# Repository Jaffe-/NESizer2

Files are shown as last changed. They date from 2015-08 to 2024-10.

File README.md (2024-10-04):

NESIZER

## NESizer2: 2A03 Synthesizer Project



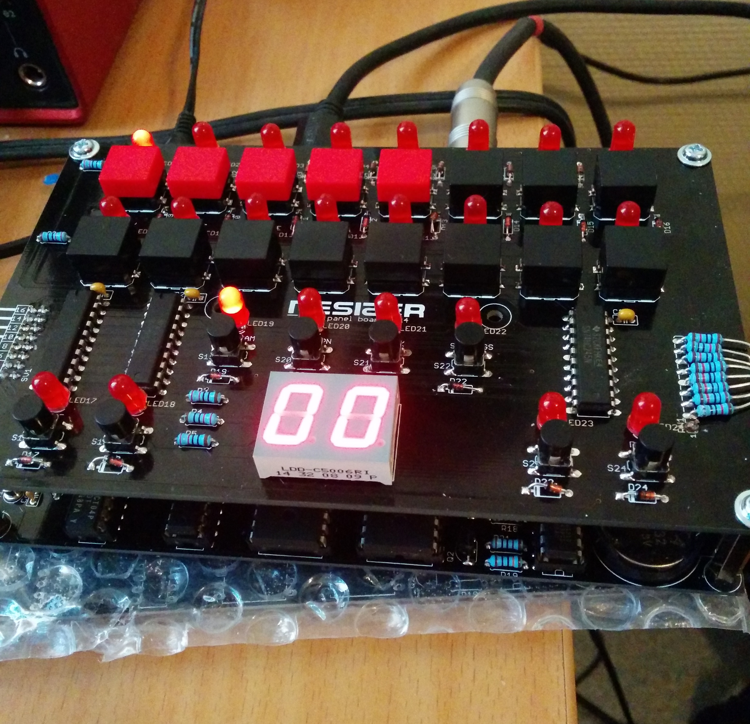
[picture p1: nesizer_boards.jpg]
NESIZER


The main idea of this project is to use an isolated NES 2A03 CPU/APU IC as a stand-alone synthesizer, controlled by an Atmel Atmega microcontroller. (The project is named NESizer2 after a failed attempt to create a NES synthesizer using only the 2A03 alone, with its own ROM, RAM and I/O logic.)

The 2A03 IC consists of a 6502 CPU core (with some minor changes), a DMA controller and the Audio Processing Unit. The APU is controlled via 22 registers, which are connected internally to the 6502 only; there are no external input pins facilitating communication with the APU directly. This means that in order to control the APU, the 6502 must act as a proxy: The microcontroller must send the 6502 instructions to take a value and put it in a desired APU register.

This project is inspired by a similar approach taken here: http://www.soniktech.com/tsundere/, but the idea here is to have the microcontroller communicate more directly with the 2A03, with a minimum of circuitry to do so.

Check out the most recent demo [here](https://www.youtube.com/watch?v=pXKrs0bFvvk)!

See the documentation for a description of how the NESizer works:

- [Hardware documentation](docs/hardware.md)
- [Software documentation](docs/software.md)

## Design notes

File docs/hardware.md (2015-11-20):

## Hardware

The following images shows the most current schematics.

Main board:
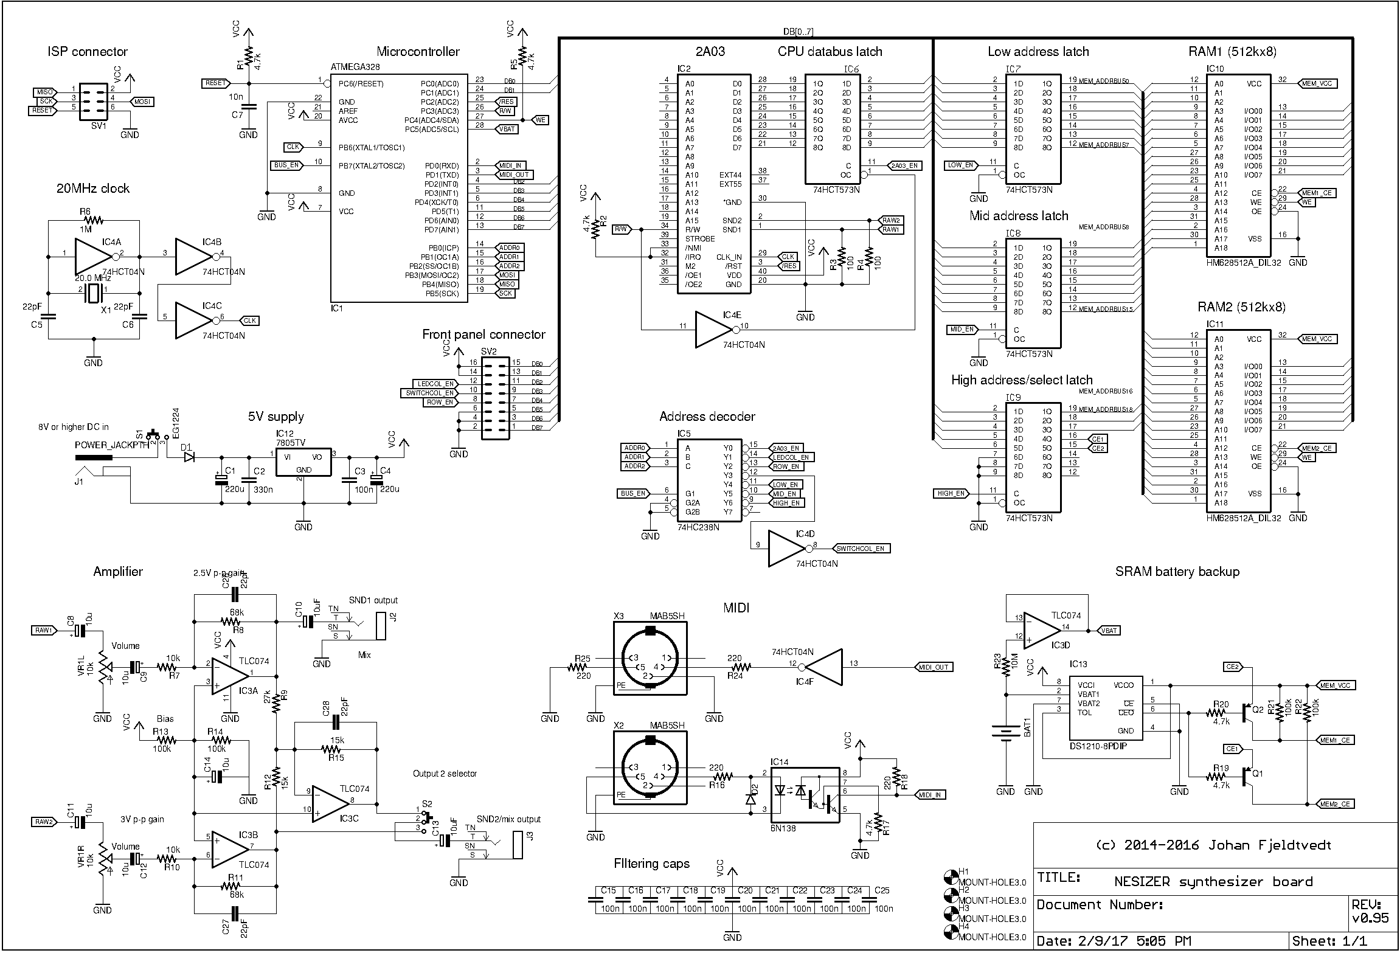
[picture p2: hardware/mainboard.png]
Main board


Front panel board:
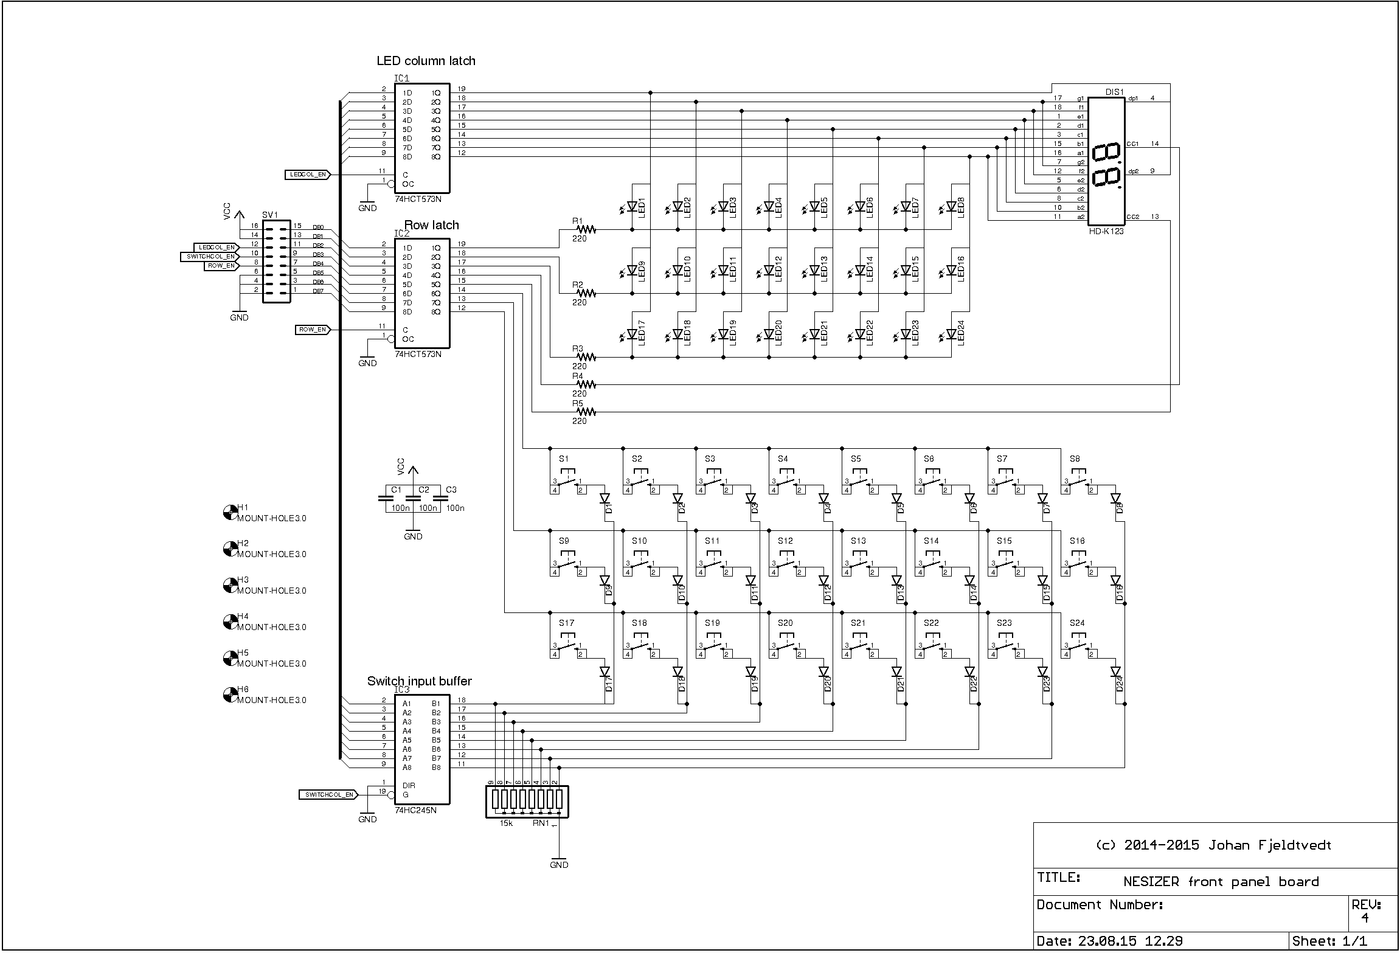
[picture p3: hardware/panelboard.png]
Panel board


The circuit essentially consists of the following parts:

- Atmega328 microcontroller
- 2A03
- LED matrix
- Switch matrix
- Battery backed SRAM
- Analog signal amplifier

#### Communication

The Atmega accesses the 2A03, LED matrix, switch matrix and SRAM through a simple bus system consisting of a 3-bit address bus and an 8-bit data bus. Bits 0, 1 and 2 of **PORTB** are used as the address, while bits 0 and 1 of **PORTC** and bits 2 to 7 of **PORTD** are connected to the data bus. The odd choice of combining some bits from **PORTC** with some bits of **PORTD** is because bits 0 and 1 of **PORTD** are used by the USART which takes care of MIDI communication. A 74HC238 decoder is used to decode the 3-bit address into one of eight activation signals for each component. The addresses are decoded as follows (R and W indicate read or write direction, respectively):

- 0: 2A03 data bus (W) 
- 1: LED matrix column (W)
- 2: matrix row for both LED and switch matrices (W)
- 3: switch matrix column (R)
- 4: memory, low 8 bits of address (W)
- 5: memory, middle 8 bits of address (W)
- 6: memory, high 3 bits of address and chip select bits (W)

Each writable component is connected to the databus via a latch in order to store the value when the bus is being used for something else.

#### 2A03 setup

Both the Atmega and the 2A03 are clocked by a 20 MHz crystal oscillator circuit based on 74HC04 inverters. The 2A03 divides this clock by 12 internally to provide a 1.66 MHz clock for the 6502 and APU. This is a bit lower than the usual frequency for the 2A03 (1.79 MHz), but it has no serious impact on APU operation (the APU timer values needed to produce a given note become a bit different).

The Atmega is hooked up to the 2A03 using the following connections:

- **PD2** .. **PD7**  --->  74HC573 latch ---> **D2** .. **D7** on 2A03 
- **PC0** .. **PC1**  --->  74HC573 latch ---> **D0** .. **D1** on 2A03
- **PC2**  --->  **RESET** pin on 2A03
- **PC3**  <---  **R/W** pin on 2A03

The reset connection could possibly be omitted (and the 2A03 reset pin just connected to a standard reset circuit), but connecting it to the Atmega allows for the 2A03 to be reset at any time, which might be handy in case the 6502 should halt.

The **R/W** output from the 2A03 is necessary to synchronize with the CPU.

In addition to the connections to the Atmega, some other connections are necessary for the 2A03 to function properly:

- **/NMI** and **/IRQ** are pulled high to avoid interrupts disturbing the 6502
- Pin 30 (diagonistics pin) is pulled low
- **SND1** and **SND2** (APU outputs) are pulled low via 100 ohm resistors

The 100 ohm pull-down resistors on **SND1** and **SND2** are required for the DACs in the APU to function properly. (This also has the effect that the output signals are very weak.)

Apart from this and the usual power supply connections, there are no further connections made. The address bus and the gamepad inputs/outputs are simply left unconnected. 

#### LED and switch matrices

These are both pretty standard. The LED matrix is a column scan matrix with 8 columns and 5 rows. 

The switch matrix is a row scan matrix with 8 columns and 3 rows. The lower five bits of a 74HC573 latch are used to hold the selected LED row, and the upper three bits are used to hold the selected switch row. This latch is accessed through the data bus by selecting address 2. 

The LED column is specified by writing to a 74HC573 latch connected to the data bus and selected with address 1. (Note that in order to light an LED at row *x* and column *y*, a 1 must be written at bit position *y* in the column latch, while a 0 must be written to bit position *x* of the row latch. This is because the column latch is sourcing the current while the row latch is sinking it.) 

Reading a switch state is done by activating the correct row in the row latch, and then selecting address 3 and reading from the bus. 

#### Battery backed SRAM memory

There are two SRAM ICs of 512KByte each, thus a 20 bit address is needed to address each individual byte (1MB in total). Since the databus is only 8 bit wide, three latches are used to specify an address before reading or writing to memory. The lowest 8 bits are written to the latch at databus address 4, the next 8 bits to the latch at address 5, and the next three bits to the latch at address 6. This totals to 19 bits, enough to address any byte in one of the ICs. The desired chip is selected by the upper two bits of the high address latch, where a value of 0b10 selects the first, 0b01 the other, and 0b11 neither. 

The write enable (/WE) line of the SRAM ICs is connected to pin 4 of **PORTC**. This pin must be kept high at all times except when a write is to performed. When an address is set up and a desired value is put on the databus, this pin is pulled low and thereafter pulled high to write the value to the address in memory. 

The SRAM ICs will retain their data as long as their supply voltage is larger than 1.5 V and the chip select lines are held high. The battery backup circuit takes care of this. A constant supply voltage is supplied by either a 3 V coin cell battery, or the regulated 5 V supply when the NESizer is powered on. The supplies are connected through diodes to prevent the 5 V supply from being applied to the battery, and to minimize the current flowing out of the battery when the 5 V supply is off.

A simple transistor switch circuit is used to force the chip select lines high when the 5 V supply is turned off. R19 and R20 set up a resistive divider giving a base voltage of the transistors that is about 0.15 * VCC. Assuming a typical VBE drop of 0.6 V, this gives a threshold of about 4 V for the transistor to start turning on. The pullups R21 and R22 ensure that the chip enable outputs are tied to MEM_VCC when the transistors are off. As the transistors are turned on, the outputs will follow the inputs closely, with a small drop between the emitter and collector.

#### MIDI

The MIDI input circuit is the standard circuit suggested in the MIDI standard, using an optocoupler (6N138) to isolate the MIDI current loop from the circuit. The incoming signal goes to the RX input of the Atmega's USART.

#### Output audio path

There are two identical output paths for the two 2A03 sound outputs, and a mixer that mixes the two audio signals with approximately the same ratio as in the NES.

The signal is AC-coupled by C8, C11 to the volume potentiometers set up as voltage dividers (VR1L, VR1R). The AC coupling is necessary to avoid noises when turning the volume potentiometers. It is then AC coupled by C9, C12 in to the virtual ground of an inverting amplifier with a gain of -6.8 set up by R8/R7 and R11/R10.  The non-inverting input of the op-amps IC3A, IC3B is set by a voltage divider to 2.5 V, so the output voltage is 2.5 V - 6.8 * v_in. In the feedback loop capacitors C26, C27 stabilize and also set the upper corner frequency of the bandwidth. The mix is done by passively summing the two resulting signals at the virtual ground of a third inverting amplifier. This ensure minimal crossbleed between the two output paths.

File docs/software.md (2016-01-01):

## Software

#### Databus communication

`bus.h` contains utility macros for using the bus system. The target component is adressed using `bus_select(<address>)`. A value is put on the bus using `bus_write(<value>)`. Changing bus direction to input or output is done by `bus_dir_input()` and `bus_dir_output()`, respectively. Values are read from the bus using `bus_read()`. `bus_deselect()` will disable the currently selected component.

`bus.h` also defines names for the adresses:

* 2A03: `CPU_ADDRESS`
* LED column: `LEDCOL_ADDRESS`
* Row (for both LEDs and switches): `ROW_ADDRESS`
* Switch column: `SWITCHCOL_ADDRESS`
* SRAM low address: `MEMORY_LOW_ADDRESS`
* SRAM mid address: `MEMORY_MID_ADDRESS`
* SRAM high address: `MEMORY_HIGH_ADDRESS`

The bus system must be initialized with `bus_setup()` before first time use.

#### Communication with the 2A03

The 2A03 is kept idle by continuously holding 0x85, the opcode for `STA` (with zero page addressing), on the databus. The CPU thus continuously executes an `STA $85` instruction. 

The reason for using this opcode instead of the more obvious `NOP` is to be able to synchronize with the CPU when a new instruction is to be sent. This synchronization is done by monitoring the **R/W** line of the 2A03. When it goes low, the 6502 is writing to memory. This *only* happens when the `STA $85` instruction is in its third cycle, which means that the next cycle will be the fetch of the next opcode. The Atmega then has a very narrow window to prepare and write the values to the 6502. Because of the precision needed, this is done by cycle exact assembly code in `2a03_io.s`.

Writing to APU registers is done by calling the function `io_register_write`. It selects the 2A03 address, blocks any interrupts and calls the assembly function `register_setN`, where N is one of three possible 2A03 clock divisors (12, 15 or 16, more about this below). This function makes the 6502 perform the following series of instructions:

    LDA #VALUE		0xA9 VALUE
    STA $40RR		0x8D 0xRR 0x40

where 0xRR is the low byte of the register address to be written to. At the end, `register_setN` puts the `STA` zero page opcode (0x85) back on the bus to keep the CPU busy until the next time something needs to be written.

There are also functions `reset_pcN` and `disable_interruptsN` in `2a03_io.s` for resetting the `PC` register and disabling interrupts on the 6502, respectively. `disable_interruptsN` executes an `SEI` instruction on the 6502 and is done once on boot. `reset_pcN` executes a `JMP $8585` instruction. It is called periodically to make sure that the 6502's program counter (`PC` register) doesn't overflow and run into the addresses where the APU registers are mapped (in which case APU register contents will be interpreted as instructions).

##### Different 2A03 varieties

The NESIZER supports three different kinds of chips: 2A03, 2A07 (PAL version) and Dendy clones. The most critical difference is the internal clock divider used: The 2A03 divides its clock input by 12, while the 2A07 divides by 16 and the Dendy clones by 15. An assembly function `detect` is used to determine which type of chip is being used. It puts an `STA` instruction with absolute addressing on the bus and uses one of the Atmega's timers to count how long two such instructions take to execute. The timer is being clocked by the Atmega's main clock, so its value will be proportional to how many Atmega cycles each 6502 cycle takes. Since two `STA` instructions with absolute addressing take 8 6502 cycles to complete, dividing the timer's value by 8 yields how many Atmega cycles there are in one 6502 cycle.

When the NESIZER boots, `detect` is run, and the result is used to make the function pointers `register_set`, `reset_pc` and `disable_interrupts` point to the correct functions in `2a03_io.s`. It is also used to select which table of timer values to use in `periods.c`.

#### Calculating period values for APU channels

This is detailed in [periods.pdf](periods.pdf).

#### APU abstaction layer

The APU abstraction layer (`apu`) contains structs and functions for manipulating the 2A03 channels in a high level manner without having to deal with register writes manually. The channels are represented by structs having fields corresponding to each (used/interesting) parameter of the channel. 

Each channel type is represented by a struct, `square`, `triangle`, `noise` and `dmc`, respectively. Global objects `sq1`, `sq2`, `tri`, `noise` and `dmc` of corresponding types are defined. Each channel has a setup function named `<channel>_setup`, intended for initializing the struct, and an update function `<channel>_update` which takes the data in a struct and fills the appropriate registers in a register buffer. The function `apu_refresh_channel` takes the data for a given channel in the register buffer and writes them to the 2A03. This function updates one channel's registers at a time, so it needs to be called 5 times to update all registers. This is necessary to reduce time spent on register updates.

The abstraction makes producing sound easy: 

	int main() 
	{
		// Initialize 2A03:
		io_setup();
		
		// Initialize Square 1 channel:
		sq1_setup();
		
		// Set the values for period, duty cycle and volume:
		sq1.enabled = 1;
		sq1.period = 400;
		sq1.duty = 2;
		sq1.volume = 15;
		
		// Update APU register buffer with new square 1 values:
		sq1_update();
		
		// Transfer changes to the APU:
		apu_refresh_channel(CHN_SQ1);
		
		// Wait indefinitely
		while(1);
	}

#### Interrupt timing and task handler

One of the Atmega's timers is used to generate an interrupt at approximately 16 kHz. This interrupt provides the basic timing used by various subsystems (LFOs, envelopes, APU updates, etc.).

A simple task handler (`task.h`, `task.c`) is used to sequence tasks to be performed. Tasks are registered with a desired frequency and a time delay to spread tasks out in time. 

#### LEDs and switches

These are handled in `leds.c`, `leds.h` and `input.c`, `input.h`. 

LED states are held in a 5 byte array `leds`. The function `leds_refresh` is intended to be registered as a task, and will update one column of the LED array each time it is called. It is intended to be run often enough for the sequential updating to happen unnoticed. 

Switch states are held in a 3 byte array `input`. The function `input_refresh` reads one row of switch data at a time and updates `input` accordingly. It is intended to be registered as a task and executed often enough for input to be seamless. 

#### SRAM

Functions for using the SRAM are available in `memory.c`, `memory.h`. Even though addresses are represented by 19 bits and two bits for chip selection at the hardware level, these details are glossed over by the software memory interface; an address is 20 bits, giving a total address space of 0 - 0xFFFFF. The internal function `set_address` translates a 20-bit address to the corresponding 19 bits and chip select bits.

The functions `memory_write()` and `memory_read()` are used to read and write bytes, while corresponding functions `read_word`, `read_dword`, `write_word` and `write_dword` are used to read or write 16- and 32-bit values. 

##### Sequential access

In order to reduce the time spent on memory operations, especially when playing back samples, a memory address can be set once using `memory_set_address()` and then values can be read or written sequentially using `memory_read_sequential()` and `memory_write_sequential()`, with as few address updates as possible (most often only the 8 lowest bits need to be changed). To make this work with several tasks using the memory, each task doing sequential memory access has to keep their own *memory context*, an object of type `struct memory_context`, whici holds the three (low, middle, high) memory latch bytes. `memory.c` keeps track of the last used memory context, so that when `memory_read_sequential` or `memory_write_sequential` is called, it makes sure that the task continues its memory access where it left off even if some other task changed the address in between. 

#### MIDI

Low level MIDI communication is implemented in `midi_io.c`, `midi_.h`. The Atmega's USART takes care of receiving MIDI data. In the function `midi_io_setup`, the USART is configured to use 1 start bit, 8 data bits and 1 stop bit, and to use a baud rate of 31250, which is the MIDI standard baud rate. 

The function `midi_io_handler` is intended to be registered as a task handler. It checks the state of the Atmega's USART receive buffer and reads new data into a ring buffer. 

Reading and interpreting the data is done by the functions in `midi.c`, `midi.h`.

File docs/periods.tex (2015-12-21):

\documentclass{article}
\usepackage[utf8]{inputenc}
\usepackage{listings}
%\usepackage[T1]{fontenc, url}
\usepackage[parfill]{parskip}

\setlength{\parindent}{0pt}

\title{NESIZER: Period calculations}
\date{}

\begin{document}

\maketitle

This document describes how period calculations are done effectively in the NESIZER code.

\section*{Note representation}

A \emph{note} is represented by a 16-bit value of the following struct (it is wrapped in a union to allow writing a raw value directly):

\begin{lstlisting}[language=C]
union tone {
  uint16_t raw_value;
  struct { 
    uint8_t offset : 6;
    uint16_t semitone : 10;
  } __attribute__((packed));
};
\end{lstlisting}

The upper 10 bits are used to represent the semitone, while the lower 6 bits represent the \emph{offset} from this semitone towards the next. The resulting frequency is given by

\begin{equation}
  f = f_{s} \cdot 2^{\frac{1}{12} \cdot \frac{o}{64}},
\label{eq_repr}
\end{equation}
where $f_s$ is the semitone's frequency and $o$ is the offset. 

\section*{Calculating timer values}

The formula used for calculating timer values from this note representation is based on the following relationship between timer values and resulting frequencies in the pitched APU channels:

$$f = \frac{f_{cpu}}{16 \alpha (T + 1)},$$

where $\alpha = 1$ for square channels and $\alpha = 2$ for the triangle channel. This relationship comes directly from the fact that each timer countdown advances one step of the generated waveform, and square waves take 16 steps while triangle waves take 32 steps.  

Solving this for $T$, we get
$$T = \frac{f_{cpu}}{16 \alpha f} - 1.$$

Inserting the relationship in (\ref{eq_repr}), we get

\begin{eqnarray*}
  T &=& \frac{f_{cpu}}{16 \alpha f_{s} \cdot 2^{\frac{1}{12} \cdot \frac{o}{64}}} - 1\\
  &=& \frac{f_{cpu}}{16 \alpha f_s} \cdot 2^{-\frac{1}{12} \cdot \frac{o}{64}} - 1\\
  &=& (T_s + 1) \cdot 2^{-\frac{1}{12} \cdot \frac{o}{64}} - 1.
\end{eqnarray*}

From here we see that $T_s$ -- the timer value required to give the semitone with frequency $f_s$ -- can easily be looked up in a table. To calculate the power of 2, a simple linear approximation has been found to be good enough:

$$2^{-\frac{1}{12} \cdot \frac{o}{64}} = [2^{-\frac{1}{12}}]^{\frac{o}{64}} \approx 1 - (1 - 2^{-\frac{1}{12}}) \cdot \frac{o}{64} \approx 1 - 0.00087696 \cdot o.$$

Using this approximation in the above expression for $T$, we get

$$T = (T_s + 1) (1 - 0.00087696 \cdot o) - 1.$$

This only involves one floating point multiplication and performes very well. 

\end{document}

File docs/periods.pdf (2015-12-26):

# NESIZER: Period calculations

This document describes how period calculations are done effectively in the NESIZER code.

## Note representation

A note is represented by a 16-bit value of the following struct (it is wrapped in a union to allow writing a raw value directly):

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

The upper 10 bits are used to represent the semitone, while the lower 6 bits represent the offset from this semitone towards the next. The resulting frequency is given by

| | f = fs · 2

1
12 ·

o
64 , | (1)

where fs is the semitone’s frequency and o is the offset.

## Calculating timer values

The formula used for calculating timer values from this note representation is based on the following relationship between timer values and resulting frequencies in the pitched APU channels:

f =

fcpu
16α(T + 1),

1

where α = 1 for square channels and α = 2 for the triangle channel. This relationship comes directly from the fact that each timer countdown advances one step of the generated waveform, and square waves take 16 steps while triangle waves take 32 steps.

Solving this for T, we get

T =

fcpu
16αf − 1.

Inserting the relationship in (1), we get

T =

fcpu
16αfs · 2

1
12 ·

o
64

− 1

=

fcpu
16αfs
- 2

− 1
12 ·

o
64 − 1

= (Ts + 1) · 2

− 1
12 ·

o
64 − 1.

From here we see that Ts – the timer value required to give the semitone with frequency fs – can easily be looked up in a table. To calculate the power of 2, a simple linear approximation has been found to be good enough:

2

− 1
12 ·

o

64 = [2⁻ 1
12 ]

o
64 ≈ 1 − (1 − 2

− 1
12 ) ·

o
64

≈ 1 − 0.00087696 · o.

Using this approximation in the above expression for T, we get

T = (Ts + 1)(1 − 0.00087696 · o) − 1.

This only involves one floating point multiplication and performes very well.

2

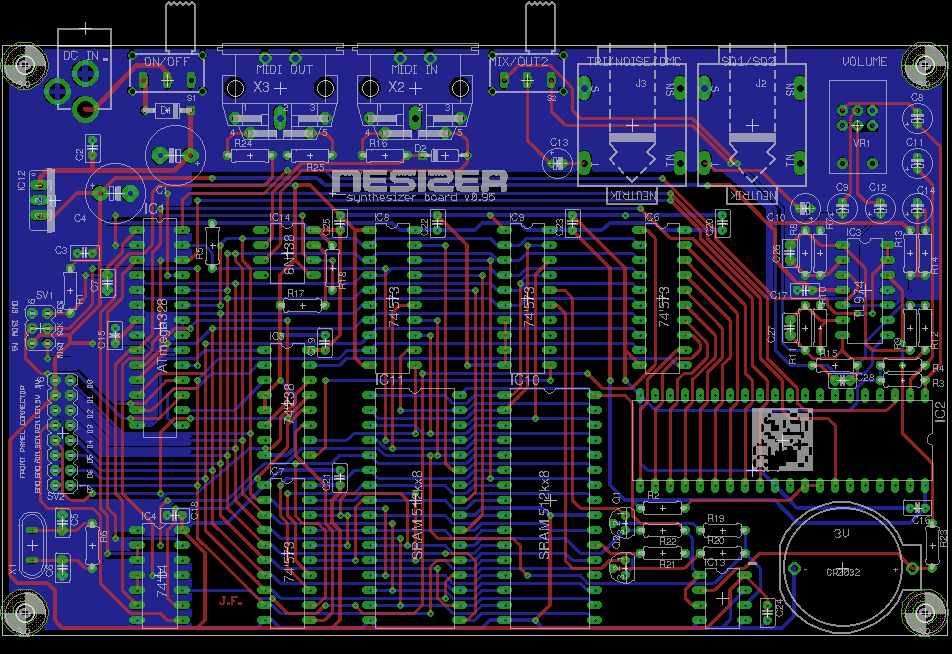
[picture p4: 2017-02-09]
hardware/mainboard_pcb.png

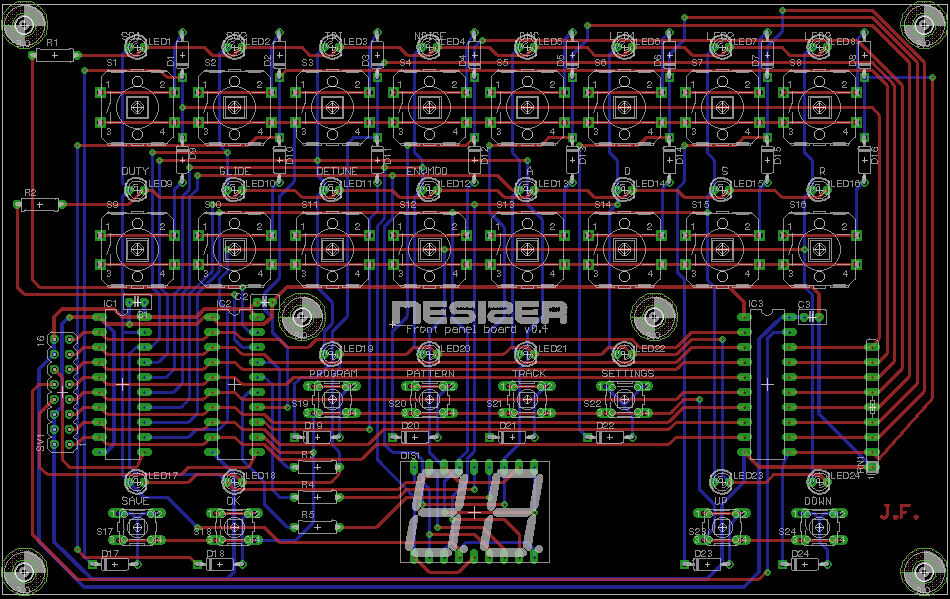
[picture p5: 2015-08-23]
hardware/panelboard_pcb.png

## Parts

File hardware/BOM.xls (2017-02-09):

Main board
Identifier | Component | Value | Qty | Comments | Mouser part
BAT1 | Battery holder |  | 1 | CR2032 | 122-2420-GR
C1, C4 | Electrolytic capacitor | 220u | 2 |  | 647-UPW1H221MPD
C2 | Capacitor | 330n | 1 |  | 75-1C20Z5U334M050B
C3, C15 – C25 | Capacitor | 100n | 12 |  | 75-1C10Z5U104M050B
C5, C6, C26 – C28 | Ceramic capacitor | 22p | 5 |  | 594-CN15A220J
C7 | Capacitor | 10n | 1 |  | 75-1C10Z5U103M050B
C8 – C14 | Electrolytic capacitor | 10u | 7 |  | 647-UKW1H100MDD
D1 | 1N4001 |  | 1 | Power diode | 625-1N4001E-E3/54
D2 | 1N4148 |  | 1 | Switching diode | 78-1N4148
IC1 | Atmega328 |  | 1 | Microcontroller | 556-ATMEGA328P-PU
IC2 | 2A03/2A07/6527P |  | 1 | 2A03/2A07 or clone
IC3 | TLC074 |  | 1 | Should have high Zin | 595-TL974IN
IC4 | 74HC04N |  | 1 | Hex inverter | 595-SN74HC04N
IC5 | 74HC238N |  | 1 | Address decoder | 595-CD74HC238EE4
IC6 – IC9 | 74HC573N |  | 4 | Latch | 595-SN74HC573AN
IC10, IC11 | AS6C4008 |  | 2 | 512k x 8 SRAM | 913-AS6C4008-55PCN
IC12 | LM7805 |  | 1 | Voltage regulator | 511-L7805CV
IC12 | Heatsink for LM7805 |  | 1 |  | 532-574102B00
IC13 | DS1210 |  |  | NV memory controller | 700-DS1210
IC14 | 6N138 |  | 1 | Optocoupler | 859-6N138M
J1 | DC jack 2.5mm |  | 1 |  | 163-7620E-E
J2, J3 | Mono jack 6.3mm |  | 2 |  | 550-10201
R1, R2, R5, R17, R19, R20 | Resistor | 4.7k | 6 |  | 594-MBB02070C4701FCT
R3, R4 | Resistor | 100 | 2 |  | 594-MBB02070C1000FCT
R6 | Resistor | 1M | 1 |  | 594-MBB02070C1004FCT
R7, R10 | Resistor | 10k | 2 |  | 594-MBB02070C1002FCT
R8, R11 | Resistor | 68k | 2 |  | 594-MBB02070C6802FCT
R9 | Resistor | 27k | 1 |  | 594-MBB02070C2702FC1
R12, R15 | Resistor | 15k | 2 |  | 594-MBB02070C1502FCT
R13, R14, R21, R22 | Resistor | 100k | 4 |  | 594-MBB02070C1003FCT
R16, R18, R24, R25 | Resistor | 220 | 4 |  | 594-MBB02070C2200FCT
R23 | Resistor | 10M | 1 |  | 594-MBB02070C1005FCT
S1, S2 | EG1224 |  | 2 | Slide switch | 612-EG1224
SV1 | 2x3 header |  | 1 | 2.54mm spacing | 517-9612065604AR
SV2 | 2x8 header |  | 1 | 2.54mm spacing | 649-68602-116HLF
SV2 | 8x1 header pins |  | 2 | Extensions to reach top board | 992-8FX1L-254MM
Q1, Q2 | BC557 or equivalent |  | 2 | PNP transistor | 512-BC557BTA
VR1 | Potentiometer | 10k | 1 | Audio taper | 688-RK09712200MC
X1 | Crystal | 20MHz | 1 |  | 815-ABL-20-B2
X2, X3 | MIDI socket |  | 2 |  | 502-57PC5F
 | 25mm spacers |  | 4 | Supports for top board | 855-R30-9402500
 | M3 screws |  | 8 | Screws for top board | 608-RM3X8MM
Extras
IC1 | 28 pin IC socket |  | 1 |  | 575-199328
IC2 | 40 pin IC socket |  | 1 |  | 517-4840-6000-CP
IC3, IC4 | 14 pin IC socket |  | 2 |  | 517-4814-3000-CP
IC5 | 16 pin IC socket |  | 1 |  | 517-4816-3000-CP
IC6 – IC9 | 20 pin IC socket |  | 4 |  | 517-4820-3000-CP
IC10, IC11 | 32 pin IC socket |  | 2 |  | 517-4832-6000-CP
IC14 | 8 pin IC socket |  | 2 |  | 517-4808-3000-CP
Top / front panel board
Identifier | Component | Value | Qty | Comments | Mouser part
C1 – C3 | Capacitor | 100n | 3 |  | 75-1C10Z5U104M050B
D1 – D24 | 1N4148 |  | 24 | Switching diode | 78-1N4148
DIS1 | 7-segment display |  | 1 | Two digits, common cathode | 696-LDD-C5006RI
IC1, IC2 | 74HC573N |  | 2 | Latch | 595-SN74HC573AN
IC3 | 74HC245N |  | 1 | Buffer / bus driver | 595-SN74HCT245N
LED1 – LED24 | 3mm LED |  | 24 |  | 696-LX3044ID-24117
R1 – R5 | Resistor | 220 | 5 | Adjust for LED current | 594-MBB02070C2200FCT
RN1 | 8x resistor array, bussed | 15k | 1 |  | 858-L091S472LF
S1, S16 | Omron B3F 12mm switch |  | 16 | With plunger top | 653-B3F-4050
S17 – S24 | Omron B3f 6mm switch |  | 8 | With plunger top | 653-B3F-1050
SV1 | 8x2 female header |  | 1 | Mount on underside of PCB! | 517-929975-01-08-RK
Extras
IC1 – IC3 | 20 pin IC socket |  | 3 |  | 517-4820-3000-CP
S1 – S5 | 12mm square cap, red |  | 5 | For channel buttons | 653-B32-1380
S6 – S16 | 12mm square cap, black |  | 11 | For parameter buttons | 653-B32-1310
S17 – S24 | 6mm round cap, black |  | 8 | For up/down, mode, etc. | 653-B32-2010

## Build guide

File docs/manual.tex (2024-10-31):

\documentclass[a4paper, 12p]{extarticle}
\usepackage[centering, margin=3.0cm]{geometry}
\usepackage{cmbright}
\usepackage{graphicx}
\usepackage[intlimits]{amsmath}
\usepackage{amssymb}
\usepackage{amsthm}
\usepackage{parskip}
\usepackage{pgf}
\usepackage{tikz}
\usetikzlibrary{shapes}
\usetikzlibrary{positioning}
\usetikzlibrary{calc}
\usepackage{enumerate}
\usepackage{framed}
\usepackage{tikz}

\setcounter{secnumdepth}{0}

\newcommand \name {NESIZER }
\newcommand {\btn}[1] {\framebox{\textbf{\footnotesize #1}}}
\newcommand {\cbtn}[1] {\tikz \node[draw,circle]{\textbf{\footnotesize #1}};}
\newcommand {\lbl}[1] {\emph{\footnotesize #1}}
\newcommand \dsp \texttt

\AddToHook{cmd/section/before}{\clearpage}

\title{NESIZER}
\author{}
\date{}

\begin{document}

\definecolor{buttonredh}{RGB}{255,0,0}
\definecolor{buttonred}{RGB}{240, 161, 161}
\definecolor{buttongray}{RGB}{71,71,71}

\tikzstyle{mbutton}=[font=\tiny,rectangle, draw, fill=buttonred, text=gray, minimum height=1.2cm, minimum width=1.2cm]
\tikzstyle{mhbutton}=[font=\tiny,rectangle, draw, fill=buttonredh, minimum height=1.2cm,minimum width=1.2cm]

\tikzstyle{hbutton}=[font=\tiny,rectangle, draw, fill=black, text=white, minimum height=1.2cm, minimum width=1.2cm]
\tikzstyle{button}=[font=\tiny,rectangle, draw, fill=buttongray, text=gray, minimum height=1.2cm,minimum width=1.2cm]

\tikzstyle{dummybutton}=[font=\tiny,rectangle, fill=white, text=white, minimum height=1cm,minimum width=1cm]
\tikzstyle{hcircbutton}=[font=\tiny,circle, fill=black, text=white, minimum height=1.2cm,minimum width=1.2cm]
\tikzstyle{circbutton}=[font=\tiny,circle, fill=buttongray, text=gray, minimum height=1.2cm,minimum width=1.2cm]
\tikzstyle{selcircbutton}=[font=\tiny,circle,line width=0.7mm,draw=green!80, fill=black, text=white, minimum height=1.2cm,minimum width=1.2cm]

\begin{titlepage}
  \begin{center}
    \vfil
    \\[3cm]

    \textsc{\LARGE{8-bit synthesizer}}\\[8cm]

    \textsc{\Large{Operating manual}}
  \end{center}
\end{titlepage}

\tableofcontents

%\maketitle

\section{The NESIZER}

\subsection{Sound channels}

At the heart of the \name is the NES APU chip, usually called 2A03 (or 2A07 if you use a chip from the PAL NES). The APU has five separate sound channels:

\begin{itemize}
\item \textbf{SQ1} and \textbf{SQ2}: These produce square waves with three selectable \emph{duty cycles} (pulse widths).
\item \textbf{TRI}: This channel produces triangular waves, but with a low 4 bit amplitude resolution. This results in the characteristic aliased NES bass and flute tones.
\item \textbf{NOISE}: This channel produces various forms of noise. The noise can be white noise, or pitched noise if the \lbl{LOOP} mode is engaged.
\item \textbf{DMC}: This channel can output 7-bit samples at a quick rate. The sampling rate is 16 kHz in the \name.
\end{itemize}

\subsection{Modulation}

Because the 2A03 is put under much tighter control in the \name than in a NES or Famicom console, the \name features extensive modulation capabilities.

\begin{itemize}
\item Three separate low frequency oscillators \textbf{LFO1}, \textbf{LFO2}, \textbf{LFO3} with selectable waveforms (ramp up, ramp down, sine wave, triangle wave or square wave)
\item Dedicated ADSR envelope generators for the square and noise channels
\item Portamento / glide for the square and triangle channels
\end{itemize}

\section{PROGRAM and PAGE 2 modes}

This is the active mode when the \name starts up. When in other modes, press the \btn{PROGRAM} button to switch to this mode.

In the programming mode, the various parameters of the sound channels and LFOs can be changed. A set of channel and LFO settings are collectively known as a \emph{patch}. The \name can save patches to memory, and has room for 100 patches.

\begin{tikzpicture}[align=center, node distance=1.5cm, auto]
  \node(scope1) {
    \begin{tikzpicture}
      \node [mhbutton] (1) {SQ1};
      \node [mhbutton, right of=1] (2) {SQ2};
      \node [mhbutton, right of=2] (3) {TRI};
      \node [mhbutton, right of=3] (4) {NOISE};
      \node [mhbutton, right of=4] (5) {DMC};
      \node [hbutton, right of=5] (6) {LFO1};
      \node [hbutton, right of=6] (7) {LFO2};
      \node [hbutton, right of=7] (8) {LFO3};

      \node [hbutton, below=1] (9) {};
      \node [hbutton, right of=9] (10) {};
      \node [hbutton, right of=10] (11) {};
      \node [hbutton, right of=11] (12) {};
      \node [hbutton, right of=12] (13) {};
      \node [hbutton, right of=13] (14) {};
      \node [hbutton, right of=14] (15) {};
      \node [hbutton, right of=15] (16) {};
    \end{tikzpicture}
  };

  \node[at={($(scope1.south)$)},anchor=north] (scope2) {
    \begin{tikzpicture}
      \node [dummybutton] (1) {};
      \node [dummybutton, right of=1] (2) {};
      \node [selcircbutton, right of=2] (3) {PROGRAM};
      \node [selcircbutton, right of=3] (4) {PAGE 2};
      \node [circbutton, right of=4] (5) {SEQ.};
      \node [circbutton, right of=5] (6) {SETTINGS};
      \node [dummybutton, right of=6] (7) {};
      \node [dummybutton, right of=7] (8) {};

      \node [hcircbutton, below=0.1cm of 1] (9) {CLEAR};
      \node [hcircbutton, right of=9] (10) {SAVE};
      \node [dummybutton, right of=10] (11) {};
      \node [dummybutton, right of=11] (12) {};
      \node [dummybutton, right of=12] (13) {};
      \node [dummybutton, right of=13] (14) {};
      \node [hcircbutton, right of=14] (15) {UP};
      \node [hcircbutton, right of=15] (16) {DOWN};
    \end{tikzpicture}
  };
\end{tikzpicture}

\subsection{Loading patches}
To load a patch, press either \btn{UP} or \btn{DOWN}. To go quickly up or down, press and hold the respective button. The current patch number is shown on the numeric display. Patches can also be loaded using MIDI Program Change or short SysEx messages (see MIDI section).

\subsection{Saving patches}
To save a patch, press \btn{SAVE}. The button will start to blink to indicate that you can select where to store the new patch. Use \btn{UP} and \btn{DOWN} to select where to store the patch. Press \btn{SAVE} again to store the patch at the selected location.

\emph{Note: When channel and LFO settings are changed, these are not saved until you press \btn{SAVE}.}

\subsection{Enabling and disabling channels}
To enable or disable a channel, press the corresponding channel button. When a channel is disabled, it does not produce sound when being triggered by the sequencer or incoming MIDI data.

\subsection{PAGE 2}

By pressing \btn{PAGE 2}, a second ``page'' og parameters become available. Some of them are channel parameters, and others are related to note assignment. When Page 2 is selected, the \name is still in programming mode, so pressing \btn{UP} or \btn{DOWN} will change the current patch, and will discard any changes that haven't been saved. The parameters that are avilable in page 2 are shown in yellow color in the figures below.

\subsection{Changing channel parameters}
To change a channel's parameter, press and hold the desired channel's button, and the desired parameter button. For example, to change the attack of the square 1 channel, press \btn{SQ1} and \btn{A}. The button LEDs will start to blink to indicate which channel parameter is being changed. Use the \btn{UP} and \btn{DOWN} buttons to change the parameter value. When you have the desired value, press \btn{SAVE}.

\subsubsection{Square channels}

\begin{tikzpicture}[align=center, node distance=1.5cm and 0.5cm]
  \node [mhbutton] (1) {SQ1};
  \node [mhbutton, right of=1] (2) {SQ2};
  \node [mbutton, right of=2] (3) {TRI};
  \node [mbutton, right of=3] (4) {NOISE};
  \node [mbutton, right of=4] (5) {DMC};
  \node [hbutton, right of=5] (6) {LFO1\\[4]\textcolor{yellow}{BEND}};
  \node [hbutton, right of=6] (7) {LFO2\\[4]\textcolor{yellow}{ENV MOD}};
  \node [hbutton, right of=7] (8) {LFO3\\[4]\textcolor{yellow}{VOL MOD}};

  \node [hbutton, below=1] (9) {DUTY\\[4]\textcolor{yellow}{SPLIT HALF}};
  \node [hbutton, right of=9] (10) {DETUNE};
  \node [hbutton, right of=10] (11) {OCTAVE};
  \node [hbutton, right of=11] (12) {GLIDE};
  \node [hbutton, right of=12] (13) {A};
  \node [hbutton, right of=13] (14) {D};
  \node [hbutton, right of=14] (15) {S};
  \node [hbutton, right of=15] (16) {R};
\end{tikzpicture}

\begin{tabular}{l | l | l}
  Parameter & Description & Range\\ \hline
  \textbf{LFO1} & Intensity of modulation by LFO1 & 0 - 99\\
  \textbf{LFO2} & Intensity of modulation by LFO2 & 0 - 99\\
  \textbf{LFO3} & Intensity of modulation by LFO3 & 0 - 99\\
  \textbf{DUTY} & Duty cycle & 0 - 3\\
  \textbf{DETUNE} & Detuning & -9 - 9\\
  \textbf{OCTAVE} & Octave & -4 - 4\\
  \textbf{GLIDE} & Portamento glide time & 0 - 99\\
  \textbf{A} & Volume envelope attack & 0 - 99\\
  \textbf{D} & Volume envelope decay & 0 - 99\\
  \textbf{S} & Volume envelope sustain & 0 - 15\\
  \textbf{R} & Volume envelope release & 0 - 99\\
  \textbf{BEND} (page 2) & Bend wheel intensity in semitones & 0 - 24\\
  \textbf{ENV MOD} (page 2) & Pitch envelope modulation amount & -9 - 9\\
  \textbf{VOL MOD} (page 2) & Volume modulation by LFO3 & 0 - 16\\
  \textbf{SPLIT HALF} (page 2) & See section 1.3.6 & Lower - Upper\\
\end{tabular}

\subsubsection{Triangle channel}

\begin{tikzpicture}[align=center, node distance=1.5cm and 0.5cm]
  \node [mbutton] (1) {SQ1};
  \node [mbutton, right of=1] (2) {SQ2};
  \node [mhbutton, right of=2] (3) {TRI};
  \node [mbutton, right of=3] (4) {NOISE};
  \node [mbutton, right of=4] (5) {DMC};
  \node [hbutton, right of=5] (6) {LFO1\\[4]\textcolor{yellow}{BEND}};
  \node [hbutton, right of=6] (7) {LFO2\\[4]\textcolor{yellow}{ENV MOD}};
  \node [hbutton, right of=7] (8) {LFO3};

  \node [hbutton, below=1] (9) {\textcolor{yellow}{SPLIT HALF}};
  \node [hbutton, right of=9] (10) {DETUNE};
  \node [hbutton, right of=10] (11) {OCTAVE};
  \node [hbutton, right of=11] (12) {GLIDE};
  \node [button, right of=12] (13) {};
  \node [button, right of=13] (14) {};
  \node [button, right of=14] (15) {};
  \node [button, right of=15] (16) {};
\end{tikzpicture}

\begin{tabular}{l | l | l}
  Parameter & Description & Range\\ \hline
  \textbf{LFO1} & Intensity of modulation by LFO1 & 0 - 99\\
  \textbf{LFO2} & Intensity of modulation by LFO2 & 0 - 99\\
  \textbf{LFO3} & Intensity of modulation by LFO3 & 0 - 99\\
  \textbf{DETUNE} & Detuning & -9 - 9\\
  \textbf{OCTAVE} & Octave & -4 - 4\\
  \textbf{GLIDE} & Portamento glide time & 0 - 99\\
  \textbf{BEND} (page 2) & Bend wheel intensity in semitones & 0 - 24\\
  \textbf{ENV MOD} (page 2) & Pitch envelope modulation (noise envelope) & -9 - 9\\
  \textbf{SPLIT HALF} (page 2) & See section 1.3.6 & Lower - Upper\\
\end{tabular}

\subsubsection{Noise channel}

\begin{tikzpicture}[align=center, node distance=1.5cm and 0.5cm]
  \node [mbutton] (1) {SQ1};
  \node [mbutton, right of=1] (2) {SQ2};
  \node [mbutton, right of=2] (3) {TRI};
  \node [mhbutton, right of=3] (4) {NOISE};
  \node [mbutton, right of=4] (5) {DMC};
  \node [hbutton, right of=5] (6) {LFO1\\[4]\textcolor{yellow}{BEND}};
  \node [hbutton, right of=6] (7) {LFO2\\[4]\textcolor{yellow}{ENV MOD}};
  \node [hbutton, right of=7] (8) {LFO3\\[4]\textcolor{yellow}{VOL MOD}};

  \node [hbutton, below=1] (9) {LOOP\\[4]\textcolor{yellow}{SPLIT HALF}};
  \node [button, right of=9] (10) {};
  \node [button, right of=10] (11) {};
  \node [button, right of=11] (12) {};
  \node [hbutton, right of=12] (13) {A};
  \node [hbutton, right of=13] (14) {D};
  \node [hbutton, right of=14] (15) {S};
  \node [hbutton, right of=15] (16) {R};
\end{tikzpicture}

\begin{tabular}{l | l | l}
  Parameter & Description & Range\\ \hline
  \textbf{LFO1} & Intensity of modulation by LFO1 & 0 - 99\\
  \textbf{LFO2} & Intensity of modulation by LFO2 & 0 - 99\\
  \textbf{LFO3} & Intensity of modulation by LFO3 & 0 - 99\\
  \textbf{LOOP} & Looped noise & on/off\\
  \textbf{A} & Volume envelope attack & 0 - 99\\
  \textbf{D} & Volume envelope decay & 0 - 99\\
  \textbf{S} & Volume envelope sustain & 0 - 15\\
  \textbf{R} & Volume envelope release & 0 - 99\\
  \textbf{BEND} (page 2) & Bend wheel intensity (in steps) & 0 - 15\\
  \textbf{ENV MOD} (page 2) & Pitch envelope modulation amount & -9 - 9\\
  \textbf{VOL MOD} (page 2) & Volume modulation by LFO3 & 0 - 16\\
  \textbf{SPLIT HALF} (page 2) & See section 1.3.6 & Lower - Upper\\
\end{tabular}

\subsubsection{DMC channel}

\begin{tikzpicture}[align=center, node distance=1.5cm and 0.5cm]
  \node [mbutton] (1) {SQ1};
  \node [mbutton, right of=1] (2) {SQ2};
  \node [mbutton, right of=2] (3) {TRI};
  \node [mbutton, right of=3] (4) {NOISE};
  \node [mhbutton, right of=4] (5) {DMC};
  \node [button, right of=5] (6) {LFO1};
  \node [button, right of=6] (7) {LFO2};
  \node [button, right of=7] (8) {LFO3};

  \node [hbutton, below=1] (9) {LOOP};
  \node [hbutton, right of=9] (10) {};
  \node [button, right of=10] (11) {};
  \node [button, right of=11] (12) {};
  \node [button, right of=12] (13) {};
  \node [button, right of=13] (14) {};
  \node [button, right of=14] (15) {};
  \node [button, right of=15] (16) {};
\end{tikzpicture}

\begin{tabular}{l | l | l}
  Parameter & Description & Range\\ \hline
  \textbf{LOOP} & Play samples in loop & on/off\\
  %\textbf{DIVIDER} & Divider for sample rate & 1 - 4\\
\end{tabular}

\subsubsection{LFOs}

\begin{tikzpicture}[align=center, node distance=1.5cm and 0.5cm]
  \node [mbutton] (1) {SQ1};
  \node [mbutton, right of=1] (2) {SQ2};
  \node [mbutton, right of=2] (3) {TRI};
  \node [mbutton, right of=3] (4) {NOISE};
  \node [mbutton, right of=4] (5) {DMC};
  \node [hbutton, right of=5] (6) {LFO1};
  \node [hbutton, right of=6] (7) {LFO2};
  \node [hbutton, right of=7] (8) {LFO3};

  \node [hbutton, below=1] (9) {WAVE};
  \node [button, right of=9] (10) {};
  \node [button, right of=10] (11) {};
  \node [button, right of=11] (12) {};
  \node [button, right of=12] (13) {};
  \node [button, right of=13] (14) {};
  \node [button, right of=14] (15) {};
  \node [button, right of=15] (16) {};
\end{tikzpicture}

\begin{tabular}{l | l | l}
  Parameter & Description & Range\\ \hline
  \textbf{WAVE} & LFO waveform & 1 - sine\\
  & & 2 - ramp up\\
  & & 3 - ramp down\\
  & & 4 - square\\
  & & 5 - triangle
\end{tabular}

\subsection{Note assignment}

\begin{tikzpicture}[align=center, node distance=1.5cm and 0.5cm]
  \node(scope1) {
    \begin{tikzpicture}
      \node [mhbutton] (1) {SQ1};
      \node [mhbutton, right of=1] (2) {SQ2};
      \node [mhbutton, right of=2] (3) {TRI};
      \node [mhbutton, right of=3] (4) {NOISE};
      \node [mhbutton, right of=4] (5) {DMC};
      \node [button, right of=5] (6) {LFO1};
      \node [button, right of=6] (7) {LFO2};
      \node [button, right of=7] (8) {LFO3};

      \node [hbutton, below=1] (9) {\textcolor{yellow}{SPLIT HALF}};
      \node [hbutton, right of=9] (10) {\textcolor{yellow}{SPLIT}\\\textcolor{yellow}{ON/OFF}};
      \node [hbutton, right of=10] (11) {\textcolor{yellow}{SPLIT}\\\textcolor{yellow}{SET POINT}};
      \node [button, right of=11] (12) {};
      \node [hbutton, right of=12] (13) {\textcolor{yellow}{LOWER}\\\textcolor{yellow}{POLY}};
      \node [hbutton, right of=13] (14) {\textcolor{yellow}{LOWER}\\\textcolor{yellow}{MONO}};
      \node [hbutton, right of=14] (15) {\textcolor{yellow}{(UPPER)}\\\textcolor{yellow}{POLY}};
      \node [hbutton, right of=15] (16) {\textcolor{yellow}{(UPPER)}\\\textcolor{yellow}{MONO}};
    \end{tikzpicture}
  };

  \node[at={($(scope1.south)$)},anchor=north] (scope2) {
    \begin{tikzpicture}
      \node [dummybutton] (1) {};
      \node [dummybutton, right of=1] (2) {};
      \node [circbutton, right of=2] (3) {PROGRAM};
      \node [selcircbutton, right of=3] (4) {PAGE 2};
      \node [circbutton, right of=4] (5) {SEQ.};
      \node [circbutton, right of=5] (6) {SETTINGS};
      \node [dummybutton, right of=6] (7) {};
      \node [dummybutton, right of=7] (8) {};

      \node [hcircbutton, below=0.1cm of 1] (8) {CLEAR};
      \node [hcircbutton, right of=8] (9) {SAVE};
      \node [dummybutton, right of=9] (10) {};
      \node [dummybutton, right of=10] (11) {};
      \node [dummybutton, right of=11] (12) {};
      \node [dummybutton, right of=12] (13) {};
      \node [hcircbutton, right of=13] (14) {UP};
      \node [hcircbutton, right of=14] (15) {DOWN};
    \end{tikzpicture}
  };
\end{tikzpicture}

\subsubsection{Monophonic and polyphonic modes}

When several channels are sharing the same MIDI channel, notes can be assigned either monophonically or polyphonically. In \textbf{monophonic} mode, all channels will play the same incoming MIDI note, and any new note will cut off the previous. This mode is selected by pressing \btn{(UPPER) MONO}. In \textbf{polyphonic} mode, the channels will be allocated in turn to each of the incoming MIDI notes. This mode is selected by pressing \btn{(UPPER) POLY}.

\subsubsection{Splitting the keyboard}

The MIDI keyboard\footnote{Not necessarily a physical keyboard, but more generally the range of MIDI notes.} can be split into two sections, a \emph{lower} and a \emph{upper} section. To activate this split, press \btn{SPLIT ON/OFF}. When the split is active, the \emph{splitting point} sets the boundary between the lower and upper half. To change the splitting point, press \btn{SPLIT SET POINT}, and select the note where you want the split. The notes are shown with a letter in the first half of the display, and the octave number in the second. A dot on the first display indicates a flat note. For instance, \verb+E.5+ would indicate the note E$\flat$ in the fourth octave (as numbered in MIDI).

The channels can be assigned to either section by pressing and holding the corresponding channel button and then pressing \btn{SPLIT HALF}. The sections are named on the display as \verb+Lo+ and \verb+UP+, short for Lower and Upper, respectively. When a channel has been assigned to one of the halves, that channel will only play a note when that note is in the same half.

Several channels can be assigned to the same half of the keyboard, so there are separate monophonic and polypohnic settings for each half. Use \btn{LOWER POLY} and \btn{LOWER MONO} to select the assignment mode for the lower half. Similarly, use \btn{(UPPER) POLY} and \btn{(UPPER) MONO} to select the assignment mode for the upper half (these are the same buttons as used for assignment mode when split is off).

\section{SEQUENCER}

In the sequencer mode, 16-note patterns can be created and played back. The sequencer is somewhat more complicated to use than the programmer. The user interface employs several \emph{levels}.

While a pattern is playing, you can change the NESIZER into any of the other modes. For example, the current patch can be edited while the sequence is playing.

\subsection{Selection mode}

When first entering the sequencer, it is at the \emph{selection layer}. This is where you select a pattern for playback or editing, as well as adjusting tempo.

\begin{tikzpicture}[align=center, node distance=1.5cm, auto]
  \node(scope1) {
    \begin{tikzpicture}
      \node [mhbutton] (1) {SQ1};
      \node [mhbutton, right of=1] (2) {SQ2};
      \node [mhbutton, right of=2] (3) {TRI};
      \node [mhbutton, right of=3] (4) {NOISE};
      \node [mhbutton, right of=4] (5) {DMC};
      \node [hbutton, right of=5] (6) {MIDI OUT\\CHANNEL};
      \node [button, right of=6] (7) {};
      \node [button, right of=7] (8) {};

      \node [hbutton, below=1] (9) {RECORD};
      \node [button, right of=9] (10) {};
      \node [button, right of=10] (11) {};
      \node [button, right of=11] (12) {};
      \node [button, right of=12] (13) {};
      \node [button, right of=13] (14) {};
      \node [hbutton, right of=14] (15) {END POINT};
      \node [hbutton, right of=15] (16) {SCALE};
    \end{tikzpicture}
  };

  \node[at={($(scope1.south)$)},anchor=north] (scope2) {
    \begin{tikzpicture}
      \node [dummybutton] (1) {};
      \node [dummybutton, right of=1] (2) {};
      \node [circbutton, right of=2] (3) {PROGRAM};
      \node [circbutton, right of=3] (4) {PAGE 2};
      \node [selcircbutton, right of=4] (5) {SEQ.};
      \node [circbutton, right of=5] (6) {SETTINGS};
      \node [dummybutton, right of=6] (7) {};
      \node [dummybutton, right of=7] (8) {};

      \node [hcircbutton, below=0.1cm of 1] (8) {PLAY/\\STOP};
      \node [hcircbutton, right of=8] (9) {SAVE};
      \node [dummybutton, right of=9] (10) {};
      \node [dummybutton, right of=10] (11) {};
      \node [dummybutton, right of=11] (12) {};
      \node [dummybutton, right of=12] (13) {};
      \node [hcircbutton, right of=13] (14) {UP};
      \node [hcircbutton, right of=14] (15) {DOWN};
    \end{tikzpicture}
  };
\end{tikzpicture}

\subsubsection{Selecting a sequence}

To select a new pattern, first make sure you are at the top level and not already editing a pattern. If you are, close the current pattern by pressing \btn{BACK}. Use \btn{UP} and \btn{DOWN} to select the pattern you want to edit. To edit the selected pattern, press the button for the channel you want to edit. The sequencer will then enter editing mode.

\subsubsection{Playing back a sequence}

To play back a selected sequence, press \btn{PLAY}. The sequence will loop indefinitely. Press \btn{PLAY} again to stop it. While a pattern is playing, \btn{UP} and \btn{DOWN} can be used to adjust the tempo.

\subsubsection{Editing a sequence}

To edit a pattern in the selected sequence, press the channel button corresponding to the one you want to edit. The sequencer will then enter pattern editing mode.

\subsubsection{Saving a sequence}

Any changes you have done to a sequence will not be saved until you press \btn{SAVE}. Saving sequences is done exactly the same way as saving programs.

\subsubsection{Scaling}

By pressing \btn{SCALE}, you can set the \emph{scale} of the sequence. The scale determines whether the 16-step sequence should represent one, two or four bars. When the scale is 1, each step in the sequence represents a 16th note in the bar. If the scale is 2, each step represents an 8th note. And finally, if the scale is set to 4, each step represents a quarter note.

\subsubsection{Setting the end point}

Sequences have the full length of 16 notes by default. To create sequences that fit with other time signatures, press \btn{END POINT}. The 16 pattern position LEDs will start blinking. Press the pattern position button that you want to be the last one in the sequence. The LEDs will stop blinking, and the new end point has been set.

\subsubsection{Selecting MIDI output channels}
Each of the five channel patterns can be assigned to an output MIDI channel. To do this, press and hold \btn{MIDI OUT CHANNEL} while pressing the button for the desired channel to assign an output MIDI channel to. When playing any sequence, notes from that pattern will then play on the selected MIDI channel, while still playing on the corresponding 2A03 channel.

\emph{Tip: By using a patch where no 2A03 channels are enabled, the sequencer can be used as a general MIDI sequencer.}

\subsection{Pattern editing mode}

When in pattern editing mode, the buttons take on the following functions:

\begin{tikzpicture}[align=center, node distance=1.5cm, auto]
  \node(scope1) {
    \begin{tikzpicture}
      \node [mhbutton] (1) {1};
      \node [mhbutton, right of=1] (2) {2};
      \node [mhbutton, right of=2] (3) {3};
      \node [mhbutton, right of=3] (4) {4};
      \node [mhbutton, right of=4] (5) {5};
      \node [hbutton, right of=5] (6) {6};
      \node [hbutton, right of=6] (7) {7};
      \node [hbutton, right of=7] (8) {8};

      \node [hbutton, below=1] (9) {9};
      \node [hbutton, right of=9] (10) {10};
      \node [hbutton, right of=10] (11) {11};
      \node [hbutton, right of=11] (12) {12};
      \node [hbutton, right of=12] (13) {13};
      \node [hbutton, right of=13] (14) {14};
      \node [hbutton, right of=14] (15) {15};
      \node [hbutton, right of=15] (16) {16};
    \end{tikzpicture}
  };

  \node[at={($(scope1.south)$)},anchor=north] (scope2) {
    \begin{tikzpicture}
      \node [dummybutton] (1) {};
      \node [dummybutton, right of=1] (2) {};
      \node [circbutton, right of=2] (3) {PROGRAM};
      \node [circbutton, right of=3] (4) {PAGE 2};
      \node [selcircbutton, right of=4] (5) {SEQ.};
      \node [circbutton, right of=5] (6) {SETTINGS};
      \node [dummybutton, right of=6] (7) {};
      \node [dummybutton, right of=7] (8) {};

      \node [hcircbutton, below=0.1cm of 1] (9) {BACK};
      \node [circbutton, right of=9] (10) {};
      \node [dummybutton, right of=10] (11) {};
      \node [dummybutton, right of=11] (12) {};
      \node [dummybutton, right of=12] (13) {};
      \node [dummybutton, right of=13] (14) {};
      \node [circbutton, right of=14] (15) {UP};
      \node [circbutton, right of=15] (16) {DOWN};
    \end{tikzpicture}
  };
\end{tikzpicture}

To help you remember which channel's pattern you're currently editing, the display will indicate a number ranging from 1 to 5, corresponding to SQ1, SQ2, TRI, NOISE and DMC, respectively.

Each of the 16 top buttons represent a position in the pattern. To place a note at a particular position in the pattern, press the corresponding button. The sequencer will then enter note entering mode, indicated by the LED on the button flashing. The next section details how you enter a note.

After a note has been entered, the button's LED will light up to indicate that a note is present at that position in the pattern.

When you're done working on the channel's pattern, press \btn{BACK} to go back to pattern selection mode.

\subsection{Note entering mode}

When a note has been selected in a pattern, the LED for the corresponding button will flash. The buttons now take on the following functions:

\begin{tikzpicture}[align=center, node distance=1.5cm, auto]
  \node(scope1) {
    \begin{tikzpicture}
      \node [mhbutton] (1) {C\#};
      \node [mhbutton, right of=1] (2) {D\#};
      \node [mhbutton, right of=2] (3) {};
      \node [mhbutton, right of=3] (4) {F\#};
      \node [mhbutton, right of=4] (5) {G\#};
      \node [hbutton, right of=5] (6) {A\#};
      \node [hbutton, right of=6] (7) {OCTAVE};
      \node [hbutton, right of=7] (8) {ERASE};

      \node [hbutton, below=1] (9) {C};
      \node [hbutton, right of=9] (10) {D};
      \node [hbutton, right of=10] (11) {E};
      \node [hbutton, right of=11] (12) {F};
      \node [hbutton, right of=12] (13) {G};
      \node [hbutton, right of=13] (14) {A};
      \node [hbutton, right of=14] (15) {B};
      \node [hbutton, right of=15] (16) {C};
    \end{tikzpicture}
  };

  \node[at={($(scope1.south)$)},anchor=north] (scope2) {
    \begin{tikzpicture}
      \node [dummybutton] (1) {};
      \node [dummybutton, right of=1] (2) {};
      \node [circbutton, right of=2] (3) {PROGRAM};
      \node [circbutton, right of=3] (4) {PAGE 2};
      \node [selcircbutton, right of=4] (5) {SEQ.};
      \node [circbutton, right of=5] (6) {SETTINGS};
      \node [dummybutton, right of=6] (7) {};
      \node [dummybutton, right of=7] (8) {};

      \node [hcircbutton, below=0.1cm of 1] (9) {BACK};
      \node [hcircbutton, right of=9] (10) {SET};
      \node [dummybutton, right of=10] (11) {};
      \node [dummybutton, right of=11] (12) {};
      \node [dummybutton, right of=12] (13) {};
      \node [dummybutton, right of=13] (14) {};
      \node [hcircbutton, right of=14] (15) {UP};
      \node [hcircbutton, right of=15] (16) {DOWN};
    \end{tikzpicture}
  };
\end{tikzpicture}

\subsubsection{Entering or changing notes}
First enter the length you want for the note, using \btn{UP} and \btn{DOWN}. The length is given in a scale of 1/6 of the duration of one step, so if the length value is 3, that means that the note will last for half the duration of one step in the pattern. The length setting will be remembered the next time you enter a note again for the same channel.

When the length has been set, you can enter the note by either using MIDI, or by using the built-in keyboard, as shown in the figure above. As soon as a note has been entered, the sequencer will be return to the pattern editing mode.

When selecting notes on the built-in keyboard, you can change the current octave by holding \btn{OCTAVE} and using \btn{UP} and \btn{DOWN}.

\subsubsection{Clearing notes}
Press \btn{ERASE} if you want to clear the note. The sequencer will return to pattern editing mode, and the LED on the corresponding note will turn off to indicate that it is empty.

\subsubsection{Editing length only}
When the length has been set to the new value, press \btn{OK} to save the change without entering a new note.

\subsubsection{Aborting}
Press \btn{BACK} to go back to the pattern editing mode. Any changes you made to the note will be discarded.

\section{SETTINGS}

When in the settings mode, various aspects of how the \name operates can be changed. In this mode, the buttons have the following functions:

\begin{tikzpicture}[align=center, node distance=1.5cm]
  \node(scope1) {
    \begin{tikzpicture}
      \node [mhbutton] (1) {SQ1};
      \node [mhbutton, right of=1] (2) {SQ2};
      \node [mhbutton, right of=2] (3) {TRI};
      \node [mhbutton, right of=3] (4) {NOISE};
      \node [mhbutton, right of=4] (5) {DMC};
      \node [hbutton, right of=5] (6) {MIDI\\CHANNEL};
      \node [hbutton, right of=6] (7) {BATTERY\\VOLTAGE};
      \node [hbutton, right of=7] (8) {CHIP TYPE};

      \node [hbutton, below=1] (9) {PATCH\\RESET};
      \node [button, right of=9] (10) {};
      \node [button, right of=10] (11) {};
      \node [button, right of=11] (12) {};
      \node [button, right of=12] (13) {};
      \node [hbutton, right of=13] (14) {EXT.\\CLOCK};
      \node [hbutton, right of=14] (15) {SAMPLE\\RESET};
      \node [hbutton, right of=15] (16) {SAMPLE\\DELETE};
    \end{tikzpicture}
  };

  \node[at={($(scope1.south)$)},anchor=north] (scope2) {
    \begin{tikzpicture}
      \node [dummybutton] (1) {};
      \node [dummybutton, right of=1] (2) {};
      \node [circbutton, right of=2] (3) {PROGRAM};
      \node [circbutton, right of=3] (4) {PAGE 2};
      \node [circbutton, right of=4] (5) {SEQ.};
      \node [selcircbutton, right of=5] (6) {SETTINGS};
      \node [dummybutton, right of=6] (7) {};
      \node [dummybutton, right of=7] (8) {};

      \node [hcircbutton, below=0.1cm of 1] (9) {CLEAR};
      \node [hcircbutton, right of=9] (10) {SAVE};
      \node [dummybutton, right of=10] (11) {};
      \node [dummybutton, right of=11] (12) {};
      \node [dummybutton, right of=12] (13) {};
      \node [dummybutton, right of=13] (14) {};
      \node [hcircbutton, right of=14] (15) {UP};
      \node [hcircbutton, right of=15] (16) {DOWN};
    \end{tikzpicture}
  };
\end{tikzpicture}

\btn{UP} and \btn{DOWN} can be used to select a sample number. Sample numbers that are occupied are marked with a dot on the display. A selected sample can be deleted by pressing \btn{DELETE}.

\subsection{MIDI}

The \name can be controlled externally using MIDI.

\subsubsection{Assigning MIDI channels}

Each of the five sound channels can be assigned to any of the 16 MIDI channels, and will then only respond to incoming messages on the selected channel.

If you select the value 0, the sound channel will not listen to any MIDI channel.

To select a MIDI channel, enter the \lbl{SETTINGS} mode by pressing \btn{SETTINGS}. Hold down \btn{MIDI CHANNEL} and then press the desired channel's button. The LEDs will flash and you can select one of the 16 MIDI channels using the \btn{UP} and \btn{DOWN} buttons.

\subsubsection{External clock}
Use \btn{EXT. CLOCK} to use the incoming MIDI clock to set the tempo of the sequencer. When this is set to 1, the sequencer will not do anything unless an external MIDI device sends MIDI Clock messages. When the setting is 0, the internal tempo is used.

\subsection{Checking the battery voltage}
The NESIZER uses a battery for keeping the RAM storing the patches and samples alive when main power is disconnected. To check the battery's voltage, press and hold \btn{BATTERY VOLTAGE}. As long as the button is pressed, the battery's voltage will be shown in the display. If the battery voltage is below 2.6 V, it should be replaced. On startup, the NESIZER will give a warning if the battery is 2.5 V or less. The display will flash \verb+bL+ (Battery Low) for a short duration.

\subsection{Checking the 2A03 type}
To see which 2A03 chip is being used, press the LFO3 button. One of the following numbers will show up:
\begin{itemize}
\item 12: Genuine RP2A03
\item 15: 2A03 clone, e.g. 6527P
\item 16: 2A07 (PAL version of 2A03)
\end{itemize}

\subsection{Resetting patches}

Press \btn{PATCH RESET} to delete all patches. Every patch will be initialized to a basic patch with no channels enabled, square duty cycles set at 50\% and full envelope sustain levels with no attack, decay or release.

\subsection{Maintaining samples}

When in SETTINGS mode, the up and down buttons are used to select DMC samples. A dot appearing on the display indicates that the selected sample location is occupied. When an occupied sample is selected, it can be deleted by pressing \btn{SAMPLE DELETE}. All samples can be erased by pressing \btn{SAMPLE RESET}.

\subsection{Startup indicators}
If an error has occured, the display will flash some indicators to tell which errors were found during startup.
The errors that can occur are:
\begin{itemize}
\item \verb+bL+: Battery low (less than 2.5 V measured) - battery should be changed
\item \verb+cr+: Corrupt RAM - RAM contents will be re-initialized automatically
\end{itemize}

\section{MIDI}

\subsection{MIDI CC}
The NESIZER is capable of receiving MIDI Control Change (CC) messages. Each track can independently respond to CC messages, adjusting its parameters according to the specified ranges under PROGRAM and PAGE 2 modes. These ranges are automatically scaled to the full CC range of 0-127. Additionally, toggle-based ranges are mapped to 'OFF' for values below 64 and 'ON' for values 64 or higher.

\begin{tabular}{l | l | l | l | l | l }
  CC/(*) & SQ 1 & SQ 2 & Tri & Noise & DMC\\ \hline
  \textbf{1} & Duty & Duty & & & \\
  \textbf{5/(65)} & Glide & Glide & Glide & & \\
  \textbf{14} &  &  &  & Loop & Loop \\
  \textbf{30} & LFO 1 & LFO 1 & LFO 1 & LFO 1 & \\
  \textbf{31} & LFO 2 & LFO 2 & LFO 2 & LFO 2 & \\
  \textbf{32} & LFO 3 & LFO 3 & LFO 3 & LFO 3 & \\
  \textbf{72/(60)} & Release & Release &  & Release & \\
  \textbf{73/(61)} & Attack & Attack &  & Attack & \\
  \textbf{75/(62)} & Decay & Decay &  & Decay & \\
  \textbf{77} & Vol mod (LFO 3) & Vol mod (LFO 3) &  & Vol mod (LFO 3) & \\
  \textbf{79/(63)} & Sustain & Sustain &  & Sustain &\\
  \textbf{82} & Pitch Bend intensity & Pitch Bend intensity &  & Pitch Bend intensity & \\
  \textbf{85} & Detune & Detune & Detune &  &\\
  \textbf{95} & Octave Shift & Octave Shift & Octave Shift &  &\\
  \textbf{123} & Enable & Enable & Enable & Enable & Enable\\
\end{tabular}

* The number wrapped in '()' is the toggle message and will enable the parameter/disable the parameter.

\subsection{MIDI CC (Global)}

Global MIDI Control Change (CC) messages are received by all tracks and modify the global parameter value.

\begin{tabular}{l | l}
  CC & Global \\ \hline
  \textbf{50} & LFO 1 Period\\
    \textbf{51} & LFO 1 Waveform\\
    \textbf{52} & LFO 2 Period\\
    \textbf{53} & LFO 2 Waveform\\
    \textbf{54} & LFO 3 Period\\
    \textbf{55} & LFO 3 Waveform\\
\end{tabular}

\subsection{MIDI Program Change}

Patches can be quickly selected by sending a MIDI Program Change (PC) message on any channel. NESizer responds to "True Number" PC values 0-99. Some DAWs such as Logic use the True Number convention 0-127 as defined in the MIDI Specification, whereas others such as Cakewalk use the General MIDI convention of 1-128. Keep this in mind when scheduling patch changes in a DAW or using a controller.

Patches can also be loaded using System Exclusive messages of the form: F0 7D 4E 03 \emph{nn} F7, where \emph{nn} is the desired 2-digit patch number 00-99 in hexidecimal format. For example, use 1C in place of \emph{nn} to load Patch 28.

\section{Using DMC samples}

\subsection{Sample upload workflow}

\tikzstyle{process} = [rectangle,centered,thick,draw=black]
\tikzstyle{arrow} = [thick,->,>=stealth]
\begin{tikzpicture}
  \begin{scope}
    \node (infile) {Input audio file};
    \node (convert) [process, below of=infile] {Convert sample to raw format};
    \node (sysex) [process, below of=convert] {Create SysEx wrapper};
    \node (sampleno) [right of=sysex, xshift=4cm] {Sample index number};
    \node (upload) [process, below of=sysex] {Send/play SysEx file on MIDI output device};

    \draw [arrow] (infile) -- (convert);
    \draw [arrow] (convert) -- (sysex);
    \draw [arrow] (sampleno) -- (sysex);
    \draw [arrow] (sysex) -- (upload);
  \end{scope}
\end{tikzpicture}

\subsection{Converting a sample file}
The first step of creating an audio sample suitable for DMC playback is to convert the audio file to \textbf{raw, 7-bits unsigned per sample, 16 kHz sample rate} format. Many tools will only allow conversion to an 8-bit per sample, however. It is therefore often necessary to convert to 8-bit first, and then truncate each sample to 7-bits when creating a System Exclusive file later.

A variety of audio software tools exist to perform this conversion. The following example uses the tool \emph{Sound eXchange (SoX)}, which is open source and available for Linux, Windows and macOS. Using SoX with an input audio file in \verb+.wav+ format, the conversion can be done as follows:

\verb+sox sample.wav -r 16000 -b 8 -e unsigned-integer sample.raw+

\subsection{Creating a SysEx file}
The converted sample needs to be wrapped with the necessary metadata and MIDI SysEx commands before it can be sent to the NESIZER via MIDI. The stream of bytes to send via MIDI must be in the following format:

\begin{verbatim}
  F0 (System Exclusive)
  7D (Sysex ID)
  4E (Device ID)
  00 (Sample load command)
  ii (Sample index)
  00 (Reserved)
  ss (Sample size 6..0)
  ss (Sample size 13..7)
  ss (Sample size 20..14)
  dd (Sample data 0)
  dd (Sample data 1)
  ..
  dd (Sample data N-1)
  F7 (End of Exclusive)
\end{verbatim}

\textbf{Note:} Any data byte contained within a MIDI System Exclusive message must never have the most significant bit set.

The sample index can be any number between 0 and 99. The index 0 corresponds to MIDI note 36, which is C3, commonly used for kick drum in the General MIDI drum map standard. This is the note that has to be played on the MIDI input or entered into a sequence pattern to trigger the sample on the DMC channel.

The sample size must be given in bytes, but split across three 7-bit words.

The sample data must be 7-bit raw sample values.

In the NESIZER source repository, there is a helpful tool \verb+gensysex.c+ which is a small C program to create this wrapper. This tool can be used as follows (assuming the tool is compiled into a binary called \verb+gensysex+):

\verb+gensysex sample <input format> <index> <raw filename> <sysex filename>+

The following example creates a SysEx file for the file \verb+sample.raw+ created in the above example. It places the sample at index 2, meaning that the note D3 must be played to trigger this sample:

\verb+gensysex sample 8bit 2 sample.raw sample.syx+

\subsection{Uploading samples}
The MIDI SysEx file containing the MIDI byte stream created in the previous step can now be played back on (or sent to) the MIDI adapter which the NESIZER is connected to. There are many different software options for doing this.

On a Linux system, the \verb+amidi+ ALSA utility tool is the easiest way to do this. To find connected MIDI devices, run \verb+amidi -l+ to list connected devices and make note of the Device identifier for the MIDI device you want to use. This should be of the form \verb+hw:x,x,x+, for example \verb+hw:2,0,0+.
To send the SysEx file out on the MIDI line from this MIDI device, run the following command:

\verb+amidi -p <MIDI device> -s <sysex file path>+

Continuing the above example, the \verb+sample.syx+ file can be sent to a NESIZER connected to MIDI device \verb+hw:2,0,0+ by running

\verb+amidi -p hw:2,0,0 -s sample.syx+

When this command is running, the connected NESIZER should be displaying the index number of the sample on the 7 segment display, and the 16 top LEDs should be lighting up a progress bar.

\end{document}

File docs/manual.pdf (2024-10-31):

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

## Contents

The NESIZER | 3
PROGRAM and PAGE 2 modes | 4
SEQUENCER | 8
SETTINGS | 11
MIDI | 13
Using DMC samples | 14
Sample upload work

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

## The NESIZER

Sound channels

At the heart of the NESIZER is the NES APU chip, usually called 2A03 (or 2A07 if you use a chip from the PAL NES). The APU has ve separate sound channels:

| SQ1 and SQ2: These produce square waves with three selectable duty cycles (pulse widths).
| TRI: This channel produces triangular waves, but with a low 4 bit amplitude resolution. This results in the characteristic aliased NES bass and ute tones.
| NOISE: This channel produces various forms of noise. The noise can be white noise, or pitched noise if the LOOP mode is engaged.
| DMC: This channel can output 7-bit samples at a quick rate. The sampling rate is 16 kHz in the NESIZER .

Modulation

Because the 2A03 is put under much tighter control in the NESIZER than in a NES or Famicom console, the NESIZER features extensive modulation capabilities.

| Three separate low frequency oscillators LFO1, LFO2, LFO3 with selectable waveforms (ramp up, ramp down, sine wave, triangle wave or square wave)
| Dedicated ADSR envelope generators for the square and noise channels
| Portamento / glide for the square and triangle channels

## PROGRAM and PAGE 2 modes

This is the active mode when the NESIZER starts up. When in other modes, press the PROGRAM button to switch to this mode.

In the programming mode, the various parameters of the sound channels and LFOs can be changed. A set of channel and LFO settings are collectively known as a patch. The NESIZER can save patches to memory, and has room for 100 patches.

SQ1 | SQ2 | TRI | NOISE | DMC | LFO1 | LFO2 | LFO3

Loading patches

To load a patch, press either | UP | or | DOWN | . To go quickly up or down, press and hold the respective
button. The current patch number is shown on the numeric display. Patches can also be loaded using MIDI Program Change or short SysEx messages (see MIDI section).

Saving patches

To save a patch, press | SAVE | . The button will start to blink to indicate that you can select where to
store the new patch. Use | UP | and | DOWN | to select where to store the patch. Press | SAVE | again
to store the patch at the selected location.
Note: When channel and LFO settings are changed, these are not saved until you press | SAVE | .

Enabling and disabling channels

To enable or disable a channel, press the corresponding channel button. When a channel is disabled, it does not produce sound when being triggered by the sequencer or incoming MIDI data.

PAGE 2

By pressing | PAGE 2 | , a second \page" og parameters become available. Some of them are channel
parameters, and others are related to note assignment. When Page 2 is selected, the NESIZER is
still in programming mode, so pressing | UP | or | DOWN | will change the current patch, and will discard
any changes that haven't been saved. The parameters that are avilable in page 2 are shown in yellow color in the gures below.

Changing channel parameters

To change a channel's parameter, press and hold the desired channel's button, and the desired
parameter button. For example, to change the attack of the square 1 channel, press | SQ1 | and | A | .
The button LEDs will start to blink to indicate which channel parameter is being changed. Use the

UP | and | DOWN | buttons to change the parameter value. When you have the desired value, press
SAVE | .

Square channels

SQ1 | SQ2 | TRI | NOISE | DMC

LFO1

BEND

LFO2

ENV MOD

LFO3

VOL MOD

DUTY

SPLIT HALF

DETUNE | OCTAVE | GLIDE | A | D | S | R
Parameter | Description | Range
LFO1 | Intensity of modulation by LFO1 | 0 - 99
LFO2 | Intensity of modulation by LFO2 | 0 - 99
LFO3 | Intensity of modulation by LFO3 | 0 - 99
DUTY | Duty cycle | 0 - 3
DETUNE | Detuning | -9 - 9
OCTAVE | Octave | -4 - 4
GLIDE | Portamento glide time | 0 - 99
A | Volume envelope attack | 0 - 99
D | Volume envelope decay | 0 - 99
S | Volume envelope sustain | 0 - 15
R | Volume envelope release | 0 - 99
BEND (page 2) | Bend wheel intensity in semitones | 0 - 24
ENV MOD (page 2) | Pitch envelope modulation amount | -9 - 9
VOL MOD (page 2) | Volume modulation by LFO3 | 0 - 16
SPLIT HALF (page 2) | See section 1.3.6 | Lower - Upper

Triangle channel

SQ1 | SQ2 | TRI | NOISE | DMC

LFO1

BEND

LFO2

ENV MOD

LFO3

SPLIT HALF | DETUNE | OCTAVE | GLIDE
Parameter | Description | Range
LFO1 | Intensity of modulation by LFO1 | 0 - 99
LFO2 | Intensity of modulation by LFO2 | 0 - 99
LFO3 | Intensity of modulation by LFO3 | 0 - 99
DETUNE | Detuning | -9 - 9
OCTAVE | Octave | -4 - 4
GLIDE | Portamento glide time | 0 - 99
BEND (page 2) | Bend wheel intensity in semitones | 0 - 24
ENV MOD (page 2) | Pitch envelope modulation (noise envelope) | -9 - 9
SPLIT HALF (page 2) | See section 1.3.6 | Lower - Upper

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

Note assignment

SQ1 | SQ2 | TRI | NOISE | DMC | LFO1 | LFO2 | LFO3
SPLIT HALF | SPLIT ON/OFF
SPLIT
SET POINT

LOWER
POLY

LOWER
MONO

(UPPER)
POLY

(UPPER)
MONO

Monophonic and polyphonic modes

When several channels are sharing the same MIDI channel, notes can be assigned either monophon-ically or polyphonically. In monophonic mode, all channels will play the same incoming MIDI note,
and any new note will cut o the previous. This mode is selected by pressing | (UPPER) MONO | . In
polyphonic mode, the channels will be allocated in turn to each of the incoming MIDI notes. This
mode is selected by pressing | (UPPER) POLY | .

Splitting the keyboard

The MIDI keyboard¹
can be split into two sections, a lower and a upper section. To activate this
split, press | SPLIT ON/OFF | . When the split is active, the splitting point sets the boundary between
the lower and upper half. To change the splitting point, press | SPLIT SET POINT | , and select the note
where you want the split. The notes are shown with a letter in the rst half of the display, and the octave number in the second. A dot on the rst display indicates a
at note. For instance, E.5 would indicate the note E[ in the fourth octave (as numbered in MIDI).

The channels can be assigned to either section by pressing and holding the corresponding channel
button and then pressing | SPLIT HALF | . The sections are named on the display as Lo and UP, short for
Lower and Upper, respectively. When a channel has been assigned to one of the halves, that channel will only play a note when that note is in the same half.

Several channels can be assigned to the same half of the keyboard, so there are separate mono-
phonic and polypohnic settings for each half. Use | LOWER POLY | and | LOWER MONO | to select the
assignment mode for the lower half. Similarly, use | (UPPER) POLY | and | (UPPER) MONO | to select the
assignment mode for the upper half (these are the same buttons as used for assignment mode when split is o).

1Not necessarily a physical keyboard, but more generally the range of MIDI notes.

## SEQUENCER

In the sequencer mode, 16-note patterns can be created and played back. The sequencer is somewhat more complicated to use than the programmer. The user interface employs several levels.

While a pattern is playing, you can change the NESIZER into any of the other modes. For example, the current patch can be edited while the sequence is playing.

Selection mode

When rst entering the sequencer, it is at the selection layer. This is where you select a pattern for playback or editing, as well as adjusting tempo.

SQ1 | SQ2 | TRI | NOISE | DMC | MIDI OUT CHANNEL
RECORD | END POINT | SCALE

Selecting a sequence

To select a new pattern, rst make sure you are at the top level and not already editing a pattern.
If you are, close the current pattern by pressing | BACK | . Use | UP | and | DOWN | to select the pattern
you want to edit. To edit the selected pattern, press the button for the channel you want to edit. The sequencer will then enter editing mode.

Playing back a sequence

To play back a selected sequence, press | PLAY | . The sequence will loop indenitely. Press | PLAY
again to stop it. While a pattern is playing, | UP | and | DOWN | can be used to adjust the tempo.

Editing a sequence

To edit a pattern in the selected sequence, press the channel button corresponding to the one you want to edit. The sequencer will then enter pattern editing mode.

Saving a sequence

Any changes you have done to a sequence will not be saved until you press | SAVE | . Saving sequences
is done exactly the same way as saving programs.

Scaling

By pressing | SCALE | , you can set the scale of the sequence. The scale determines whether the 16-
step sequence should represent one, two or four bars. When the scale is 1, each step in the sequence represents a 16th note in the bar. If the scale is 2, each step represents an 8th note. And nally, if the scale is set to 4, each step represents a quarter note.

Setting the end point

Sequences have the full length of 16 notes by default. To create sequences that t with other time
signatures, press | END POINT | . The 16 pattern position LEDs will start blinking. Press the pattern
position button that you want to be the last one in the sequence. The LEDs will stop blinking, and the new end point has been set.

Selecting MIDI output channels

Each of the ve channel patterns can be assigned to an output MIDI channel. To do this, press and
hold | MIDI OUT CHANNEL | while pressing the button for the desired channel to assign an output MIDI
channel to. When playing any sequence, notes from that pattern will then play on the selected MIDI channel, while still playing on the corresponding 2A03 channel.

Tip: By using a patch where no 2A03 channels are enabled, the sequencer can be used as a general MIDI sequencer.

Pattern editing mode

When in pattern editing mode, the buttons take on the following functions:

1 | 2 | 3 | 4 | 5 | 6 | 7 | 8
9 | 10 | 11 | 12 | 13 | 14 | 15 | 16

To help you remember which channel's pattern you're currently editing, the display will indicate a number ranging from 1 to 5, corresponding to SQ1, SQ2, TRI, NOISE and DMC, respectively.

Each of the 16 top buttons represent a position in the pattern. To place a note at a particular position in the pattern, press the corresponding button. The sequencer will then enter note entering mode, indicated by the LED on the button

ashing. The next section details how you enter a note.

After a note has been entered, the button's LED will light up to indicate that a note is present at that position in the pattern.

When you're done working on the channel's pattern, press | BACK | to go back to pattern selection
mode.

Note entering mode

When a note has been selected in a pattern, the LED for the corresponding button will
| | ash. The
buttons now take on the following functions:

C# | D# | F# | G# | A# | OCTAVE | ERASE
C | D | E | F | G | A | B | C

Entering or changing notes

First enter the length you want for the note, using | UP | and | DOWN | . The length is given in a scale
of 1/6 of the duration of one step, so if the length value is 3, that means that the note will last for half the duration of one step in the pattern. The length setting will be remembered the next time you enter a note again for the same channel.

When the length has been set, you can enter the note by either using MIDI, or by using the built-in keyboard, as shown in the gure above. As soon as a note has been entered, the sequencer will be return to the pattern editing mode.

When selecting notes on the built-in keyboard, you can change the current octave by holding | OCTAVE
and using | UP | and | DOWN | .

Clearing notes

Press | ERASE | if you want to clear the note. The sequencer will return to pattern editing mode, and
the LED on the corresponding note will turn o to indicate that it is empty.

Editing length only

When the length has been set to the new value, press | OK | to save the change without entering a
new note.

Aborting

Press | BACK | to go back to the pattern editing mode. Any changes you made to the note will be
discarded.

## SETTINGS

When in the settings mode, various aspects of how the NESIZER operates can be changed. In this mode, the buttons have the following functions:

SQ1 | SQ2 | TRI | NOISE | DMC | MIDI CHANNEL

BATTERY
VOLTAGE | CHIP TYPE

PATCH
RESET

EXT.
CLOCK

SAMPLE
RESET

SAMPLE
DELETE
UP | and | DOWN | can be used to select a sample number. Sample numbers that are occupied are
marked with a dot on the display. A selected sample can be deleted by pressing | DELETE | .

MIDI

The NESIZER can be controlled externally using MIDI.

Assigning MIDI channels

Each of the ve sound channels can be assigned to any of the 16 MIDI channels, and will then only respond to incoming messages on the selected channel.

If you select the value 0, the sound channel will not listen to any MIDI channel.

To select a MIDI channel, enter the SETTINGS mode by pressing | SETTINGS | . Hold down | MIDI CHANNEL
and then press the desired channel's button. The LEDs will

ash and you can select one of the 16
MIDI channels using the | UP | and | DOWN | buttons.

External clock

Use | EXT. CLOCK | to use the incoming MIDI clock to set the tempo of the sequencer. When this is set
to 1, the sequencer will not do anything unless an external MIDI device sends MIDI Clock messages. When the setting is 0, the internal tempo is used.

Checking the battery voltage

The NESIZER uses a battery for keeping the RAM storing the patches and samples alive when main
power is disconnected. To check the battery's voltage, press and hold | BATTERY VOLTAGE | . As long
as the button is pressed, the battery's voltage will be shown in the display. If the battery voltage is below 2.6 V, it should be replaced. On startup, the NESIZER will give a warning if the battery is 2.5 V or less. The display will

ash bL (Battery Low) for a short duration.

Checking the 2A03 type

To see which 2A03 chip is being used, press the LFO3 button. One of the following numbers will show up:

| 12: Genuine RP2A03
| 15: 2A03 clone, e.g. 6527P
| 16: 2A07 (PAL version of 2A03)

Resetting patches

Press | PATCH RESET | to delete all patches. Every patch will be initialized to a basic patch with no
channels enabled, square duty cycles set at 50% and full envelope sustain levels with no attack, decay or release.

Maintaining samples

When in SETTINGS mode, the up and down buttons are used to select DMC samples. A dot appearing on the display indicates that the selected sample location is occupied. When an occupied
sample is selected, it can be deleted by pressing | SAMPLE DELETE | . All samples can be erased by
pressing | SAMPLE RESET | .

Startup indicators

If an error has occured, the display will

ash some indicators to tell which errors were found during startup. The errors that can occur are:

| bL: Battery low (less than 2.5 V measured) - battery should be changed
| cr: Corrupt RAM - RAM contents will be re-initialized automatically

## MIDI

MIDI CC

The NESIZER is capable of receiving MIDI Control Change (CC) messages. Each track can inde-pendently respond to CC messages, adjusting its parameters according to the specied ranges under PROGRAM and PAGE 2 modes. These ranges are automatically scaled to the full CC range of 0-127. Additionally, toggle-based ranges are mapped to 'OFF' for values below 64 and 'ON' for values 64 or higher.

CC/(*) | SQ 1 | SQ 2 | Tri | Noise | DMC
1 | Duty | Duty
5/(65) | Glide | Glide | Glide
14 | | | | Loop | Loop
30 | LFO 1 | LFO 1 | LFO 1 | LFO 1
31 | LFO 2 | LFO 2 | LFO 2 | LFO 2
32 | LFO 3 | LFO 3 | LFO 3 | LFO 3
72/(60) | Release | Release | | Release
73/(61) | Attack | Attack | | Attack
75/(62) | Decay | Decay | | Decay
77 | Vol mod (LFO 3) | Vol mod (LFO 3) | | Vol mod (LFO 3)
79/(63) | Sustain | Sustain | | Sustain
82 | Pitch Bend intensity | Pitch Bend intensity | | Pitch Bend intensity
85 | Detune | Detune | Detune
95 | Octave Shift | Octave Shift | Octave Shift
123 | Enable | Enable | Enable | Enable | Enable

* The number wrapped in '()' is the toggle message and will enable the parameter/disable the parameter.

MIDI CC (Global)

Global MIDI Control Change (CC) messages are received by all tracks and modify the global parameter value.

CC | Global
50 | LFO 1 Period
51 | LFO 1 Waveform
52 | LFO 2 Period
53 | LFO 2 Waveform
54 | LFO 3 Period
55 | LFO 3 Waveform

MIDI Program Change

Patches can be quickly selected by sending a MIDI Program Change (PC) message on any channel. NESizer responds to "True Number" PC values 0-99. Some DAWs such as Logic use the True Number convention 0-127 as dened in the MIDI Specication, whereas others such as Cakewalk use the General MIDI convention of 1-128. Keep this in mind when scheduling patch changes in a DAW or using a controller.

Patches can also be loaded using System Exclusive messages of the form: F0 7D 4E 03 nn F7, where nn is the desired 2-digit patch number 00-99 in hexidecimal format. For example, use 1C in place of nn to load Patch 28.

## Using DMC samples

Sample upload work
ow

Input audio le

Convert sample to raw format

Create SysEx wrapper | Sample index number

Send/play SysEx le on MIDI output device

Converting a sample le

The rst step of creating an audio sample suitable for DMC playback is to convert the audio le to raw, 7-bits unsigned per sample, 16 kHz sample rate format. Many tools will only allow conversion to an 8-bit per sample, however. It is therefore often necessary to convert to 8-bit rst, and then truncate each sample to 7-bits when creating a System Exclusive le later.

A variety of audio software tools exist to perform this conversion. The following example uses the tool Sound eXchange (SoX), which is open source and available for Linux, Windows and macOS. Using SoX with an input audio le in .wav format, the conversion can be done as follows:

sox sample.wav -r 16000 -b 8 -e unsigned-integer sample.raw

Creating a SysEx le

The converted sample needs to be wrapped with the necessary metadata and MIDI SysEx commands before it can be sent to the NESIZER via MIDI. The stream of bytes to send via MIDI must be in the following format:

F0 (System Exclusive)
7D (Sysex ID)
4E (Device ID)
00 (Sample load command)
ii (Sample index)
00 (Reserved)
ss (Sample size 6..0)
ss (Sample size 13..7)
ss (Sample size 20..14)
dd (Sample data 0)
dd (Sample data 1)
dd (Sample data N-1)
F7 (End of Exclusive)

Note: Any data byte contained within a MIDI System Exclusive message must never have the most signicant bit set.

The sample index can be any number between 0 and 99. The index 0 corresponds to MIDI note 36, which is C3, commonly used for kick drum in the General MIDI drum map standard. This is the note that has to be played on the MIDI input or entered into a sequence pattern to trigger the sample on the DMC channel.

The sample size must be given in bytes, but split across three 7-bit words.

The sample data must be 7-bit raw sample values.

In the NESIZER source repository, there is a helpful tool gensysex.c which is a small C program to create this wrapper. This tool can be used as follows (assuming the tool is compiled into a binary called gensysex):

gensysex sample <input format> <index> <raw filename> <sysex filename>

The following example creates a SysEx le for the le sample.raw created in the above example. It places the sample at index 2, meaning that the note D3 must be played to trigger this sample:

gensysex sample 8bit 2 sample.raw sample.syx

Uploading samples

The MIDI SysEx le containing the MIDI byte stream created in the previous step can now be played back on (or sent to) the MIDI adapter which the NESIZER is connected to. There are many dierent software options for doing this.

On a Linux system, the amidi ALSA utility tool is the easiest way to do this. To nd connected MIDI devices, run amidi -l to list connected devices and make note of the Device identier for the MIDI device you want to use. This should be of the form hw:x,x,x, for example hw:2,0,0. To send the SysEx le out on the MIDI line from this MIDI device, run the following command:

amidi -p <MIDI device> -s <sysex file path>

Continuing the above example, the sample.syx le can be sent to a NESIZER connected to MIDI device hw:2,0,0 by running

amidi -p hw:2,0,0 -s sample.syx

When this command is running, the connected NESIZER should be displaying the index number of the sample on the 7 segment display, and the 16 top LEDs should be lighting up a progress bar.
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

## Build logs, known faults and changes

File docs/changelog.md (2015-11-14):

## Changelog

**August 2015**: Added memory context handling to allow sequential access and random access from different tasks.

**April - July 2015**: Hardware: Completed assembling new prototype boards. Software: Various minor fixes, refactored UI code.

**26/03/15**: Audio circuitry updated. Op-amps are now operating at 2.5V bias to extend the linear range. Emitter follower replaced by op-amp buffer.

**08/03/15**: Optimized the cent to period calculations, now uses a period lookup table and a linear approximation in between seminotes.

**07/03/15**: 2A03 communication functions moved from inline assembly in C to an own assembly file. Added functions for auto-detecting what kind of APU chip (2A03, 2A07, clone) is being used and adjusting the period tables, write functions etc. accordingly.

**02/03/15**: Removed /MEM_EN signal as it is not needed with the DS1210 based backup circuitry.

**01/03/15**: MIDI transfers have been improved. The UI now shows a progress bar (using the upper 16 button leds) when transferring data. Optimizations done in the memory write/read routines.

**28/02/15**: Rationalized the SRAM backup circuitry by replacing one of the DS1210s with two transistors and four resistors. The single DS1210 now has CE tied to ground and uses /CEO to switch two PNP transistors which connect /CE1 and /CE2 to their respective SRAM ICs.

**26/02/15**: Modulation is now done with cents instead of frequency as the 'unit of measurement'. This gives a consistant modulation effect across the octaves. It also turned out that using cents makes computing the corresponding timer period change simpler.

**16/01/15**: Fixed some serious issues with the SRAM circuitry. The unused battery inputs on the DS1210s are grounded, as described in the data sheet, so memory no longer ceases to read correctly a short while after power on. The enable signal of the decoder is now used to deactivate the decoder's outputs before changing the address bits, and turning them on again afterwards. This was to fix a bug where an unintended component was intermittently selected while the address bits were changing.

**11/11/14**: Main board PCB received and assembled. Everything worked well, but some noise and leakage between channels was detected. The audio path has now been redesigned.

**02/10/14**: Prototype PCB finished, waiting for them to arrive.

**22/09/14**: Glide/portamento works. I'm now working on the CPU PCB, and am currently going through the circuit to make sure everything is right. Some redesign has been done on the amplifier section.

**11/09/14**: New LFO modulation implementation. Noise envelope modulation of triangle pitch added.

**05/09/14**: MIDI is now fairly stable, next up is adding more MIDI commands. Uploading samples for the DMC channel via MIDI sysex works, but it is a bit buggy. Detuning of the square and triangle channels has been added. I plan on adding portamento/glide as well.

**31/08/14**: Started implementing MIDI input support. So far SQ1 responds to incoming note on/off messages!

**29/08/14**: The NESIZER now has a logo! Done some fixes on the SRAM battery backup circuitry, I'm still battling some data corruption during power-off and power-on. Sample playback has been moved from flash to SRAM.

**25/08/14**: Changed a lot of things in the user interface: Entering pattern notes now also includes a length setting, and octave setting. The upper 16 buttons are converted to "keyboard keys" when waiting for a note. The note is played on the corresponding channel whenever a new setting is made. Patterns are now storable in memory as well. While a pattern is playing the user can switch to patch programming mode and change parameters live.

**22/08/14**: Fixed clock circuit. It turned out to be inadequate for an older 2A03 IC I got off eBay. It now inverts the oscillator output twice, and there's also been added a 1M resistor in parallel with the crystal.

**20/08/14**: Much of the front panel functionality has been implemented. Patch memory saving/loading as well. SRAM battery backup added. A CR2032 3V battery powers the SRAMs when main power is off.

**17/08/14**: Started on planning and implementing the intended user interface. A prototype panel PCB has been designed and sent for production. I have settled on trying to implement as much functionality as possible, without making the user interface too complicated. The final product will have the step sequencer showed in the videos above.

**14/08/14**: SRAM memory added. I plan to use two 512kx8 SRAM ICs, but in theory the way I have implemented it allows for up to 8MB memory (using two 4MB SRAM ICs, if such a thing exists)

**12/08/14**: Analog potentiometer input added. This is needed in the front panel for the user to select attack times, LFO speed, etc.

**09/08/14**: PHI2 is no longer needed for communication between the Atmega168 and the 6502, as the register write routine is now written in assembly and timed by counting clock cycles instead of reading the state of PHI2.

**08/07/14**: Started preparing for MIDI, databus now occupies lower 2 bits of PORTC and upper 6 bits of PORTD. This is to be able to use the RX and possibly TX pins on the Atmega168 for MIDI.

**08/05/14**: Bus addresses are now 3 bits instead of 2, to be able to select more than 4 components. This is not needed right now, but I plan to add a battery backed SRAM to store sequences composed on the sequencer, as well as "patches", etc.

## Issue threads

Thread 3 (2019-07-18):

I Want To Build One

davidpgil, 2019-07-18:
I want to invest the time and resources needed to build one or a few of these. I don't have a background in electronic/electrical engineering, but I am willing to learn. Are the current specs and schematics complete enough that I should be able to build a NESizer if I followed them?

Joshkuebler, 2019-10-23:
I too am interested. Most of my experience is with hardware and at the component level but am learning c++ (school) and am gearing up to build something either like this, or this exactly. I hope everything is correct! Looks very promising. Any luck davidpgil?

davidpgil, 2019-10-24:
@Joshkuebler I have not attempted and I probably will not until I can get confirmation that this design would actually work. I don't have the background to determine if this is a working design.

Jaffe-, 2019-10-24:
Hi to both of you, and sorry for the late reply @davidpgil !

The hardware should work as it is shown. However, the last time I built a board was almost 4 years ago, so I can't remember all the details of how that build went. But as far as I can recall, the board I built worked without having to do any changes to it (patching with wires etc.)

There is one other person who has built the NESizer as well. He did get it up and running without many issues.

davidpgil, 2019-10-26:
@Jaffe- thanks for answering. So, since I have no experience with building something like this, and you dont remember details on how to build one, I think I should start an entry level project such as from [Make Analog Synthesizers](https://www.amazon.com/Make-Analog-Synthesizers-Electronic-Synth-DIY/dp/1449345220/) then try to build yours?

Jaffe-, 2019-10-28:
@davidpgil Yes, definitely. If you don't know that much about electronics then it is a good idea to do something that is simpler and is well documented first! Building the NESizer will require you to get a board produced, and to buy all the components that are listed in the Bill of Materials (listed in hardware/BOM.xls). It is quite a costly investment if you're not completely sure that you can do it.

Joshkuebler, 2020-01-04:
Davidpgil you should hit me up I just recieved the PCBs for this I had to order 5 qty. josh_kuebler@yahoo(dot)com

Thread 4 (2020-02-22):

Need Help With Code!PLZ!

Joshkuebler, 2020-02-22:
Hey Jaffe, sorry to bother you, ive got the boards all put together, hardware and all, minus the coin cell battery(need to run to store). But i am a relative noob when it comes to compiling code. I have atmel studio installed. I see that on github there are many file/folders for all the various functions. Can you explain to me how to build code and load onto chip. I have an ftdi usb to serial will that work also i have an arduino uno if i can use that to program. Please any help would be greatly appreciated, i am so close to finishing this beautiful build. Ive dreamed of putting together an nes synth for so long! you can email me josh_kuebler@yahoodotcom

Jaffe-, 2020-02-23:
Hi again Josh.
I've attached the latest NESizer firmware code (built from github).

To build this on Windows, I first installed git for Windows and cloned the
repository. Then, using the git bash shell I ran 'make' from the cloned
repository. That should work out of the box if you have avr-gcc installed.

Regards,
Johan

lør. 22. feb. 2020 kl. 07:09 skrev Joshkuebler <notifications@github.com>:

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

Joshkuebler, 2020-02-24:
Johan you are a stand up guy. Thanks a million. I will be sure to send video once I get it all sorted. Have a great week!-Joshua Kuebler 

Sent from Yahoo Mail on Android

  On Sun, Feb 23, 2020 at 9:22 AM, Johan Fjeldtvedt<notifications@github.com> wrote:   Hi again Josh.
I've attached the latest NESizer firmware code (built from github).

To build this on Windows, I first installed git for Windows and cloned the
repository. Then, using the git bash shell I ran 'make' from the cloned
repository. That should work out of the box if you have avr-gcc installed.

Regards,
Johan

lør. 22. feb. 2020 kl. 07:09 skrev Joshkuebler <notifications@github.com>:

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

—
You are receiving this because you authored the thread.
Reply to this email directly, view it on GitHub, or unsubscribe.

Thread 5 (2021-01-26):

Documentation sample code does not compile

ryancole38, 2021-01-26:
Hi! First of all, I wanted to say thank you for the tremendous work you've done and the effort you've put into documenting the project.  I've been working on reverse-engineering the project to make a cut-down version (mostly no RAM or front panel) and your documentation and comments have made this task much easier than it would have been otherwise.

That said, the sample code in `software.md` does not currently compile.  I believe it alludes to an older version of the code that had separate functions for each channel.  From my understanding, I believe that this is the minimum amount of code required to produce a noise:

```
main() {
        bus_setup();
	io_setup();
        apu_setup();

	sq_setup(0, &sq1);

	sq1.period = 400;
	sq1.duty = 2;
	sq1.volume = 15;

	sq_update(&sq1);

	apu_refresh_channel(CHN_SQ1);

	while(1){}
}
```

I somehow killed the 2A03 that I was working with (oops), so I can't confirm that this does produce a sound.  In my mind, `bus_setup()` is required because it sets up the bus pins that allow writing to the register that feeds the 2A03.  Similarly, I believe `apu_setup()` is required because it enables the outputs of the channels.

Also, I had to change the fuses on the ATMEGA328P in order to get it to work off of the same clock as the 2A03.  I'm not sure if I selected the right clock divider setting, but I think this would be helpful to add to `software.md`.

If these changes make sense to you, I would be more than happy to update the documentation.  Once again, thanks for your work!

KeenVox, 2021-09-13:
Hi,
what fuses need to be changed on the atmega? I compiled the firmware but I'm not sure if I need to set the fuses too before programming.

Jaffe-, 2021-09-15:
Hi,

The fuse values should be: E:FF, H:DF, L:E0

Johan

KeenVox, 2021-09-15:
Hi, I asked for the fuses but deleted the comment to start a own issue. Sorry for the confusion  🙂
But now I don't need.
Just received the display and looking forward to assemble the synth!

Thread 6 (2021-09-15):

How to upload samples?

KeenVox, 2021-09-15:
Hi,
I just wanted to ask, how to upload samples? I assume the samples have to be converted for sysex and then send while in sample select mode?

Thanks in advance!
Keen

KeenVox, 2021-09-15:
Ah, okay. I will try it!

Thanks for you help, and for the fuse settings too. I'm relativly new to programming microcontroller outside of arduino, so I really appriciated the support!

Jaffe-, 2023-10-06:
Hi @KeenVox,

Really late follow-up, but I recently started working some more on this project to try and finish most of the features.

If you're still interested, I have now done some fixes to the code such that uploading and using samples is a bit more user friendly. I actually realized that the LED progress bar feature was actually never pushed to the git repository, but I have done that now.

I have also added a tool for generating a sysex file with the correct format.
To use this tool, you can look at the script convert-sample.sh. To put it short, convert the sample file to 16 kHz, 7-bit. unsigned raw format. SoX is a good utility for this, the script shows how to do this conversion for input files in wav format.

To create a sysex file from the converted raw sample, run the gensysex program like this:

`./gensysex sample <index> <input raw sample file path> <sysex filename>`

Where the index is which index you want the sample to have in the NESizer file system. Index 0 corresponds to MIDI note 60 (middle C). This is the note you will have to input on MIDI to trigger the sample on the DMC channel, or enter into the sequencer if making a pattern with DMC samples.

When you send the sysex data from the file, the NESizer should give you a progress bar on the LEDs, and the two digit display should show 'rr' (for now). If you see this, you can be sure that the NESizer is actually receiving the data and is storing it in memory. If it does not start, I would try to format the sample file system first, which is done by going into the settings mode/page and then pressing the 7th button on the second row.

beau-seidon, 2023-10-06:
Hell yes! I know what I'm doing this weekend :). I have been meaning to experiment with this to get some samples in, but have been super busy with work lately. I'm going to try it out with your script.

Probably better to post this on another thread since unrelated to samples, but over the next month or so I will try to add some MIDI CC callbacks to modify some of the voice parameters like duty and the envelopes etc., to match the Famimimidi MIDI implementation. It takes me a while because I'm still learning C/C++.

I'll finish the build guide from my notes first, like I said I'd do previously. It's about 40% done.

Jaffe-, 2023-10-08:
> Hell yes! I know what I'm doing this weekend :). I have been meaning to experiment with this to get some samples in, but have been super busy with work lately. I'm going to try it out with your script.
>
> Probably better to post this on another thread since unrelated to samples, but over the next month or so I will try to add some MIDI CC callbacks to modify some of the voice parameters like duty and the envelopes etc., to match the Famimimidi MIDI implementation. It takes me a while because I'm still learning C/C++.
That would be really great! I'd be happy to review a pull-request and get this in.
>
> I'll finish the build guide from my notes first, like I said I'd do previously. It's about 40% done.
Really great work of you to make a build guide and updated BOM. I also would like to get the gerber files uploaded so people can order this without having the PCB tool. Don't know why I didn't do that already...

KeenVox, 2023-10-10:
Hi Johan,
very cool! Will definitly try everything out. Great to see you working on
this project again!

Am 6. Oktober 2023 18:15:43 schrieb Johan Fjeldtvedt
***@***.***>:
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

Jaffe-, 2023-10-10:
> Probably better to post this on another thread since unrelated to samples, but over the next month or so I will try to add some MIDI CC callbacks to modify some of the voice parameters like duty and the envelopes etc., to match the Famimimidi MIDI implementation. It takes me a while because I'm still learning C/C++.
>

Regarding another thread for this, please make one under Discussion (instead of Issues), I added that feature to the repository now :)
Also, I pushed a commit yesterday which changes the Makefile to compile the sources with -O2 instead of -O3 optimization level. This reduced the flash size from ~30 kB to ~22 kB (less aggressive unrolling of loops and branches), so there should be enough room to implement more features now.
I did some quick testing that things still run fast enough, and it seems like it is.

jeff464, 2024-08-13:
I would also like to know how to upload samples to the NESizer. I converted my audio file to the proper format using sox, but I'm not sure what "run the gensysex program like this: ./gensysex sample <index> <input raw sample file path> <sysex filename>" means in this context. The windows command line just errors out and double clicking the file sends me to VSC to edit it.

beau-seidon, 2024-08-14:
the source for gensysex is in the repo, and can be compiled with gcc or another c compiler (i used msvc). ill upload my Windows compiled binary after work. im also working on a script to batch-upload sysex files to nesizer using midiox, to load whole drum/sample kits at a time.

beau-seidon, 2024-08-15:
[gensysex.zip](https://github.com/user-attachments/files/16625390/gensysex.zip)

here are the gensysex and deltacompress windows executables used to convert samples. you shouldn't need to do anything with dc.

take a look at the .sh script in tools to see how the process is automated in linux. it shows the syntax for calling gensysex in a terminal. I have a .sh and .bat script for converting big batches of samples, but I have some tweaks to make before I upload them.

I also have a little bit of experimenting to do regarding the indexing of samples (mapping to MIDI notes), which may lead to a wishlist item of my own.

jeff464, 2025-01-31:
I'm about five months late on this. Sorry!

I just followed the instructions in the manual. Using sox, I am able to generate a new sample named "sample.raw". Perfect!

However, when I place "sample.raw" in the same folder as gensysex and run gensysex.exe via a cmd prompt in the manual using "gensysex sample 8bit 2 sample.raw sample.syx" I receive a "Failed to open input file 2: No such file or directory" error.

I'm not sure what I'm doing wrong here.

beau-seidon, 2025-01-31:
try it without 8bit

jeff464, 2025-01-31:
I just tried it without 8bit and it successfully generates a sysex file. When I send the sysex to the NESizer, the segment display changes to something unintelligible. When the transfer is finished, nothing seems to have loaded.

beau-seidon, 2025-01-31:
what software are you using to send the sysex file?

jeff464, 2025-01-31:
I tested with Borne SendSX 1.40 and MIDI-OX

beau-seidon, 2025-01-31:
I use MIDI-OX with the following settings:

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

Use `Command Window > Load File` to open the sysex file you generated, and look at the first few bytes. They should be **F0 7D 4E 02** if you chose index 2. Is that the case?

Are you using the latest firmware build?

jeff464, 2025-01-31:
Yep, using the latest build. First few bytes are F0 01 02 00 1F, so it seems that something is going sideways.

beau-seidon, 2025-01-31:
Are you using gensysex.exe from the /Tools folder? or the old one in the linked zip file from earlier in this thread which im about to remove?

jeff464, 2025-01-31:
I started with the one in the tools folder before I knew to remove 8bit and moved to the one in this thread. I'll try the other again to see if I have any luck.

beau-seidon, 2025-01-31:
I'd like to know what exactly happened when you tried to load the syx file with the incorrect header. It should have printed "no" to the 7seg display until it finished sending.

jeff464, 2025-01-31:
Trying to run the gensysex.exe file from the main tools download with/without admin - a double click gives no response and manually running it in cmd displays "'gensysex.exe' is not recognized as an internal or external command,
operable program or batch file."

jeff464, 2025-01-31:
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

Here is what the display shows when trying to upload the sysex file:

jeff464, 2025-01-31:
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

Here is what my display shows when trying to upload the sysex file.

beau-seidon, 2025-01-31:
It's a command line tool, so you have to use the terminal.
Make sure your current working directory is the folder gensysex is saved to.
Use it exactly like you did the other one.

beau-seidon, 2025-01-31:
> 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
>
> Here is what my display shows when trying to upload the sysex file.

oh thats weird. mine shows those two top horizontal lines in the middle segments. it's supposed to say "no" in lowercase letters.
are there any other display issues? any garbled symbols when you expect numbers?

jeff464, 2025-01-31:
Nope! Everything is perfect as far as I can tell. Thinking about it, I think it did say "no" the very first time I tried. Now it displays what's in the photo.

beau-seidon, 2025-01-31:
i'll see if i can break mine by feeding it an old-format sysex!

jeff464, 2025-01-31:
Good news on both fronts - a reboot fixed the weird display. It now displays "no" correctly when sending it garbage. Also, I successfully uploaded a clap lol. It seems my problem was two fold - I was using the wrong gensysex, and I needed to remove "8bit."

Now to stay up all night and dump all sorts of stuff to the NESizer. Thank you for talking me through this.

beau-seidon, 2025-01-31:
YAS! load all the samples! and no worries.
sorry i didn't catch the command error in the docs. will get that updated.

bad news is you still have to upload samples to the board one at a time if you're using MIDI-OX.
I was able to write COM scripts in 2 different languages (ps, and vbscript) to automate MIDI-OX and upload samples in batches. unfortunately theres a bug in MIDI-OX that makes it quit randomly halfway through.
i thought i reported it on their forum months ago, but looking back through them tonight i don't see it, so i'll go type something up, but im not sure anything will result from it. if it was open source i'd try to fix it myself.

jeff464, 2025-01-31:
Bummer! Are there open alternatives? That would be an enormous help, but truth be told, I'm just happy it's working now. If I need to spend a little extra time uploading one sample at a time, that's totally fine!

beau-seidon, 2025-01-31:
try Bome Send SX again, and see if it lets you select multiple files to send in batch. I have never used it before.
If not, there's lots of open source midi libraries, i can slap a script together in python or something soon and see what happens.

beau-seidon, 2025-01-31:
if you're a linux guy, there are instructions for using the `amidi -p <MIDI device> -s <sysex file path>` command to upload samples, and you could easily google up how to write a for-loop in a bash script to batch upload.

jeff464, 2025-01-31:
I'm not too knowledgeable when it comes to Linux, unfortunately. It's on my bucket list, and this might push me to jump in. As far as Borne goes, it doesn't look like there's a way to send bulk files. No biggie!

beau-seidon, 2025-01-31:
well now i want to use wxWidgets or something to make a simple cross platform GUI application to convert and upload samples, using the current resources like sox, and gensysex, and whatever i else i come up with to send the sysex files.
that's going on my to-do list! not super close to the top, but it's on there now...

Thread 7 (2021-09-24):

Nesizer goes crazy when cell battery is inserted

KeenVox, 2021-09-24:
Hi,

I build the NESizer2 and everything works great so far, as long as I don't insert the battery for patch saving.
When I power on the NESizer with the battery inserted the machine goes crazy. All soundwaves are activated and it starts to play a random melody while showing random numbers on the display. Without battery everthing works fine again.

Any suggestions for troubleshooting?

KeenVox, 2021-09-24:
Seems to be a ram problem. When I remove the left chip, anything works like it should...

Jaffe-, 2021-09-24:
I think the RAM chip is probably OK, but the contents are just random.
First time you use the nesizer with new battery you should also do a memory reset to format the storage system.
I would do these:

PATCH_RESET (button 8 - first button on second row counting from the left)
PATTERN_FORMAT (button 9 - second button on second row counting from the left)
INIT_SETTINGS (button 11 )
SAMPLE_FORMAT (button 14)

(Of course there should be one single option to do all these at once...)

Do this with both RAM chips installed. When you have done it, turn power off and on again and it should hopefully work!

KeenVox, 2021-09-24:
Thanks for your reply. That helped. It's a bit sad, the ram melody was quiet nice. :-)

When I reseted the settings (11) and formated the samples (14) the Nesizer crashed and freezed, could this be because there were no settings or samples loaded onto it?
Beside this everything works fine.

Jaffe-, 2021-09-24:
It should not crash after you reboot it? Doing the various formatting operations can take some time though, and the UI will be frozen until it is done.

KeenVox, 2021-09-24:
Ah, okay. Maybe I was too fast to turn it off when I pressed SAMPLE_FORMAT. The first two actions (8,9) where so fast, so I thought the system crashed.
Will try it again.

KeenVox, 2021-09-24:
> It should not crash after you reboot it? Doing the various formatting operations can take some time though, and the UI will be frozen until it is done.

Everything seems to work like it should now. But I have on little problem left. When I start the synth, there's a hanging note on the noise channel. I have to play a note on the noise channel once to make it stop, after that, everthying is fine.
I'm using a famicon clone chip, could that be the cause here?

Jaffe-, 2021-09-24:
I remember this being an issue. If you find a fix for it, feel free to make a pull request! :)
And congratulations for building what I would think is the second working nesizer!

KeenVox, 2021-09-25:
Ah, ok. Good to know. If I ever get into coding, I will try my best. 😆
Thanks for the kind words. I don't get why your nesizer didn't get more recognized. It's a really nice and complex synth  🙂.
The only problem for others may only be to source some parts, sadly.

KeenVox, 2021-09-25:
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

beau-seidon, 2023-06-22:
> Thanks for your reply. That helped. It's a bit sad, the ram melody was quiet nice. :-)
>
> When I reseted the settings (11) and formated the samples (14) the Nesizer crashed and freezed, could this be because there were no settings or samples loaded onto it? Beside this everything works fine.

When I booted for the first time, I experienced the same noisy looping sequence, and since I read this thread before I built it, I decided to record a sample of it before formatting the RAM.
If you would like a copy the recording for your own use, I would be happy to send it to you.

beau-seidon, 2023-06-23:
> > It should not crash after you reboot it? Doing the various formatting operations can take some time though, and the UI will be frozen until it is done.
>
> Everything seems to work like it should now. But I have on little problem left. When I start the synth, there's a hanging note on the noise channel. I have to play a note on the noise channel once to make it stop, after that, everthying is fine. I'm using a famicon clone chip, could that be the cause here?

> I remember this being an issue. If you find a fix for it, feel free to make a pull request! :) And congratulations for building what I would think is the second working nesizer!

I reckon it might stop the stuck noise and triangle notes after a reboot if you called some "channel_initializer" function just once after everything else starts up.
It might simply wrap the calls to `assigner_notify_note_on(midi_channel, 60)` and then `assigner_notify_note_off(midi_channel, 60)` on all MIDI channels (or just the MIDI channels assigned to those oscillators, since they are stored) with data1 as Middle C or maybe something less audible.

Since playing notes un-sticks the channels, and those are the called functions when notes are played, just call 'em right away to un-stick them preemptively.

It's more of a workaround than a proper fix, but I'll see if I can make it work locally on mine and report how it goes.

KeenVox, 2023-06-30:
That sounds awesome,. If your modified code works, I would love to get the hex, to update mine. The sticky channel really gets on you nerve after some boot ups. ;)

beau-seidon, 2023-07-10:
This .hex works to fix the hung noise/triangle note at boot, with the following requirements:

1. Both the triangle channel and the noise channel must be assigned to any MIDI Channel 1-16. The default is 0 after flashing, so go change them. They don't have to be assigned to the same channel.

2. The triangle channel and noise channel must both be enabled at startup. I found that saving preset 00 with default settings and all channels ON works perfectly.

[nesizer_fw_startuphack.zip](https://github.com/Jaffe-/NESizer2/files/11997884/nesizer_fw_startuphack.zip)

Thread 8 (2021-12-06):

Unable to compile firmware properly with avr-gcc

SonicJr623, 2021-12-06:
Hello Jaffe.

Sorry to bother you.
I would like to build my own NESizer, but I am unable to compile the firmware properly.

Here are the exact steps I tried to compile.
I first installed avr-gcc and git for Windows and cloned the repository.
Then I run 'make' from the cloned repository using the git bash shell.
However, I get the following error message.

In file included from main.c:29:
apu/apu.h:29:10: fatal error: sample/sample.h: No such file or directory
   29 | #include "sample/sample.h"
        |          ^~~~~~~~~~~~~~~~~
compilation terminated.
make: *** [Makefile:41: main.o] Error 1

Could you please help me with some advice? Thank you very much!

Also, if it's convenient for you, could you please send me the compiled firmware hex code via email? My email address is sonic@mukoi dot com

Best regards
Sonic

Jaffe-, 2021-12-06:
Hi Sonic,

This looks like a fairly simple compilation issue where the include path given to gcc is wrong. This is done in line 15 of Makefile, with the option `-I$(shell pwd)`. I suspect the "shell pwd" part might not work in your case. You can try to replace this with a hard coded path to where the code is, something like `-I C:\...`

Another option, which I would recommend is to install Windows Subsystem for Linux (WSL), which would provide a better environment to build the code in.

SonicJr623, 2021-12-07:
>
Hi Jaffe,

I tried hard-coding the code path into the Makefile and now I can compile the firmware properly, thanks a lot!

Best regards
Sonic

Closed 2021-12-07.

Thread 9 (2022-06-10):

How can I compile the sources

cgerrist, 2022-06-10:
HI,

with with compiler do you compile the project.
There is no Project description in the src folder.
I try code from microsoft but it did not compile without errors.

Chris

Jaffe-, 2022-06-12:
Hi Chris,
The code has to be compiled for the Atmega328 with avr-gcc. On Linux it should be enough to install avr-gcc and avr-libc,  and Make. It can then be compiled by running make.
I have not tried to compile it on Windows. I think the easiest way to do it would be to install WSL (Windows Subsystem for Linux) and follow the previous description for Linux.
I guess it can also be compiled by installing Atmel Studio.

cgerrist, 2022-06-12:
Thanks for the reply. I live in Holland and we have only the PAL version of the sound chip. This chip is different the RP2A07. I am using a Mac. Tonight I wil try to compile it again.

Jaffe-, 2022-06-12:
On Mac it should be possible to install avr-gcc as well. I found this, for example: https://bytes.usc.edu/ee109/macos-64-bit-toolchain/
Seems like you can get avr-gcc from installing the Arduino IDE (some Arduinos use the same chip and the IDE uses avr-gcc to compile the arduino code).

You also need the avrdude tool to actually flash the Atmega chip with the compiled firmware.

Regarding RP2A07 it should work fine, the atmega firmware will determine which version is installed and do the necessary compensation for PAL vs NTSC clock speeds.

cgerrist, 2022-06-12:
Thank, I was reading about this chip and is a combine with the 6502 processor. When I had a Apple II I was programming in assembler for the 6502. So I got warm feelings for this chip 😀. This programming was a long time ago. When I was 14. And now I am 58.

cgerrist, 2022-06-13:
Hi, I was able to compile the sources. output: sesizer_fw.elf, hex and map

This was the easy step I think :-)

Thanks for the help

Jaffe-, 2022-06-13:
> Thank, I was reading about this chip and is a combine with the 6502 processor. When I had a Apple II I was programming in assembler for the 6502. So I got warm feelings for this chip grinning. This programming was a long time ago. When I was 14. And now I am 58.

It should be familiar to you then, you can see in the sources how the 6502 in the 2A07 chip is 'tricked' into doing what we want (load audio synthesizer registers) by just force-feeding it instructions from the Atmega microcontroller :)

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

That's great!

cgerrist, 2022-06-13:
> It should be familiar to you then, you can see in the sources how the 6502 in the 2A07 chip is 'tricked' into doing what we want (load audio synthesizer registers) by just force-feeding it instructions from the Atmega microcontroller :)

I did not read all the sources yet so I did not see this part of the code. Is this all Atmega code or do you have a part logic that you dumb in the memory of the 6502 and a separate part ATmega?

Jaffe-, 2022-06-13:
The 6502 does not have any memory connected, the address bus is just unconnected. The Atmega is just giving it instructions on the data bus and waits for the appropriate number of clock cycles before putting a new one on the bus. It is described in more detail in https://github.com/Jaffe-/NESizer2/blob/master/docs/software.md

The first Nesizer design was based on only the 2A03/2A07 but it turned out to be quite limited how flexible the resulting synthesizer would be as an instrument. The Atmega is quite a bit faster and can do more of the extra computations needed for LFOs, envelopes, sequencing, MIDI etc.
I did consider to share the burden between the two by putting some code in a RAM or ROM for the 6502 to run and make a sort of command interface between the Atmega and the 6502, but when I found the idea of just spoon-feeding the 6502 in another project, I went with that solution. Running code in the 6502 would require more components and be a more complex design.

cgerrist, 2022-06-13:
I look to the layout of the NES, I think it is very easy to connect memory to the CPU. The NES has one 128x8 DRAM.
The NeSizer use 2 x 512x8 chips. Why do you need this? It is not connected to the adresbus

cgerrist, 2022-06-14:
Good morning. I did read hardware.md and looked at the layout I do not understand how the 2 x 512 K eat is connected to the address latch. Also How will the 2A03 make connection to the memory. I looked at the NES schema and is it not easier to use the RAM from the NES. Maybe stupid questions. But I would like to know how everting works before I build The NESizer. Did you order the PCB or made it yourself?

Chris

Jaffe-, 2022-06-14:
> But I would like to know how everting works before I build The NESizer. In addition, did you order the PCB or made it yourself?
>
> Chris

I ordered PCB from a manufacturing service called Elecrow. Don't know if they are operational any more, but there are other similar services that manufacture PCBs quite cheaply these days.

cgerrist, 2022-06-14:
Normally I use my cnc to mill the pcb. Maybe I do this also with this project. Thanks for the clarification.

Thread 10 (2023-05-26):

BOM Inquiry

beau-seidon, 2023-05-26:
First, this project is amazing, and thank you for sharing it.

I'm prepping to build one right now, and I just sent the 2 PCB's to be manufactured (with a red upper and blue lower board like Super Mario's clothes, see attached pic!).

My question is this: in the BOM, IC13 component DS1210 has no quantity, is it no longer required?
I noticed that in the last hardware.md commit (8 years ago, wow) you removed references to DS1210.
I compared the before and after, and see that a transistor switch circuit keeps the SRAM powered now instead, but DS1210 is still on the BOM. Is this just for reference / historical purposes?

It is also discontinued from Mouser but there is an equivalent replacement. If I don't need it, I'll save 10 bucks.

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

Jaffe-, 2023-05-27:
Hi,

Happy to share the project, and always cool when someone wants to make it! I know about two people who have tried to build it before, and at least one of them got it working (see other github issues) - so it is possible! :)

To look at the history of the hardware design you should look at the history for the schematic and board files. I didn't always update the hardware.md file when I did changes to the board designs.

As I recall it, the DS1210 was out for a while because I thought I could design the battery backup circuit without using that component, but it turned out to be way too battery consuming. If I did it today I would use CMOS chips or FETs for that.
Anyway, I ended up putting the DS1210 back. The correct quantity should be 1 (as seen on the board). But if it is hard to get a hold of, it could be worthwhile to check if there are other compatible ICs for this.

Please also take BOM.xls with a little grain of salt, I would definitely double check if there is anything missing in it. It should be pretty much in sync with the boards, but a resistor or two might be missing or have the wrong value. Definitely a good idea to have a cheap multi resistor kit when doing this project I think.

Love the PCB colors, good luck with the build!

beau-seidon, 2023-05-27:
Thanks for responding!
I have read the other issues here and all the discussion I could find on Reddit and your YouTube videos, as well as some of the general info on NESDev, and looked over some of the IC datasheets, a bunch of other things.
I'm trying to be as prepared as possible since I've only made a few Atmega based projects before, and none this size.

The DS1210 is marked obsolete and is replaced by MXD1210CPA+, and another with a different temperature tolerance.
The difference between new and the original is the operating supply current which was reduced from 5 mA to 230 uA.
Description of function, pinout, and recommended circuit from datasheets are the same.

Ok, so if the mainboard.sch and panel.sch files are reliable, I'll go part-by-part thru the BOM and diagrams and check them all and update the BOM if I find any differences.
If the MXD1210CPA+ works and I get the whole thing running without melting something, I'll include that Mouser part number in the BOM as well, since it is well-stocked.

I have a few of the listed things already. Lots of resistors and a some caps and a couple sockets and things.
Was going to load the BOM into Mouser's template, and then subtract the parts I have.

beau-seidon, 2023-06-21:
It's alive!

It works great. I'm going to upload an updated BOM that matches your latest .sch file with in-stock Mouser part numbers, then type up a guide with pics explaining how I ordered the boards, built it, and programmed it using an Arduino Uno (as an ISP).
I'll write it at a n00b level, mostly because thats the extent of my capability, but also so nobody else has to struggle to figure any of it out like I did. Although that may have been the most fulfilling part.

I know I probably could have asked more for assistance, you have been super helpful and I gained much from reading your responses to others' questions, but I wanted to learn all that I could on my own first.
But this is such a cool project, I want anyone to be able to build it worry free.

The only major issue so far is a firmware bug in midi.c, regarding how it handles MIDI messages comprised of a NoteOn status byte with Velocity=0 in data.

Per the MIDI spec, any compliant synth should handle that command identically to a NoteOff message, but NESizer treats it like any other NoteOn command.

I found this because Cakewalk (my favorite DAW) apparently stops MIDI notes using the NoteOn,Vel=0 method.
Neither my hardware MIDI keyboard, nor Ableton Live, nor FL Studio had any issues playing sequences through the NESizer, but it spazzed when I fed it notes from Cakewalk.
I experimentally passed the MIDI messages from Cakewalk through a loopback driver into MIDI-OX and found the difference in the status portion.

I'm still learning C++ and have been super busy lately, so I haven't tried reprogramming it yet.
In NESizer2/src/midi/midi.c, line 63 is the case MIDI_CMD_NOTE_ON inside the midi_channel_apply function. Thats where the bug resides.
The following if statement should check the data byte when it gets a NoteOn command, to see if the velocity is 0, and when true just do the same thing as the MIDI_CMD_NOTE_OFF case.
I'm going to hack at it when I have time to see if I can get it to recompile and play nice with Cakewalk.

Also, here are a few pics of my finished boards!
I'm going to be recording some tunes with my new favorite toy in the future and I'll post a link to them here.

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

beau-seidon, 2023-06-22:
Programming with Arduino as ISP was very easy after watching a couple Youtube videos about avrdude and setting fuse bits.
This one was particularly helpful: https://www.youtube.com/watch?v=Q2DakPocvfs

I used the Arduino Uno dev board rather the the RaspberryPi GPIO pins because the Pi doesn't tolerate 5 V on its pins, and the Atmega in the NESizer would be operating at 5 V.
I read that it's fine to program one with a Pi, as long as the Atmega is supplied with 3.3 V instead of 5 V.

Arduino IDE comes with an example sketch to turn any Arduino board into an ISP programmer.
After uploading that to my Uno, it was just a matter of matching the right pins with jumper wires. I did connect it directly to the ISP header on the board.
I powered the NESizer using a 12 V DC (center-positive) power supply, and left the 5 V pins disconnected between the Arduino and the ISP. Arduino was powered by the USB cable connected to my laptop.
I'll detail all this stuff a little bit more in my build guide

Tonight I slightly modified the midi.c, ui.c, and ui.h code then recompiled and everything seems to be working fine.
My board responds correctly now to Cakewalk's MIDI note commands and I'm super excited about it!
I forked and modified and created a pull request on here too. It was my first time, I hope I did it right.

As far as the user interface, I did notice that the silkscreen labels for some of the buttons on the PCB don't match the labels in the manual, but the manual seems to match what the buttons do when I poke them, so I have been using that.
Might print some tiny stickers for the caps.
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
beau-seidon, 2024-06-18:
Yes try to get the male pins centered between the boards so they make a snug connection in both sets of sockets

If that doesn't work: for testing purposes, detach your boards from the standoffs and connect them with breadboard jumper wires if you have any. Just for the time it takes to load the software and test functionality, to rule out other issues.

If there's extra room between the boards, you could try to carefully trim or sand the standoffs to a shorter height (assuming they are entirely plastic without metal thread inserts), but you'll have to do it carefully so they are all the same, and not too short such that the voltage regulator touches the top panel.

jeff464, 2024-06-18:
Solder tested okay with the multimeter, so I think I'm okay there. I thought maybe I installed this wrong since others seem to have the same size header without connection issues. That said, they really do seem a little too short, so if the components seem to be installed okay in the photo, I'll just swap the headers with something much longer. Good call on sanding the standoffs and using jumper wire, though. Unfortunately I don't have more than a few wires, and the center of the standoffs are metal.

I attached another photo showing the length discrepancy. This is odd if others got it to work.
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

jeff464, 2024-06-18:
I just realized I have snipped leads from the LEDs I could probably use temporarily. ;)

beau-seidon, 2024-06-18:
I just checked my order history, and yes [649-68602-116HLF](https://www.mouser.com/ProductDetail/Amphenol-FCI/68602-116HLF?qs=PCEjGSkOlsa%252B8AOHtx6MSg%3D%3D) is the part number I used for the 2x8 pin connector.

What is the part number for your standoffs? I wonder if they are ever so slightly longer than mine.
I opted for the plain nylon 25 mm [144-CBTS115A](https://www.mouser.com/ProductDetail/Essentra/CBTS115A?qs=PzGy0jfpSMt5%2F9rQWt9IYQ%3D%3D).

[200-TSW10808TD](https://www.mouser.com/ProductDetail/Samtec/TSW-108-08-T-D?qs=rU5fayqh%252BE0hIpjMtL674Q%3D%3D) may be a better male connector for this, the termination posts are longer (5.08 mm vs 3.81 mm).

beau-seidon, 2024-06-18:
I just checked my build photos and noticed yours is put together differently from mine. You soldered both female connectors to the boards, whereas I soldered the male header to the bottom board and used the female+male with the long legs as the middle piece.

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

beau-seidon, 2024-06-18:
Smash it and start over. The one on my BOM is one of 2 parts not available lol.

The part I used was 992-8FX1L-254MM, but that one doesn't even have a page anymore on Mouser. Probably something to do with politics.
I can't even find a datasheet for it, the manufacturer website is gone and everything.

I managed to get some info via wayback machine and this part should be equivalent: [801-87-008-53-001101](https://www.mouser.com/ProductDetail/Preci-dip/801-87-008-53-001101?qs=q5BRkYolQ3gnRfYCsKSECg%3D%3D)
Or you could just search "stackable header" and choose your favorite. The male pins are ~12 mm.

jeff464, 2024-06-18:
Yep. Just threw the build in the trash. Oh well!

Standoffs look to be 25mm, but the photo confirms what I feared - I placed the components on the wrong way. The weird part is that I never had to snip the leads on the female sockets, so I would imagine it's all the same length anyway if all three parts are the same, BUT I guess not lol. Not a huge deal.

Thanks for the quick research. I sincerely appreciate it and the info helps speed things up a bit. Super weird that the original part vanished from Mouser. What would even cause that? 0_o

beau-seidon, 2024-06-18:
Dunno. There should have been 2 of these long-legged gals:
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

But since they're already glued in place, rather than messing around chopping parts off and resoldering, just get another longer male header like this to connect them:

> [200-TSW10808TD](https://www.mouser.com/ProductDetail/Samtec/TSW-108-08-T-D?qs=rU5fayqh%252BE0hIpjMtL674Q%3D%3D) may be a better male connector for this, the termination posts are longer (5.08 mm vs 3.81 mm).

jeff464, 2024-06-18:
Awesome! Thank you. Side note - I went out and bought some breadboard jumper wires and connected the PCBs. The unit turned on with solid LEDs for a few seconds which I assume is some sort of initialization process, but then the LEDs/display started looking like they are twitching. Nothing is working, but I'll have to test again later once I buy a coin battery. I'm thinking that's the main issue now.

jeff464, 2024-06-19:
Okay, so I bought a battery and the unit is still misbehaving. I will now move this over to the "Build Problems" thread.

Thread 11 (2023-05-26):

AVR Programming Method

beau-seidon, 2023-05-26:
I'm new to interacting on GitHub, so my I apologize if it's poor etiquette to create new issues on your project for basic questions like these.

My intention is to stick the Atmega328 on a breadboard with the bare-minimum required components as shown in the Breadboard Arduino reference here:
https://docs.arduino.cc/built-in-examples/arduino-isp/ArduinoToBreadboard
and then power and program it via my Raspberry Pi's GPIO / SPI pins using avrdude before installing.

Is that what you'd recommend or is there a better way?

beau-seidon, 2023-05-26:
I also have an Arduino Uno board I can drop the Atmega into, which would be much simpler and my preferred method if it would work,

Jaffe-, 2023-05-27:
Hi Beau,

The way I have been doing the programming is to just have the Atmega328 seated in the board and use the 6 pin header (SV1)  on the board to program it. The pin header provides an ISP (In-circuit Serial Programming) interface directly to the Atmega. I've used an old ICE programmer for that, but it should be pretty straight forward to use a Raspberry Pi as an ISP programmer: https://learn.adafruit.com/program-an-avr-or-arduino-using-raspberry-pi-gpio-pins/installation

There are probably many ways to go about this, but the reason why I recommend to just keep the Atmega in the board when programming, is that the Atmega will be programmed with new fuse settings which change the clocking from internal oscillator to using an external clock. So after the first time the Atmega has been programmed and gotten new fuse settings, it will not be possible to program again without an external clock running. Since the NESizer already has that clock there, it is easiest to just keep the Atmega in the board.

beau-seidon, 2023-05-27:
Perfect. That's even simpler and makes it less likely for me to screw it all up.
The external clock I was going to use is a 16 MHZ crystal with caps, whereas yours uses a 20 connected to an inverter.
I was concerned about the clock difference which is why I asked.

Also that's one of the links I have bookmarked for programming reference, so at least I'm on the right path there.

Thank you!

beau-seidon, 2023-05-27:
Would it be a good idea to assemble everything and then program the Atmega before inserting the 2A03 in its socket, or does it need to be in there when I program it?

My biggest priority is to protect the 2A03, since it is the only precious component.

Jaffe-, 2023-05-27:
You can program it without the 2A03 in there. I think all you would need on the board to just program the Atmega is the power supply, ISP connector and clock circuit.

Note that you can not test that the Atmega is actually working correctly until a 2A03 is inserted, because the initialization code is going to hang if it does not get contact with the 2A03. But if you manage to program it with avrdude and set the fuses, than you can be very sure that the Atmega itself is going to work.

Jaffe-, 2023-05-27:
I think taking it out and using a 16 MHz crystal would not work, because the fuse setting is to use an external clock on XTAL1 - not external crystal with capacitors connected across XTAL1 - XTAL2.

The inverters in the circuit diagram are there to make a clock signal together with the crystal and capacitors. It is a typical and easy way to make a clock generator circuit. The reason why this is done and not connecting the crystal and capacitors directly to the Atmega, is that the same clock is also used to clock the 2A03, so that the two can be exactly synchronized.

If you made a full clock generator circuit around the 16 MHz crystal and connected it to XTAL1, then I think it would also work fine to program it on an external breadboard.

beau-seidon, 2023-06-22:
When I set the ATmega fuse bits, I used the following settings:

    -U lfuse:w:0xe0:m -U hfuse:w:0xd9:m -U efuse:w:0xff:m

which, for ATmega328P, corresponds to:

    Ext. Clock, Start-up time PWRDWN/RESET: 6 CK/14 CK + 65 ms; [CKSEL=0000 SUT=10] and no internal clock division.

Other than the the External Clock, and no division, I left everything else default. Does that sound right to you?
Obviously, it's at least close, because the NESizer is working, but I want it to be right.

I used the following calculator to determine what arguments to pass to avrdude
https://www.engbedded.com/fusecalc/

Jaffe-, 2023-06-22:
Yes, that is the same settings I have used!

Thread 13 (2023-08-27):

Build Errors

circuitcreature, 2023-08-27:
I have the synth all built and as mentioned in another issue I used the MXD1210CPA+ instead of the DS1210. I am able to flash the Atmega using an Arduino and set the fuses to  E:FF, H:DF, L:E0, or  E:FF, H:D9, L:E0.

The issue is when I power it up all the LEDs light up and it doesn't produce any sounds. I have also tried the init within the settings using buttons 8,9,11, and 14, but nothing appears to happen after pressing 11 and 14. Pressing 8 then 9 does cause the LEDs to brighten and a sequence starts on the screen for about a second.

I can however test the chip type correctly with a returned value of 12.

Once after powering on it did start making sounds, but I haven't been able to reproduce that.

Any troubleshooting ideas?

Jaffe-, 2023-08-27:
It is normal for it to behave strangely at first bootup, because the RAM just contains junk. The RAM is initialized properly when going to the settings mode and using 8, 9 and 11. Next boot after this it should work more as expected.
This is one of the less finished parts of the SW, it should really just auto detect corrupt memory and initialize automatically.

If it it does not help to press, 8, 9 and 11 (when in settings mode) and power cycling, then I suspect that something might be wrong with the SRAM memories or surrounding circuitry. I would check the RAM chips (IC10, IC11) and the address latches (IC7, IC8, IC9) and the address decoder IC5 for any soldering issues. Same for the battery backup circuitry (DS1210). And of course, just to double check, you do have a battery installed?

circuitcreature, 2023-08-27:
I put the battery in and tried the init and power cycling and everything is working. I still have the issue with the LEDs always being lit, but I can live with that.  I'll have to check my BOM, but I ended up using a different LED from the committed BOM, so there might be something in there.
Great project thank you.

Jaffe-, 2023-08-27:
That sounds strange. Are they always on, but brighter when actually supposed to be lit? Otherwise it sounds like it would be hard to use ...

I pushed some new code now, it checks whether the RAM has become corrupted. If it is, 'cr' will flash in the display at boot and the RAM will be properly initialized (same as manually performing it in the settings menu).

circuitcreature, 2023-08-27:
Correct, they are alwasy on and sometimes get brighter, this is only noticeable when the init runs after pressing 8 => 9, but other than that there is no indication when on a specific mode. I used mouser #696-SSL-LX3054IID, but they look to be mostly the same as the OG BOM.

Thank you for the code update. I'll give that a try next time I get the flasher setup.

Jaffe-, 2023-08-27:
Sounds like something might be wrong on the panel board. I would check the row and column latches there. Do all the LEDs do this, or just some of them? What about the 7 segment display?
The LEDs are very similar to the ones in the BOM, so I don't think they are the issue here.

circuitcreature, 2023-08-28:
Double checked everything and it looks fine. It only happens to the LEDs, the display displays 00 when nothing has been selected.
As for the update, I get a battery warning and cl on every boot and it wipes all settings.

beau-seidon, 2023-08-28:
There are a few items in the committed BOM which are obsolete. I had to select suitable replacements. Also @Jaffe- did mention, in a reply to one of my Issues, that the BOM is not as up to date as the schematic. One example I found is that the part number listed in the BOM for the bus resistor on the top board is for a 4.9k instead of the 15k from the schematic.

When I built mine, I opened the .sch file in Eagle (free version) and exported a new parts list, then carefully compared the committed BOM to the new list. I used both as a reference to build my own cart on Mouser, defaulting to the schematic when I found conflicts.

I have attached an export of my Mouser cart with all the parts I used in my build, for you reference.
Mine is working great without any electronics issues.

[exported_mouser_cart_(nesizer_only).xls](https://github.com/Jaffe-/NESizer2/files/12450320/exported_mouser_cart_.nesizer_only.xls)

circuitcreature, 2023-08-28:
Thank you @beau-seidon I'll compare yours to mine and update as needed. I'll report back if I order any new parts.

Jaffe-, 2023-08-28:
> Double checked everything and it looks fine. It only happens to the LEDs, the display displays 00 when nothing has been selected. As for the update, I get a battery warning and cr on every boot and it wipes all previous settings, like midi channels.

Does not sound good! I think the cr error should only occur once the first time (and yes, the settings will be erased too. I should have warned about this...) After it has written the expected signature to RAM, it should work fine after the next boot. If it does not, it means that the battery backup is not working and has corrupted the RAM.

I will check whether the battery fault is now always showing with a fresh battery also. It might need some more work to be reliable.

beau-seidon, 2023-08-28:
> Thank you @beau-seidon I'll compare yours to mine and update as needed. I'll report back if I order any new parts.
> edit:
> Ordered more parts, the resistor array, clock, and diodes.

If you are talking about the switching diodes, you can use the ones in the BOM (1N4148 are equivalent to the 1N914 diodes that I bought, and there will be no functional difference).

The clock will make an enormous difference if you got the wrong one. Particularly if it oscillates at a different frequency than the design. If the freq. is wrong though I wouldn't expect it to boot at all.

Not sure what effect the resistor array difference would make, other than potentially passing too much current through the buttons if several are pressed at once? Full disclosure: I bought the wrong one too and almost said screw it I'll install it anyway lol. In the end I decided not to and got a 15k replacement before turning it on.

I'm not implying anything here, but triple check that all your IC's are oriented correctly. I booted it up the first time with my 2A03 in backwards because I am stupid, but it didn't hurt anything as far as I can tell. It still goes beep boop.

circuitcreature, 2023-08-28:
ICs look good. I also picked up more latches, to test out. I might have messed something up on first boot, i had the pins off by one with the mainboard and panel. As far for the cystal it is 20mhz, worse case I'll build another one.

Jaffe-, 2023-08-30:
@circuitcreature  Let me know what you find out. If you know some programming, you could try to change the update speed of the LEDs in the code. See src/task/task.c line 84 which defines the update rate for the LED refresh. If you increase this period, it should update slower and perhaps make it easier to debug. You could also try and just locally mod the code to add a mechanism to single-step the LED rows and columns from one of the buttons.

Regarding the battery level and corrupt RAM warnings, it just dawned on me that the board I currently have fully assembled is an older v0.5 board with some mods, so the battery related stuff is not the same as in the latest design. I should build a new main board based off the latest version before attempting to write any clever code, I think. I will revert the change related to battery low and memory corruption errors until I can test it on a new board.

Just out of curiosity, what do you see when you press the battery level indicator in settings? (press and hold second rightmost button on first row)
Same for you as well, @beau-seidon, what does the battery level indicator show in your case?

circuitcreature, 2023-08-30:
@Jaffe- I've been digging around in the code, it's been a while with C. I'll look at the refresh rate.
As for the battery it displays 45. I'm pretty sure this one is new, I can dig around and see if I have another to test.

beau-seidon, 2023-09-02:
> Just out of curiosity, what do you see when you press the battery level indicator in settings? (press and hold second rightmost button on first row) Same for you as well, @beau-seidon, what does the battery level indicator show in your case?

I haven't updated my NESizer with the most recent code you pushed.
It is running a hex with my NoteOn&Vel=0 changes, and a hack to mute the output at boot, but no other mods.

When I check battery voltage by selecting Settings mode, and holding Button 7, I get **4.3** on my segment LED.
I can update the firmware with your most recent code and check again if you'd like.
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
jeff464, 2024-06-21:
Thanks again for the assistance. I feel like I should be paying you. Usually I'm not this awful at DIY, I swear.

I'll follow these instructions first thing tomorrow morning. Looking forward to building this thing and then giving up. ;)

jeff464, 2024-06-21:
First snag - there was no "open with" in the right-click menu for that folder. Obviously not a huge deal. I just opened the folder in VSC and everything seemed to populate. Cool.

Second snag - set fuses returns an error:

Selected fuses: [lfuse = 0xE0, hfuse = 0xD9, efuse = 0XFF]
Setting fuses
avrdude error: syntax error [C:\Users\Unknown:1]
avrdude error: unable to process system wide configuration file C:\Users\Unknown
*** [fuses] Error 1
=============================================================================== [FAILED] Took 3.92 seconds ===============================================================================
 *  The terminal process "C:\Users\Unknown User\.platformio\penv\Scripts\platformio.exe 'run', '--target', 'fuses', '--environment', 'ATmega328P'" terminated with exit code: 1.
 *  Terminal will be reused by tasks, press any key to close it.

 Something *REALLY* doesn't want me to build this thing.

jeff464, 2024-06-21:
Thinking about this, it might have to do with the user folder having a space in the name. "Unknown" is only part of the username/folder, and the error seems to throw at that space. Short of editing the win registry or creating a new admin account/porting over all installed apps and programs (not a chance) I think this might officially be outside of the scope of NESizer. What a nightmare.

circuitcreature, 2024-06-21:
It's been awhile since I've worked in the Windows CLI. You might want to try putting the paths in double quotes. e.g. "C:\User\Unknown ..."
You can also use the tab key to auto complete paths when typing and that should auto add the quotes.

beau-seidon, 2024-06-21:
> Thinking about this, it might have to do with the user folder having a space in the name. "Unknown" is only part of the username/folder, and the error seems to throw at that space

Yep looks like you found a bug in the python scripts that do the fuse burning and uploading. It seems to be adding extra quotes around your path which cancel out the original quotes that allow spaces in the path string. According to the PR for the issue linked below, the scripts were fixed, and I checked those installed on my system and mine reflect the PR changes.

https://github.com/platformio/platform-atmelavr/issues/297

Apparently, it's not entirely fixed. Since it is still buggy on your system, go find that config file in

`C:\Users\"your user name"\.platformio\packages\tool-avrdude\avrdude.conf`

and copy it to a temporary folder in `C:\` (root directory).

Then replace line 30 in platformio.ini:
`    $PROJECT_PACKAGES_DIR/tool-avrdude/avrdude.conf`
with your path to that file. Something like:
`    "C:\tmp\avrdude.conf"`

jeff464, 2024-06-21:
Now I get a different error. This is the same error I was getting before when I realized it was no longer working. Everything is definitely hooked up properly.

Selected fuses: [lfuse = 0xE0, hfuse = 0xD9, efuse = 0XFF]
Setting fuses
avrdude: AVR device initialized and ready to accept instructions
avrdude: device signature =
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

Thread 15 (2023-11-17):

Midi CC integration

circuitcreature, 2023-11-17:
I already have this implemented on a branch and need to run a few more tests on it before I make a PR. Just creating an issue so that it can be tracked for any bugs.

beau-seidon, 2023-11-18:
This is very exciting. I was actually going to start work on implementing midi cc this week, but you beat me to it. I was going to try to stick closely to the implementation of the Famimimidi, but I do understand that the two devices work differently.

I installed your updated firmware last night to try it, and had some fun fiddling with cc params while the sequencer was playing.

I did find that with no midi channels assigned to the voices (all default of 0), that my Nesizer freaked out and would lock up and become unresponsive until a reboot. I was able to reproduce the problem, and the solution was the assignment of midi channels to the voices.

circuitcreature, 2023-11-19:
Ha, I was going to match the MidiNes, but ended up trying to match the midi cc defaults. I was thinking about creating a map with some different options to match other like Famimimidi and MidiNes.

I was able to crash mine as well, but wasn't sure if it was my controller. I'll get an update pushed soon.

jeff464, 2024-06-10:
Looking at this thread - is CC integration now available on the main NESizer build, or is it only just available in the forked build as of now? I'm curious because I have a Famimimidi and this functionality would go very well with my current MIDI templates.

Also, since you're familiar with the Famimimidi  - are you able to decipher any of the MIDI commands/instructions regarding macros/patch storage? I was never able to figure this out. Way over my head!

circuitcreature, 2024-06-10:
@jeff464 CC integration is only on the forked branch right now. My last commit is untested but should work fine. Im only familiar with Famimimidi's documentation on it's midi protocol, but the more I dug into it, the more it matched the standard midi maps for CC, so I started to just map CC to those standards.
Actually if you test this branch and have any pointers to have it work more closely to the Famimimidi, feel free to commit updates. I'm hoping to have my Nesizer working in a few weeks and I can test and make any code improvements.

beau-seidon, 2024-06-10:
> Looking at this thread - is CC integration now available on the main NESizer build, or is it only just available in the forked build as of now? I'm curious because I have a Famimimidi and this functionality would go very well with my current MIDI templates.
>
> Also, since you're familiar with the Famimimidi  - are you able to decipher any of the MIDI commands/instructions regarding macros/patch storage? I was never able to figure this out. Way over my head!

I finally got my hands on a Famimimidi a few weeks ago, and have been playing with it a lot!

Aside: I actually found the NESizer project in my search for a Famimimidi alternative, because hekekekun quit making them so Catskull couldn't get them anymore and there have been none available on eBay or Reverb etc. for a long time. I still like the NESizer better, but there are some things it needs, such as short period noise (will post about this specifically in a discussion thread soon).

Some time in the near future I'll be testing the fork with CC implementation more and see how it compares fo Fmm

No idea how to do macro/patch storage on Fmm yet. I'll look into it.

jeff464, 2024-06-10:
@circuitcreature - I'd love to test this (actually, I'd prefer to). However, I spent over 48 hours last week trying to figure out why my Win machine doesn't properly compile the NESizer code as a .hex file. I never figured it out, and it's something I'll eventually troubleshoot next week or so. If you were able to upload a compiled .hex, it would speed things up a bit. I'll throw it on the 328 and test as soon as my unit is fully built this week.

jeff464, 2024-06-10:
@beau-seidon - Yeah, I feel the pain. I've been an early adopter of the MIDINES (back when the carts still had the white paper labels) and have been following all of the different NES MIDI carts pop up and immediately disappear over the years. I found myself in Japan back in 2019 and purchased a few different MIDI carts from hekekekun directly, but despite this, I've been meaning to build the NESizer for what seems like ten years now. I'm glad to FINALLY jump in. :)

As far as the macro/patch storage goes, I attached an English translated manual. Looking at this again, it seems the user macro stuff is at CC45-CC59. Also, there a section about sysex setting user wavetable data for the sample channel. I don't suppose anyone knows anything about that either? I tried to wrap my mind around it all a few times, but never really got anywhere. :(
[Famimimidi_implement_chart_v10_NES.pdf](https://github.com/user-attachments/files/15775153/Famimimidi_implement_chart_v10_NES.pdf)

beau-seidon, 2024-06-10:
> @circuitcreature - I'd love to test this (actually, I'd prefer to). However, I spent over 48 hours last week trying to figure out why my Win machine doesn't properly compile the NESizer code as a .hex file. I never figured it out, and it's something I'll eventually troubleshoot next week or so. If you were able to upload a compiled .hex, it would speed things up a bit. I'll throw it on the 328 and test as soon as my unit is fully built over the next day or two.

I had issues compiling using avr-gcc on Windows, but it worked perfectly on Linux. Have you tried WSL?
My recommendation is to use VSCode with the PlatformIO extension. That's how I do it now and it works great. Way easier than compiling via CLI.
Also @Jaffe- released the latest build in .hex format a few days ago, so you could also just download that and load it with avrdude.

jeff464, 2024-06-10:
@beau-seidon  Heh, yeah I reached out to Jaffe a few days ago when I was in the thick of troubleshooting avr-gcc. I requested a .hex compile, and he very kindly obliged. I apologize for any confusion - I personally don't have a fork of NESizer. In my previous message above, I was referring to a .hex compile of the NESizer version with MIDI CC enabled since (as far as I know) the official one doesn't have the CCs enabled.

I remember Jaffe mentioning the PlatformIO extension. That was next on my list to try. If that doesn't work, I'll likely openly beg for assistance here in the future. ;)

beau-seidon, 2024-06-10:
oops, I must have misread something, I'm at work, but will reread again later and fix my stupid.

circuitcreature, 2024-06-10:
@jeff464 I love my MidiNes. Grabbed one before Wayfar stopped responding to requests. This project spoke to me when i saw that you could upload samples to it.

I uploaded a release.[CC support](https://github.com/circuitcreature/NESizer2/releases/tag/Midi-CC)

I haven't setup PlatformIO to compile this version, but it should have compiled just fine.  I 100% recommend trying PIO out, it was the only way I could compile on my Win machine and it compiled perfect on my Mac even when the CLI was giving me grief.

jeff464, 2024-09-15:
Swinging back around to this - how are you all uploading hex files to the NESizer? Three hours in and it's still not obvious on how to do this with VSC/PlatformIO.
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
circuitcreature, 2024-09-16:
All merged. I'll be able to test this out later this week.  I also been wanting to test out the sample play back

circuitcreature, 2024-09-17:
To keep things easy to configure the CC number are the same across each the channels.

I think for the effect you are shooting for, it would be better to keep the tracks on separate midi channels but triggering the same notes. You will have much more control of the sounds this way.

Although it is interesting that the CC change isn't populating over the other channel when both are set to the same midi channel.

If you want, you can create an issue request and that can be fixed/added in.

jeff464, 2024-09-17:
Yeah, that method was the alternative. There's a bit more faffing around with setup/creating separate templates per channel with the MPC, but if it works it works! One and done.

I'll create an issue request for the others. Thanks!

beau-seidon, 2024-09-25:
> Also, since you're familiar with the Famimimidi - are you able to decipher any of the MIDI commands/instructions regarding macros/patch storage? I was never able to figure this out. Way over my head!

After programming NESizer and my TinyMIDI2CV gizmo to handle SysEx over the past week, its now pretty clear to me how to load custom waveforms into Famimimidi and map them to PrgChg numbers. Do you have any particular shapes you want (saw, sine, something wild, etc)? If you send a screenshot of some waveforms, I can approximate them in 16x16 arrays, then I can send you SysEx files you can simply load to Famimimidi with MIDIOX or similar. Will explain how.

Also going to work on pitched waveform playback on NESizer soon. I think it's totally doable with an 8+8 fixed point phase-accumulator and wavetables. The task manager can probably handle it since it prioritizes the dmc channel. Can use the master ~16khz Tick as the sample rate.

Just need to decide how to map it to MIDI. Maybe gonna make a 2nd loop mode in which you choose the waveform for each patch or upper/lower key group (using button UI or ProgramChange 100-127), and when you press the note, it decides how many elements to step thru the waveform array before starting over or how long to hold each element in the output register before stepping to the next based on the note you feed it. Made something similar on an Arduino ProMicro and it worked great.

jeff464, 2024-09-27:
Woah, that sounds WAY more in-depth than I initially thought. Please, do tell.  I don't have any particular waveforms in mind, but I would probably start with something like a supersaw lol. So I assume it's basically similar to how LSDJ handles custom wavetables, with the difference being that the user has to upload them to Famimimidi via sysex/midiox? Does the cart then store them?

This all sounds really exciting. I'll be updating to the latest NESizer firmware tonight. Stoked for those program changes!

beau-seidon, 2024-09-27:
Well the defining characteristic of a supersaw is that it is many normal saw waveforms playing simultaneously which are slightly out of tune so you get that wobbly chorus effect.

You can't really get the same sound with a single monophonic wave period unless its a super long period. It's gonna just be a jagged 16 sample waveform, but I'll see how it sounds and send you the SysEx to upload (with an explanation of the contents).

beau-seidon, 2024-09-28:
[FamiWaveGen.zip](https://github.com/user-attachments/files/17172033/FamiWaveGen.zip)
This should help!

I created a little GUI with the tremendous help of ChadGDP, which will spit out a Famimimidi compatible SysEx string that you can paste into MIDI-OX. Draw the wave shape you want (like you would in LSDJ) and click Generate SysEx.

beau-seidon, 2024-10-04:
@circuitcreature
The MIDI CC features from your fork were included in the recent PR.

I originally intended to merge my own new features separately from yours because you had your own PR open for MIDI CC, but I had previously merged your CC into my master branch, and then added more stuff, and made the SysEx bug fixes etc., and it was a whole thing to factor out and I didn't see the point fussing around trying to separate everything, so when @Jaffe- said I could merge it, I just did it.

In future I will definitely ask/consult before merging and closing things I didn't create.
I'll let you decide what to do with your MIDI CC PR, since your features are already incorporated but the PR now has conflicts.

circuitcreature, 2024-10-04:
@beau-seidon It's all good. What ever works easiest.

Closed 2024-10-04.

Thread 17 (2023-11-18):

A recent update is causing a compile error:

circuitcreature, 2023-11-18:
There was a recent update in sample.c that is causing a compile error:

```
sample/sample.o: in function `.L22':
sample.c:(.text.allocate_block+0x176): relocation truncated to fit: R_AVR_7_PCREL against `.L9'
collect2: error: ld returned 1 exit status
```

[This line](https://github.com/Jaffe-/NESizer2/blob/47f1c84201cfba7b5e93a79f0b9ed0e8b224490f/src/sample/sample.c#L289)

Jaffe-, 2023-11-18:
I don't get the same error on my end, which version of gcc are you using?

Jaffe-, 2023-11-18:
I wonder if this could be related to the change from -O3 to -O2 which was needed to fit in the new sample code and leave room for more features. The total size will be less now, but it requires that all the source files are recompiled before linking, otherwise the total size will be too large. Does it help if you force recompilation of all the sources?

beau-seidon, 2023-11-18:
I also don't get a compile error, in @Jaffe- latest commit, or @circuitcreature new commit with midi cc.

circuitcreature, 2023-11-18:
Im running gcc 13.2 on Mac.

Jaffe-, 2024-01-25:
Did you manage to resolve this by compiling all sources again? (delete all .o files)

circuitcreature, 2024-01-31:
I have not been able to get it to compile without changing it back to -O3.
I thought it was fixed last night, but it's showing up again. I've run make clean and also
`find ./ -type f \( -iname \*.o -o -iname \*.ilk -iname \*.map -o -iname \*.exp -iname \*.bin -o -iname \*.elf -o -iname \*.hex \) -delete`  just to make sure all comile files are gone.

beau-seidon, 2024-10-04:
@circuitcreature do you still get compile errors when you build with **make** and -O2 opt. without PlatformIO?
The current version compiles fine for me on Linux (RasPI OS - Buster [v10]) with no warnings or errors.

circuitcreature, 2024-10-04:
@beau-seidon I do. I can dig into this later. I might be able to dig up an older Mac to test on as well. Same error as before
`sample/sample.o: in function `.L22':
sample.c:(.text.allocate_block+0x176): relocation truncated to fit: R_AVR_7_PCREL against `.L9'
collect2: error: ld returned 1 exit status
make: *** [nesizer_fw.elf] Error 1
`

beau-seidon, 2024-10-04:
Ok, I'll dig into that as well to see what that function specifically does. Like, way down in there.
It may be related to the issues I'm having on my pitched-sample-playback branch! (I doubt it. I'm probably just doing something wrong)

My brother has a Mac now, I'll ask him to try and compile it on his lappy too to see if he gets the same error.
I have never been able to get make to work on Windows, but I'll fiddle around with it.

beau-seidon, 2024-10-04:
https://stackoverflow.com/questions/8188849/avr-linker-error-relocation-truncated-to-fit
also this seems relevant

circuitcreature, 2024-10-08:
Going to close this issue.
After digging in the code and trying umpteen things with Makefile, I purged avr-gcc and reinstalled it using a different version(14) than the default 9,  and It's compiling just fine now.

circuitcreature, 2024-10-08:
Closed. avr-gcc was out of date.
For anyone else that ends up here, MacOS terminal:
`brew remove avr-gcc`
`brew install avr-gcc@14`

Closed 2024-10-08.

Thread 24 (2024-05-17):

Setting the right fuses

NilocEidlog, 2024-05-17:
So .. after building this thing and programming it .. I turned it on and nothing happened. Lots of messing around ... anyway worked out how to set the fuses - tried doing a PR on the make file but I dont have permissions :(

Here's a nice little patch that allows you to do "make fuse" and it will burn the fuses correctly?? - pulled the values out of platformio.ini in this repo - all standard "arduino" fuse settings and any other avr stuff ive done in the past didnt work.

```
+fuse:
+       avrdude -u -c $(PROGRAMMER) -P usb -p $(MCU) -U efuse:w:0xFF:m -U lfuse:w:0xE0:m -U hfuse:w:0xD9:m
+
```

beau-seidon, 2024-05-20:
If you open the project in VSCode with the PlatformIO extension installed (on any OS), all you have to do is open the PlatformIO Tasks menu and select Set Fuses and it will burn the fuse bits as configured in platformio.ini.

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

Otherwise, if you have avrdude installed (it comes with the Arduino IDE), you can use it just as you wrote.
The specific command I used to burn the fuse bits, back when I compiled and loaded everything using the terminal (before I found out how to do it with PIO), was this:
```
avrdude -C "C:\Program Files (x86)\Arduino\hardware\tools\avr\etc\avrdude.conf" -v -p atmega328p -c stk500v1 -P COM4 -b 19200 -U lfuse:w:0xe0:m -U hfuse:w:0xd9:m -U efuse:w:0xff:m
```

And to flash the firmware I would use:
```
avrdude -C "C:\Program Files (x86)\Arduino\hardware\tools\avr\etc\avrdude.conf" -v -p atmega328p -c stk500v1 -P COM4 -b 19200 -U "flash:w:%USERPROFILE%\Desktop\nesizer_fw.hex:i"
```

The stk500v1 is the programmer argument that corresponds to an Arduino Uno with an ATmega328p installed which has been programmed with the "ArduinoISP.ino" example sketch. (I mention this primarily to inform anyone else who reads this in future who wants to use an Arduino Uno as a programmer.) Of course you will have to set your own paths and COM port settings etc, corresponding to your OS.

For a little more information, see the closed Issue called AVR Programming Method #11

NilocEidlog, 2024-05-25:
Cool - makes sense! I was just doing it all via cmd line in bash :P

beau-seidon, 2024-05-25:
> Cool - makes sense! I was just doing it all via cmd line in bash :P

That's how it was originally intended to be done, but it's open source, build it however you want!

I still use Windows primarily. I love Linux but there are 2 applications I won't go without, which don't run properly on Linux. I was able to set fuse bits and load the firmware via Windows, but (probably because of operator error) I was only able to get the source to compile on Linux. Tried using git bash on Windows and mingw64, but the main problem is I still don't fully understand Make. Feel free to ridicule me.

I've been programming microcontrollers using PlatformIO for a while now, so I fiddled around a bit and got the NESizer2 firmware to compile and upload, on Windows and Linux, entirely within VSCode. I was told it works on MacOS also.

All you have to do is git-clone or manually download the repo, open it in VSCode (with PIO extension enabled), set the fuse bits (only required the first time), and click upload. It will auto install any dependencies, compile everything, and load it to the chip using the programmer settings in the platformio.ini file, which may have to be modified to match your ISP programmer device.

That's the way I like doing it.

beau-seidon, 2024-05-25:
If I remember correctly, @Jaffe- compiles (or has compiled at least once) via CLI using WSL in Windows. I haven't tried that yet.

Closed 2024-05-25.

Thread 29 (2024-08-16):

MIDI causing NESizer to crash.

jeff464, 2024-08-16:
Exactly as the title says. When I hit play on my MPC Live, the NESizer blanks out. I can play notes all day long just fine, but as soon as I hit play, it's toast. Also worth noting, I can duplicate this behavior if I have my Roland MC-505 connected via MIDI and press any of the track mute buttons, but play and notes seem to send to the NESizer just fine. Also, Ableton notes/play work fine as well. I can duplicate the behavior on both of my NESizer units.

beau-seidon, 2024-08-21:
if you have a usb midi interface, hook up the midi output of your mpc live to the interface input and use midi-ox to capture the message it sends when you press play. that will help with diagnosis.

try to capture any other controllers' midi messages that you have seen crash nesizer as well.

jeff464, 2024-09-15:
So it would seem as though the MPC no longer crashes the NESizer, but I think this *might* be due to a recent firmware update from Akai. However, I noticed that powering the Roland MC-505 caused the NESizer to crash if MIDI was connected. Here's what MIDIOX returned:

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

jeff464, 2024-09-15:
Here is output from the Roland MC-505 when I press a track button - it sends a sysex message, and this is ultimately what causes the NESizer to crash.

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

beau-seidon, 2024-09-15:
I'll see if I can figure out how it handles sysex and make it ignore sysex messages not specifically meant for NESizer.

beau-seidon, 2024-09-15:
I have added a statement which checks for the proper SysexID and DeviceID in the sysex message handler, and it seems to functioning correctly.

However, I had to also edit the program which converts samples and sequences to .syx files, and I'm still testing that to make sure it's working properly and samples get uploaded to the right slots and play back etc.

Will upload to a new branch on my fork for public testing when I get it working.

beau-seidon, 2024-09-15:
https://github.com/beau-seidon/NESizer2/tree/sysex-filter

Working fine now on my end.
I included the recompiled gensysex.exe file for converting samples to sysex with the ID's in the message header.
Let me know if you have issues with sample loading, playback, or more hangs / midi-handling misbehavior.

One thing I noticed, is that on infrequent occasion, it seems to ignore a correctly addressed sysex message from MIDIOX, and I have to send it again. Doesn't happen often, and when I resend, it usually works the second time.

jeff464, 2024-09-15:
Great - just uploaded, and the crashes seem to be fixed! That said, is there a trick to getting the MIDI CCs to work? It seems I'm not able to adjust anything via MIDI.

jeff464, 2024-09-15:
Wait, sorry - just realizing these are two different forks. So I assume it's now a choice between crashes or MIDI CC?

beau-seidon, 2024-09-15:
Ruh roh. Give me a little bit, I'm busy at the moment, but I will make the sysex changes to a clone of circuitcreature's fork and upload so you can play with it. It should be a pretty straightforward copy/paste process now.

As far as the MIDI CC features, I haven't tested their fork very much on my own synth yet so I don't know what issues to expect. Let me know how it goes!

beau-seidon, 2024-09-16:
> Wait, sorry - just realizing these are two different forks. So I assume it's now a choice between crashes or MIDI CC?

https://github.com/beau-seidon/NESizer2/tree/circuitcreature-fix-sysex

beau-seidon, 2024-09-21:
Adding the ignore function based on SysEx messages' "ID bytes" fixed the crashes from irrelevant sysex messages, but I found that sometimes the synth is missing bytes (race condition?) which can result in switching to the IGNORE state erroneously.

I'm working on a branch that has already fixed that issue but I still have a couple more things to test. Might have it committed this evening.

I also added patch selection via SysEx which works just like ProgramChange.

Closed 2024-10-04.

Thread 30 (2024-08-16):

Loud MIDI zipper noises/note clicking when sending MIDI to NESizer

jeff464, 2024-08-16:
I am getting pretty bad zippering/clicking whenever either of my NESizer units receive any sort of MIDI data. If the channels are not engaged, it's loud enough to register on my MOTU audio interface/oscilloscope. I don't seem to get this on any of my other synths or Famimimidi. I tested different power supplies, outlets, and cables, none of which had any change.

Any idea what might be happening here? It's making it difficult to make softer/quieter sounds on the NESizer.

Jaffe-, 2024-10-02:
@jeff464: Unfortunately there is a lot of noise bleed on the NESizer, it is just the way it is - poorly designed in this regard :p. Remember it has strictly been a hobby project by a (at the time) electronics engineer student and never designed with the intention of selling as a product.

Someone more knowledgeable in electronics or with audio knowledge might try and come up with some fixes for existing boards, but I think the PCB has to be redesigned with proper separation between audio and digital signal and power domains to get rid of this. Maybe someone comes up with something clever (or even better, a NESizer v3!)

beau-seidon, 2024-10-03:
That sound is called "DIY Character" :)

If we make a NESizer3, let's use an ATmega1284 because it has extra UARTs!

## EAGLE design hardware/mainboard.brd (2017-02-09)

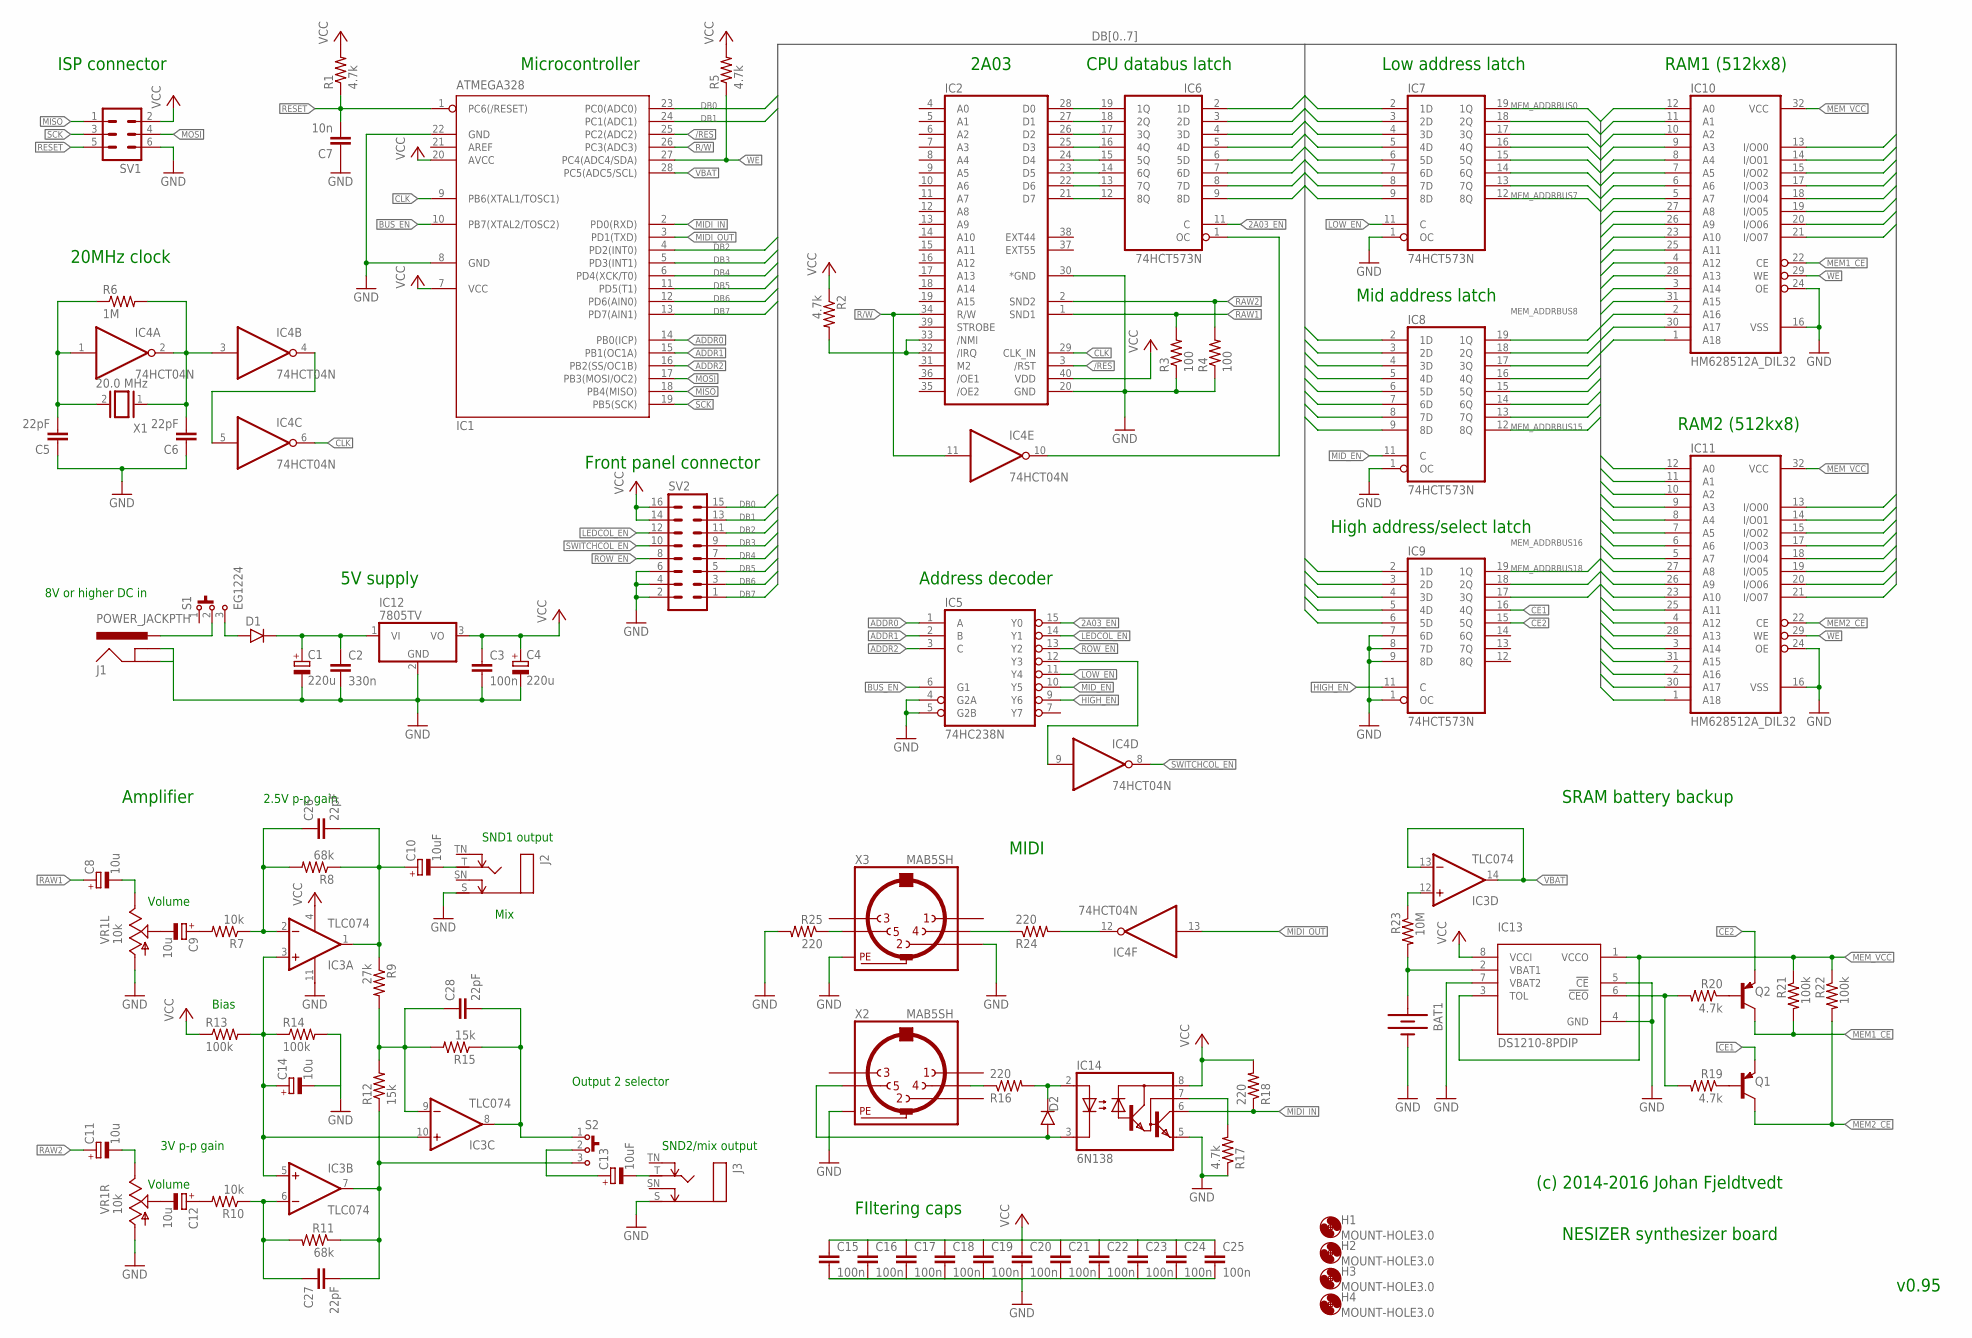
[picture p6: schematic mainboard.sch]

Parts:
BAT1: BATTERY20PTH; BATTCOM_20MM_PTH
C1, C4: 220u; E5-10,5
C2: 330n; C025-025X050
C3, C15, C16, C17, C18, C19, C20, C21, C22, C23, C24, C25: 100n; C025-025X050
C5, C6, C26, C27, C28: 22pF; C2.5-2
C7: 10n; C2.5-2
C8, C9, C11, C12, C14: 10u; E2-5
C10, C13: 10uF; E2-5
D1: 1N400X.3; DO41-3
D2: 1N914.3; DO35-3
H1, H2, H3, H4: MOUNT-HOLE3.0; 3,0
IC1: ATMEGA328; DIL28-3
IC2: 2A03; DIL40
IC3: TLC074; DIL14
IC4: 74HCT04N; DIL14
IC5: 74HC238N; DIL16
IC6, IC7, IC8, IC9: 74HCT573N; DIL20
IC10, IC11: HM628512A_DIL32; DIL32
IC12: 7805TV; TO220V
IC13: DS1210-8PDIP; DIL08
IC14: 6N138; DIL08
J1: POWER_JACKPTH; POWER_JACK_PTH
J2, J3: MONOSW; NMJ4HCD2
Q1, Q2: BC557; TO92
R1, R2, R5, R17, R19, R20: 4.7k; 0207/7
R3, R4: 100; 0207/7
R6: 1M; 0207/7
R7, R10: 10k; 0207/7
R8, R11: 68k; 0207/7
R9: 27k; 0207/7
R12, R15: 15k; 0207/7
R13, R14, R21, R22: 100k; 0207/7
R16, R18, R24, R25: 220; 0207/7
R23: 10M; 0207/7
S1, S2: EG1224
SV1: MA03-2
SV2: MA08-2
VR1: 10k; ALPS_RK0971221Z0X
X1: 20.0 MHz; QS
X2, X3: MAB5SH

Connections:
2A03_EN: IC5.15 (Y0), IC6.11 (C)
/RES: IC1.25 (PC2(ADC2)), IC2.3 (/RST)
ADDR0: IC1.14 (PB0(ICP)), IC5.1 (A)
ADDR1: IC1.15 (PB1(OC1A)), IC5.2 (B)
ADDR2: IC1.16 (PB2(SS/OC1B)), IC5.3 (C)
BUS_EN: IC1.10 (PB7(XTAL2/TOSC2)), IC5.6 (G1)
C6: C8.-, VR1.I1 (3)
CE1: IC9.16 (4Q), Q1.1 (E)
CE2: IC9.15 (5Q), Q2.1 (E)
CLK: IC1.9 (PB6(XTAL1/TOSC1)), IC2.29 (CLK_IN), IC4.6 (O)
DB0: IC1.23 (PC0(ADC0)), IC6.2 (1D), IC7.2 (1D), IC8.2 (1D), IC9.2 (1D), IC10.13 (I/O00), IC11.13 (I/O00), SV2.15
DB1: IC1.24 (PC1(ADC1)), IC6.3 (2D), IC7.3 (2D), IC8.3 (2D), IC9.3 (2D), IC10.14 (I/O01), IC11.14 (I/O01), SV2.13
DB2: IC1.4 (PD2(INT0)), IC6.4 (3D), IC7.4 (3D), IC8.4 (3D), IC9.4 (3D), IC10.15 (I/O02), IC11.15 (I/O02), SV2.11
DB3: IC1.5 (PD3(INT1)), IC6.5 (4D), IC7.5 (4D), IC8.5 (4D), IC9.5 (4D), IC10.17 (I/O03), IC11.17 (I/O03), SV2.9
DB4: IC1.6 (PD4(XCK/T0)), IC6.6 (5D), IC7.6 (5D), IC8.6 (5D), IC9.6 (5D), IC10.18 (I/O04), IC11.18 (I/O04), SV2.7
DB5: IC1.11 (PD5(T1)), IC6.7 (6D), IC7.7 (6D), IC8.7 (6D), IC10.19 (I/O05), IC11.19 (I/O05), SV2.5
DB6: IC1.12 (PD6(AIN0)), IC6.8 (7D), IC7.8 (7D), IC8.8 (7D), IC10.20 (I/O06), IC11.20 (I/O06), SV2.3
DB7: IC1.13 (PD7(AIN1)), IC6.9 (8D), IC7.9 (8D), IC8.9 (8D), IC10.21 (I/O07), IC11.21 (I/O07), SV2.1
GND: BAT1.2 (-), C1.-, C2.2, C3.2, C4.-, C5.1, C6.1, C7.1, C14.-, C15.2, C16.2, C17.2, C18.2, C19.2, C20.2, C21.2, C22.2, C23.2, C24.2, C25.2, IC1.8 (GND), IC1.22 (GND), IC2.20 (GND), IC2.30 (*GND), IC3.11 (V-), IC4.7 (GND), IC5.4 (G2A), IC5.5 (G2B), IC5.8 (GND), IC6.10 (GND), IC7.1 (OC), IC7.10 (GND), IC8.1 (OC), IC8.10 (GND), IC9.1 (OC), IC9.7 (6D), IC9.8 (7D), IC9.9 (8D), IC9.10 (GND), IC10.16 (VSS), IC10.24 (OE), IC11.16 (VSS), IC11.24 (OE), IC12.2 (GND), IC13.4 (GND), IC13.5 (!CE), IC13.7 (VBAT2), IC14.5 (GND), J1.GND, J1.GNDBREAK, J2.S, J3.S, R3.1, R4.1, R14.2, R17.1, R25.2, SV1.6, SV2.2, SV2.4, SV2.6, VR1.G1 (1), VR1.G2 (1), X2.PE, X2.PE@ (PE), X3.2, X3.PE, X3.PE@ (PE)
HIGH_EN: IC5.9 (Y6), IC9.11 (C)
LEDCOL_EN: IC5.14 (Y1), SV2.12
LOW_EN: IC5.11 (Y4), IC7.11 (C)
MEM1_CE: IC10.22 (CE), Q2.3 (C), R21.2
MEM2_CE: IC11.22 (CE), Q1.3 (C), R22.2
MEM_ADDRBUS0: IC7.19 (1Q), IC10.12 (A0), IC11.12 (A0)
MEM_ADDRBUS1: IC7.18 (2Q), IC10.11 (A1), IC11.11 (A1)
MEM_ADDRBUS2: IC7.17 (3Q), IC10.10 (A2), IC11.10 (A2)
MEM_ADDRBUS3: IC7.16 (4Q), IC10.9 (A3), IC11.9 (A3)
MEM_ADDRBUS4: IC7.15 (5Q), IC10.8 (A4), IC11.8 (A4)
MEM_ADDRBUS5: IC7.14 (6Q), IC10.7 (A5), IC11.7 (A5)
MEM_ADDRBUS6: IC7.13 (7Q), IC10.6 (A6), IC11.6 (A6)
MEM_ADDRBUS7: IC7.12 (8Q), IC10.5 (A7), IC11.5 (A7)
MEM_ADDRBUS8: IC8.19 (1Q), IC10.27 (A8), IC11.27 (A8)
MEM_ADDRBUS9: IC8.18 (2Q), IC10.26 (A9), IC11.26 (A9)
MEM_ADDRBUS10: IC8.17 (3Q), IC10.23 (A10), IC11.23 (A10)
MEM_ADDRBUS11: IC8.16 (4Q), IC10.25 (A11), IC11.25 (A11)
MEM_ADDRBUS12: IC8.15 (5Q), IC10.4 (A12), IC11.4 (A12)
MEM_ADDRBUS13: IC8.14 (6Q), IC10.28 (A13), IC11.28 (A13)
MEM_ADDRBUS14: IC8.13 (7Q), IC10.3 (A14), IC11.3 (A14)
MEM_ADDRBUS15: IC8.12 (8Q), IC10.31 (A15), IC11.31 (A15)
MEM_ADDRBUS16: IC9.19 (1Q), IC10.2 (A16), IC11.2 (A16)
MEM_ADDRBUS17: IC9.18 (2Q), IC10.30 (A17), IC11.30 (A17)
MEM_ADDRBUS18: IC9.17 (3Q), IC10.1 (A18), IC11.1 (A18)
MEM_VCC: IC10.32 (VCC), IC11.32 (VCC), IC13.1 (VCCO), IC13.3 (TOL), R21.1, R22.1
MIDI_IN: IC1.2 (PD0(RXD)), IC14.6 (VO), R18.1
MIDI_OUT: IC1.3 (PD1(TXD)), IC4.13 (I)
MIDI_PIN_4: R16.1, X2.4
MIDI_PIN_5: D2.A, IC14.3 (C), X2.5
MID_EN: IC5.10 (Y5), IC8.11 (C)
MISO: IC1.18 (PB4(MISO)), SV1.1
MOSI: IC1.17 (PB3(MOSI/OC2)), SV1.4
unnamed: C5.2, IC4.1 (I), R6.1, X1.2
unnamed: C6.2, IC4.2 (O), IC4.3 (I), R6.2, X1.1
unnamed: IC2.21 (D7), IC6.12 (8Q)
unnamed: IC2.22 (D6), IC6.13 (7Q)
unnamed: IC2.23 (D5), IC6.14 (6Q)
unnamed: IC2.24 (D4), IC6.15 (5Q)
unnamed: IC2.25 (D3), IC6.16 (4Q)
unnamed: IC2.26 (D2), IC6.17 (3Q)
unnamed: IC2.27 (D1), IC6.18 (2Q)
unnamed: IC2.28 (D0), IC6.19 (1Q)
unnamed: IC4.4 (O), IC4.5 (I)
unnamed: IC4.9 (I), IC5.12 (Y3)
unnamed: C13.+, S2.2
unnamed: C28.1, IC3.9 (-IN), R9.2, R12.2, R15.2
unnamed: C9.+, R7.2
unnamed: IC2.32 (/IRQ), IC2.33 (/NMI), R2.2
unnamed: C11.-, VR1.I2 (3)
unnamed: C26.1, IC3.2 (-IN), R7.1, R8.2
unnamed: IC3.12 (+IN), R23.1
unnamed: IC14.7 (VB), R17.2
unnamed: C12.+, R10.2
unnamed: C10.-, J2.T
unnamed: C13.-, J3.T
unnamed: C27.1, IC3.6 (-IN), R10.1, R11.2
unnamed: C10.+, C26.2, IC3.1 (OUT), R8.1, R9.1
unnamed: C28.2, IC3.8 (OUT), R15.1, S2.1
unnamed: D1.A, S1.3
unnamed: C14.+, IC3.3 (+IN), IC3.5 (+IN), IC3.10 (+IN), R13.2, R14.1
unnamed: IC4.10 (O), IC6.1 (OC)
unnamed: C9.-, VR1.O1 (2)
unnamed: J1.PWR, S1.2
unnamed: C12.-, VR1.O2 (2)
unnamed: IC13.6 (!CEO), R19.2, R20.2
unnamed: D2.C, IC14.2 (A), R16.2
unnamed: C1.+, C2.1, D1.C, IC12.1 (VI)
unnamed: C27.2, IC3.7 (OUT), R11.1, R12.1, S2.3
unnamed: Q1.2 (B), R19.1
unnamed: Q2.2 (B), R20.1
unnamed: BAT1.1 (+), IC13.2 (VBAT1), R23.2
unnamed: IC4.12 (O), R24.2
unnamed: R24.1, X3.4
unnamed: R25.1, X3.5
R/W: IC1.26 (PC3(ADC3)), IC2.34 (R/W), IC4.11 (I)
RAW1: C8.+, IC2.1 (SND1), R3.2
RAW2: C11.+, IC2.2 (SND2), R4.2
RESET: C7.2, IC1.1 (PC6(/RESET)), R1.1, SV1.5
ROW_EN: IC5.13 (Y2), SV2.8
S1: VR1.S1
S2: VR1.S2
SCK: IC1.19 (PB5(SCK)), SV1.3
SWITCHCOL_EN: IC4.8 (O), SV2.10
VBAT: IC1.28 (PC5(ADC5/SCL)), IC3.13 (-IN), IC3.14 (OUT)
VCC: C3.1, C4.+, C15.1, C16.1, C17.1, C18.1, C19.1, C20.1, C21.1, C22.1, C23.1, C24.1, C25.1, IC1.7 (VCC), IC1.20 (AVCC), IC2.40 (VDD), IC3.4 (V+), IC4.14 (VCC), IC5.16 (VCC), IC6.20 (VCC), IC7.20 (VCC), IC8.20 (VCC), IC9.20 (VCC), IC12.3 (VO), IC13.8 (VCCI), IC14.8 (VCC), R1.2, R2.1, R5.2, R13.1, R18.2, SV1.2, SV2.14, SV2.16
WE: IC1.27 (PC4(ADC4/SDA)), IC10.29 (WE), IC11.29 (WE), R5.1

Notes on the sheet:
Microcontroller
2A03
ISP connector
20MHz clock
Amplifier
Address decoder
CPU databus latch
RAM1 (512kx8)
RAM2 (512kx8)
Low address latch
Mid address latch
High address/select latch
Front panel connector
SRAM battery backup
MIDI
5V supply
FIltering caps
SND2/mix output
SND1 output
8V or higher DC in
Volume
Output 2 selector
2.5V p-p gain
3V p-p gain
Mix
v0.95
(c) 2014-2016 Johan Fjeldtvedt
NESIZER synthesizer board
Bias

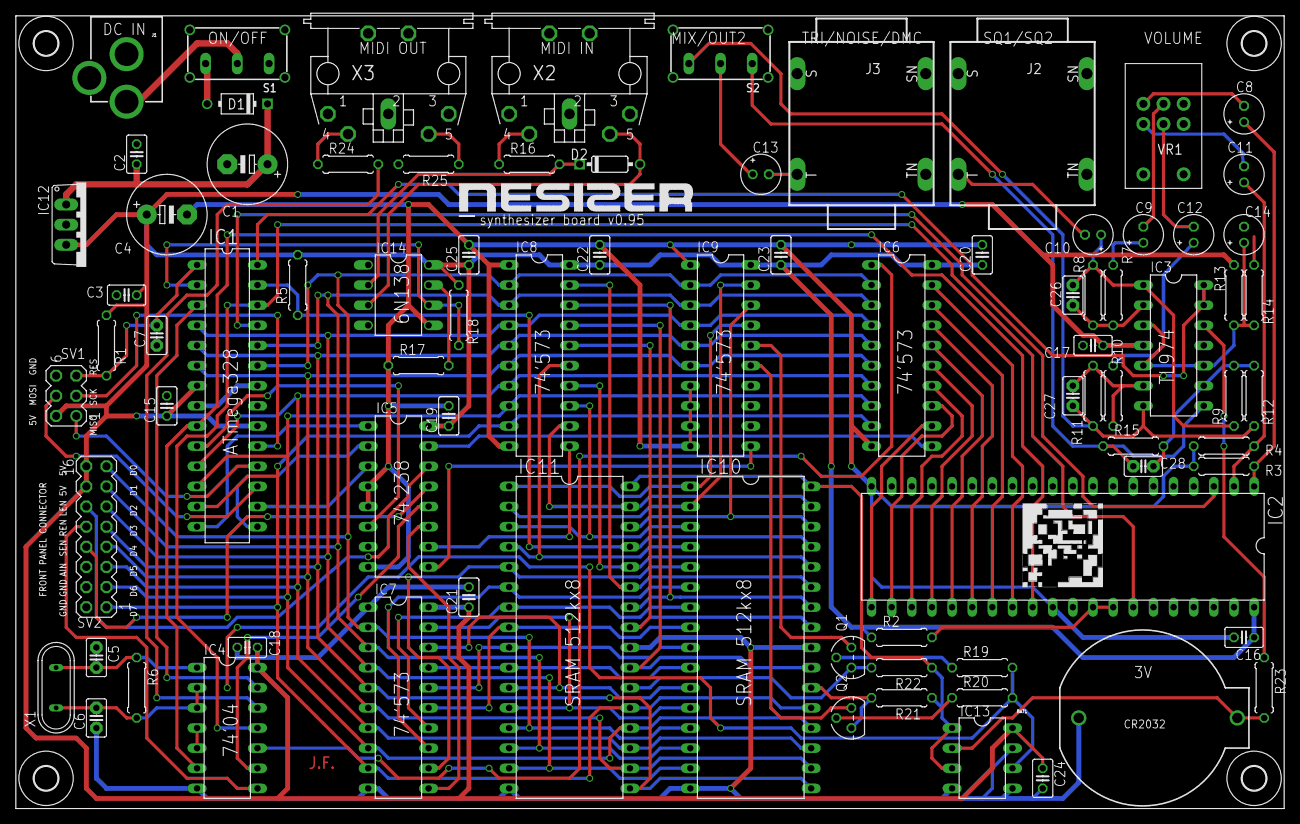
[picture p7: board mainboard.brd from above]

Board: 2 copper layers, 160.0 x 100.0 mm, 89 parts (0 on the bottom side), 103 nets.

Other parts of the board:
U$1: NESIZER_LOGO
U$2: MARIO

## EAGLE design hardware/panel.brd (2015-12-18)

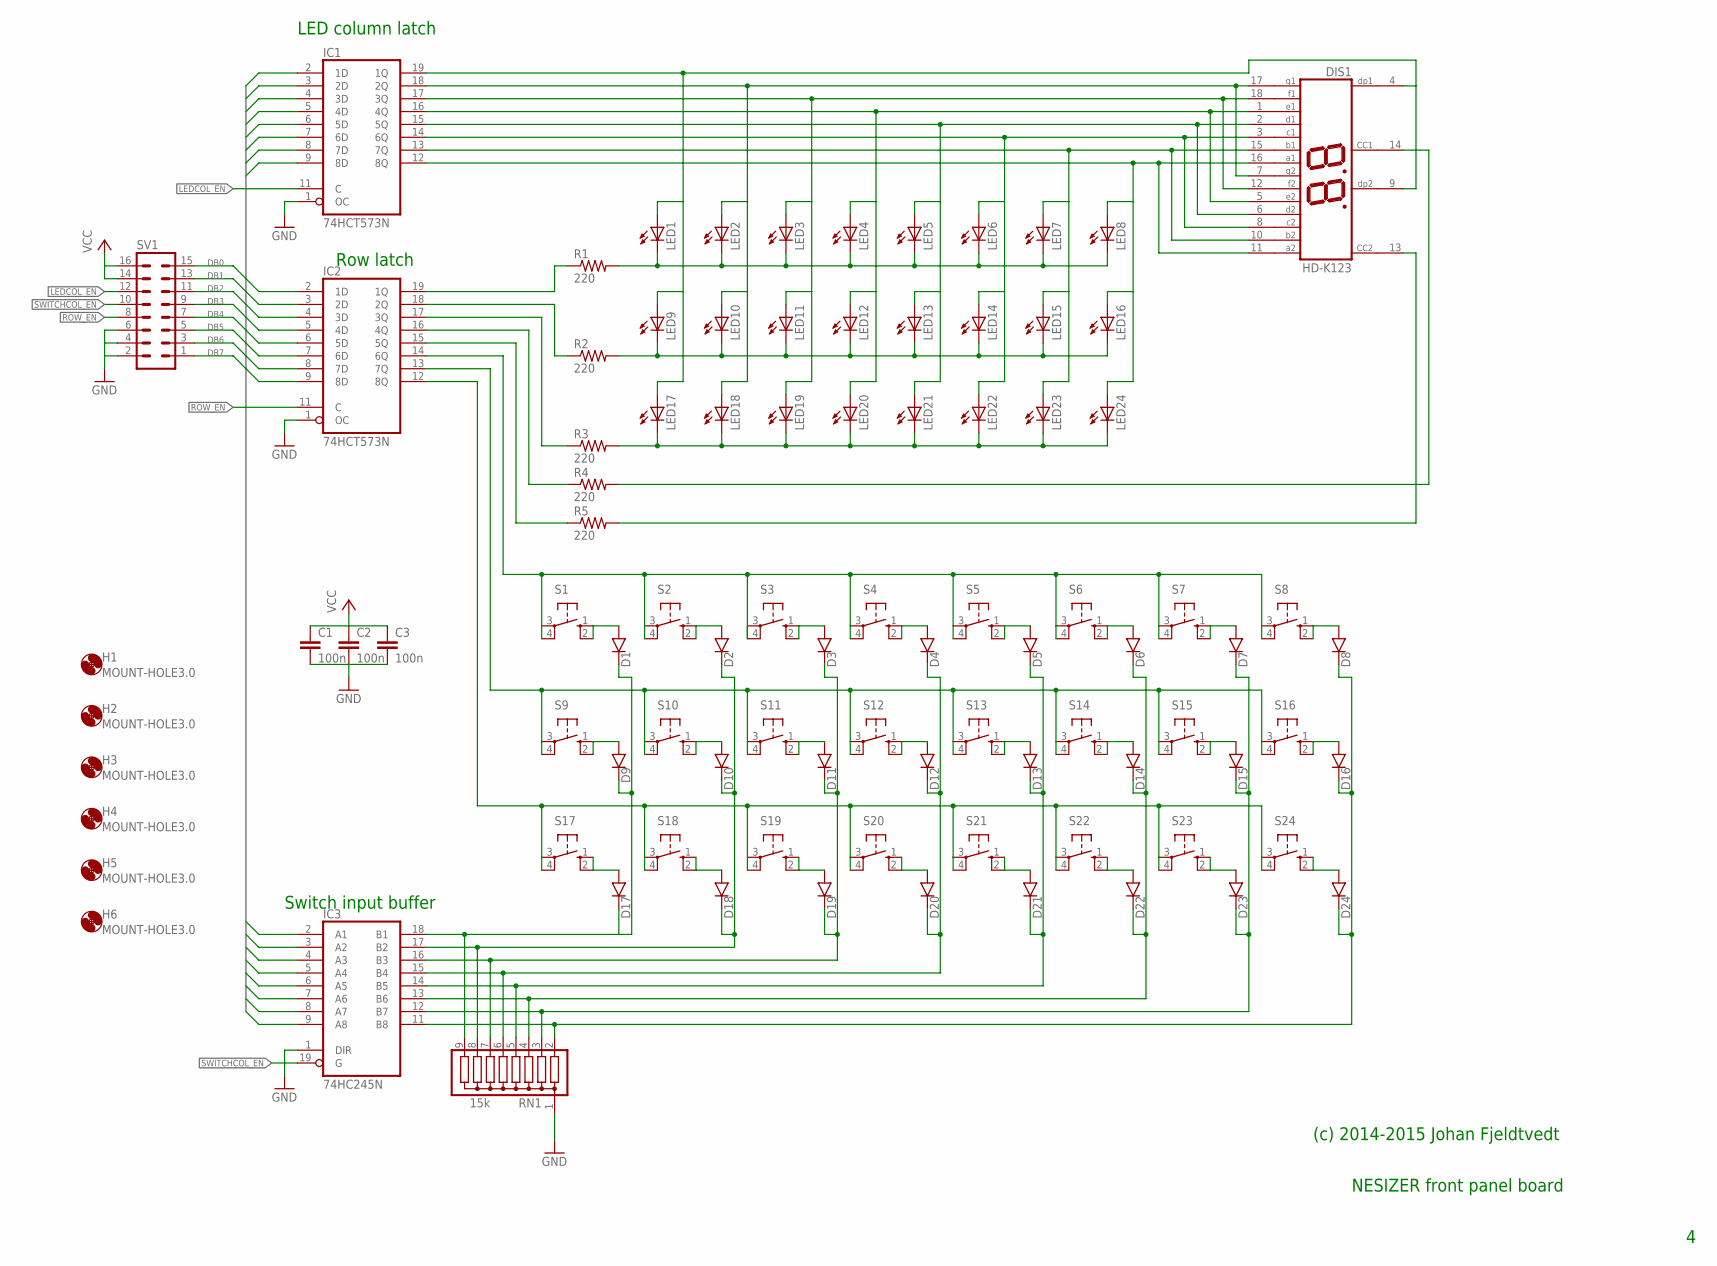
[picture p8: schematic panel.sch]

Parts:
C1, C2, C3: 100n; C025-025X050
D1, D2, D3, D4, D5, D6, D7, D8, D9, D10, D11, D12, D13, D14, D15, D16, D17, D18, D19, D20, D21, D22, D23, D24: 1N914.3; DO35-3
DIS1: HD-K123; HDSP-R
H1, H2, H3, H4, H5, H6: MOUNT-HOLE3.0; 3,0
IC1, IC2: 74HCT573N; DIL20
IC3: 74HC245N; DIL20
LED1, LED2, LED3, LED4, LED5, LED6, LED7, LED8, LED9, LED10, LED11, LED12, LED13, LED14, LED15, LED16, LED17, LED18, LED19, LED20, LED21, LED22, LED23, LED24: LED3MM
R1, R2, R3, R4, R5: 220; 0207/7
RN1: 15k; SIL9
S1, S2, S3, S4, S5, S6, S7, S8, S9, S10, S11, S12, S13, S14, S15, S16: 40-XX; B3F-40XX
S17, S18, S19, S20, S21, S22, S23, S24: 10-XX; B3F-10XX
SV1: MA08-2

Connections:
DB0: IC1.2 (1D), IC2.2 (1D), IC3.2 (A1), SV1.15
DB1: IC1.3 (2D), IC2.3 (2D), IC3.3 (A2), SV1.13
DB2: IC1.4 (3D), IC2.4 (3D), IC3.4 (A3), SV1.11
DB3: IC1.5 (4D), IC2.5 (4D), IC3.5 (A4), SV1.9
DB4: IC1.6 (5D), IC2.6 (5D), IC3.6 (A5), SV1.7
DB5: IC1.7 (6D), IC2.7 (6D), IC3.7 (A6), SV1.5
DB6: IC1.8 (7D), IC2.8 (7D), IC3.8 (A7), SV1.3
DB7: IC1.9 (8D), IC2.9 (8D), IC3.9 (A8), SV1.1
GND: C1.2, C2.2, C3.2, IC1.1 (OC), IC1.10 (GND), IC2.1 (OC), IC2.10 (GND), IC3.1 (DIR), IC3.10 (GND), RN1.1, SV1.2, SV1.4, SV1.6
LEDCOL_EN: IC1.11 (C), SV1.12
unnamed: LED1.K (C), LED2.K (C), LED3.K (C), LED4.K (C), LED5.K (C), LED6.K (C), LED7.K (C), LED8.K (C), R1.2
unnamed: LED17.K (C), LED18.K (C), LED19.K (C), LED20.K (C), LED21.K (C), LED22.K (C), LED23.K (C), LED24.K (C), R3.2
unnamed: DIS1.4 (DP1), DIS1.9 (DP2), IC1.19 (1Q), LED1.A, LED9.A, LED17.A
unnamed: DIS1.7 (G2), DIS1.17 (G1), IC1.18 (2Q), LED2.A, LED10.A, LED18.A
unnamed: DIS1.12 (F2), DIS1.18 (F1), IC1.17 (3Q), LED3.A, LED11.A, LED19.A
unnamed: DIS1.1 (E1), DIS1.5 (E2), IC1.16 (4Q), LED4.A, LED12.A, LED20.A
unnamed: DIS1.2 (D1), DIS1.6 (D2), IC1.15 (5Q), LED5.A, LED13.A, LED21.A
unnamed: DIS1.3 (C1), DIS1.8 (C2), IC1.14 (6Q), LED6.A, LED14.A, LED22.A
unnamed: DIS1.10 (B2), DIS1.15 (B1), IC1.13 (7Q), LED7.A, LED15.A, LED23.A
unnamed: DIS1.11 (A2), DIS1.16 (A1), IC1.12 (8Q), LED8.A, LED16.A, LED24.A
unnamed: LED9.K (C), LED10.K (C), LED11.K (C), LED12.K (C), LED13.K (C), LED14.K (C), LED15.K (C), LED16.K (C), R2.2
unnamed: IC2.19 (1Q), R1.1
unnamed: DIS1.13 (CC2), R5.2
unnamed: DIS1.14 (CC1), R4.2
unnamed: IC2.17 (3Q), R3.1
unnamed: IC2.15 (5Q), R5.1
unnamed: IC2.16 (4Q), R4.1
unnamed: IC2.13 (7Q), S9.3, S9.4 (P1), S10.3, S10.4 (P1), S11.3, S11.4 (P1), S12.3, S12.4 (P1), S13.3, S13.4 (P1), S14.3, S14.4 (P1), S15.3, S15.4 (P1), S16.3, S16.4 (P1)
unnamed: IC2.18 (2Q), R2.1
unnamed: IC2.14 (6Q), S1.3, S1.4 (P1), S2.3, S2.4 (P1), S3.3, S3.4 (P1), S4.3, S4.4 (P1), S5.3, S5.4 (P1), S6.3, S6.4 (P1), S7.3, S7.4 (P1), S8.3, S8.4 (P1)
unnamed: D2.C, D10.C, D18.C, IC3.17 (B2), RN1.8
unnamed: D1.C, D9.C, D17.C, IC3.18 (B1), RN1.9
unnamed: D9.A, S9.1 (S), S9.2 (S1)
unnamed: D2.A, S2.1 (S), S2.2 (S1)
unnamed: IC2.12 (8Q), S17.3, S17.4 (P1), S18.3, S18.4 (P1), S19.3, S19.4 (P1), S20.3, S20.4 (P1), S21.3, S21.4 (P1), S22.3, S22.4 (P1), S23.3, S23.4 (P1), S24.3, S24.4 (P1)
unnamed: D17.A, S17.1 (S), S17.2 (S1)
unnamed: D18.A, S18.1 (S), S18.2 (S1)
unnamed: D19.A, S19.1 (S), S19.2 (S1)
unnamed: D20.A, S20.1 (S), S20.2 (S1)
unnamed: D21.A, S21.1 (S), S21.2 (S1)
unnamed: D11.A, S11.1 (S), S11.2 (S1)
unnamed: D10.A, S10.1 (S), S10.2 (S1)
unnamed: D4.A, S4.1 (S), S4.2 (S1)
unnamed: D12.A, S12.1 (S), S12.2 (S1)
unnamed: D3.A, S3.1 (S), S3.2 (S1)
unnamed: D3.C, D11.C, D19.C, IC3.16 (B3), RN1.7
unnamed: D5.A, S5.1 (S), S5.2 (S1)
unnamed: D13.A, S13.1 (S), S13.2 (S1)
unnamed: D6.A, S6.1 (S), S6.2 (S1)
unnamed: D14.A, S14.1 (S), S14.2 (S1)
unnamed: D22.A, S22.1 (S), S22.2 (S1)
unnamed: D7.A, S7.1 (S), S7.2 (S1)
unnamed: D15.A, S15.1 (S), S15.2 (S1)
unnamed: D23.A, S23.1 (S), S23.2 (S1)
unnamed: D8.A, S8.1 (S), S8.2 (S1)
unnamed: D16.A, S16.1 (S), S16.2 (S1)
unnamed: D24.A, S24.1 (S), S24.2 (S1)
unnamed: D4.C, D12.C, D20.C, IC3.15 (B4), RN1.6
unnamed: D5.C, D13.C, D21.C, IC3.14 (B5), RN1.5
unnamed: D6.C, D14.C, D22.C, IC3.13 (B6), RN1.4
unnamed: D7.C, D15.C, D23.C, IC3.12 (B7), RN1.3
unnamed: D8.C, D16.C, D24.C, IC3.11 (B8), RN1.2
unnamed: D1.A, S1.1 (S), S1.2 (S1)
ROW_EN: IC2.11 (C), SV1.8
SWITCHCOL_EN: IC3.19 (G), SV1.10
VCC: C1.1, C2.1, C3.1, IC1.20 (VCC), IC2.20 (VCC), IC3.20 (VCC), SV1.14, SV1.16

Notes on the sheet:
LED column latch
Row latch
Switch input buffer
NESIZER front panel board
(c) 2014-2015 Johan Fjeldtvedt

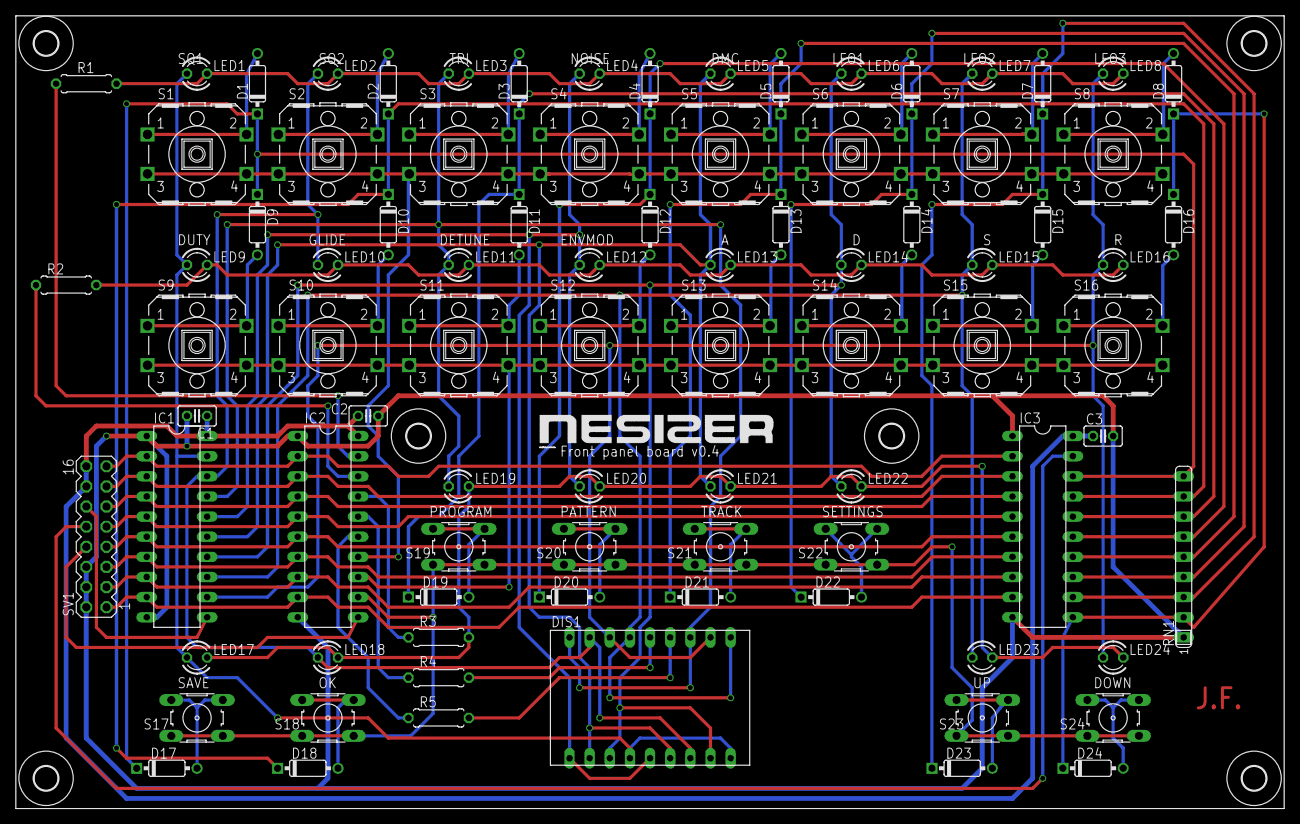
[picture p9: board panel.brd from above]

Board: 2 copper layers, 160.0 x 100.0 mm, 93 parts (0 on the bottom side), 66 nets.

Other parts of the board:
U$1: NESIZER_LOGO

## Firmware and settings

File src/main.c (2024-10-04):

/*
  Copyright 2014-2016 Johan Fjeldtvedt

  This file is part of NESIZER.

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


  Main entry point

  Entry point for the program. Initializes the system and starts the
  task/task.handler.
*/


#include "task/task.h"
#include "apu/apu.h"
#include "io/2a03.h"
#include "io/memory.h"
#include "io/bus.h"
#include "patch/patch.h"
#include "io/midi.h"
#include "io/battery.h"
#include "modulation/periods.h"
#include "assigner/assigner.h"
#include "sequencer/sequencer.h"
#include "ui/ui_sequencer.h"
#include "ui/ui_programmer.h"
#include "ui/ui.h"
#include "settings/settings.h"
#include "patch/patch.h"
#include "midi/midi.h"
#include "midi/midi_cc.h"

#include <util/delay.h>

#define MAGIC 0xdeadbeef
#define MAGIC_ADDR 0

static bool ram_integrity_check(void)
{
    for (uint8_t i = 0; i < 8; i++)
        if (memory_read_dword(MAGIC_ADDR+4*i) != MAGIC)
        // if (memory_read_dword(MAGIC_ADDR+4*i) != reverse_dword(MAGIC))  // load bytes to memory in correct order (will erase SRAM)
            return false;
    return true;
}

static void ram_initialize(void)
{
    for (uint8_t i = 0; i < 8; i++)
        memory_write_dword(MAGIC_ADDR+4*i, MAGIC);
        // memory_write_dword(MAGIC_ADDR+4*i, reverse_dword(MAGIC));  // load bytes to memory in correct order (will erase SRAM)
    settings_init();
    for (uint8_t i = 0; i < 100; i++)
        patch_initialize(i);
    sequencer_pattern_init();
}

void startup_check(void)
{
    /* This delay is necessary to get a stable and correct voltage measurement */
    bool battery_good = battery_read() > 25;
    bool ram_good = ram_integrity_check();
    ui_startup_errors =
        ((battery_good ? 0 : 1) << UI_STARTUP_ERROR_BATTERY_LOW)
        | ((ram_good ? 0 : 1) << UI_STARTUP_ERROR_CORRUPT_RAM);

    if (!ram_good) {
        ram_initialize();
    }
}

int main()
{
    // Set up low level:
    bus_setup();
    memory_setup();
    io_setup();
    midi_io_setup();
    apu_setup();
    battery_setup();

    startup_check();

    // Set up higher level:
    task_setup();
    assigner_setup();
    periods_setup();
    sequencer_setup();
    ui_sequencer_setup();
    ui_programmer_setup();

    // The task manager takes over from here
    task_manager();

    midi_init();
}

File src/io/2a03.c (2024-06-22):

/*
  Copyright 2014-2017 Johan Fjeldtvedt

  This file is part of NESIZER.

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


  Low level 2A03 I/O interface

  Contains functions for communicating with and controlling the
  2A03.
*/

#include "2a03.h"
#include <avr/io.h>
#include <stdbool.h>

#include <util/delay.h>

#include <util/atomic.h>
#include <avr/interrupt.h>
#include "io/bus.h"
#include "task/task.h"
#include "modulation/periods.h"

// The 6502 opcodes needed
#define LDA_imm 0xA9
#define STA_abs 0x8D
#define STA_zp 0x85
#define JMP_abs 0x4C

// Pins used to interface with 6502
#define RES 0b100             // PC2
#define RW 0b1000          // PC3

uint8_t io_reg_buffer[0x18];
uint8_t reg_mirror[0x18];

/* Assembly functions in 2a03_asm.s */

extern void register_set12(uint8_t, uint8_t);
extern void register_set15(uint8_t, uint8_t);
extern void register_set16(uint8_t, uint8_t);
extern void reset_pc12(void);
extern void reset_pc15(void);
extern void reset_pc16(void);
extern void disable_interrupts12(void);
extern void disable_interrupts15(void);
extern void disable_interrupts16(void);
extern uint8_t detect_2a03_type(void);

void (*register_set)(uint8_t, uint8_t);
void (*reset_pc)(void);
void (*disable_interrupts)(void);

uint8_t io_clockdiv;

/* Internal utility functions */

/* Write to register

   Writes a value to an APU register by feeding the 6502
   with instructions for loading the value into A, and then
   storing the value in $40<reg>.
*/
static inline void register_write(uint8_t reg, uint8_t value)
{
    // Put STA_zp on bus before deactivating CPU latch
    bus_write(STA_zp);

    // Open latch output
    bus_select(CPU_ADDRESS);

    // The code in the register set function has to be cycle exact, so it has to
    // be run with interrupts disabled:

    ATOMIC_BLOCK(ATOMIC_RESTORESTATE) {
        register_set(reg, value);
    }

    // Finally, latch the last bus value by deselecting the CPU
    bus_deselect();

    // Reflect change in mirror
    reg_mirror[reg] = value;
}


/* External functions */

void io_register_write(uint8_t reg, uint8_t value)
{
    register_write(reg, value);
}

void io_write_changed(uint8_t reg)
{
    if (io_reg_buffer[reg] != reg_mirror[reg]) {

        if (reg == 0x03 || reg == 0x07) {

            /* Trick for avoiding phase reset when changing high bits of timer period */

            uint8_t low_val = reg_mirror[reg - 1];
            if ((reg_mirror[reg] & 0x07) - (io_reg_buffer[reg] & 0x07) == 1) {
                register_write(reg - 1, 0);    // low value = 0
                register_write(reg - 2, 0x8F); // enable sweep, negate, shift = 7
                register_write(0x17, 0xC0); // clock sweep immediately
                register_write(reg - 2, 0x0F); // disable sweep
                register_write(reg - 1, low_val); // put back low value
                reg_mirror[reg - 1] = low_val;
                reg_mirror[reg] = io_reg_buffer[reg];
                return;
            }

            else if ((io_reg_buffer[reg] & 0x07) - (reg_mirror[reg] & 0x07) == 1) {
                register_write(reg - 1, 0xFF);
                register_write(reg - 2, 0x87); // enable sweep, negate, shift = 7
                register_write(0x17, 0xC0); // clock sweep immediately
                register_write(reg - 2, 0x0F); // disable sweep
                register_write(reg - 1, low_val); // put back low value
                reg_mirror[reg - 1] = low_val;
                reg_mirror[reg] = io_reg_buffer[reg];
                return;
            }
        }

        register_write(reg, io_reg_buffer[reg]);
    }
}

void io_reset_pc(void)
{
    bus_write(STA_zp);

    bus_select(CPU_ADDRESS);

    ATOMIC_BLOCK(ATOMIC_RESTORESTATE) {
        reset_pc();
    }

    bus_deselect();
}

static uint8_t rw_transition_count;

ISR(PCINT1_vect)
{
    if (rw_transition_count < 255)
        rw_transition_count++;
}

bool detect_2a03_presence(void)
{
    rw_transition_count = 0;

    /* Enable Pin Change Interrupt 1 and unmask PCINT11 (Port C pin 3, RW signal from 2A03) */
    PCMSK1 = (1 << PCINT11);
    PCICR = (1 << PCIE1);
    sei();

    /* Wait while interrupt handler will catch R/W toggles */
    _delay_us(10);

    /* Disable interrupt */
    cli();
    PCMSK1 = 0;
    PCICR = 0;

    return rw_transition_count > 10;
}

void register_set_noop(uint8_t a, uint8_t b)
{
    return;
}

void reset_pc_noop(void)
{
    return;
}

void disable_interrupts_noop(void)
{
    return;
}

/*
  Initializes the interface to communicate with 6502
*/
void io_setup(void)
{
    // Configure the /RES pin on PORT C as output and set /RES high, also set
    // bits 0, 1 as output
    PORTC |= RES | RW;
    DDRC |= RES;

    bus_select(CPU_ADDRESS);

    bus_write(STA_abs);

    bus_deselect();

    // Set /RES low
    PORTC &= ~RES;

    // Hold it low for some time, for 6502 to perform reset
    _delay_us(10);

    // Set /RES high again
    PORTC |= RES;

    // Wait a while until the 6502 has completed its reset cycle
    _delay_us(100);

    /* Start out assuming no 2A03 is installed */
    io_clockdiv = 0;

    /* Check if 2A03 is installed and is running */
    if (detect_2a03_presence()) {
        /* Run detect_2a03_type to determine what kind of 2A03 is installed,
           this is used later to set up functions to talk to the 2A03. */
        uint8_t tries = 3;
        while (tries-- > 0) {
            io_clockdiv = detect_2a03_type();
            if (io_clockdiv == 12 || io_clockdiv == 15 || io_clockdiv == 16)
                break;
        }
    }

    /* Point function pointers to correct function based on which 2A03 model is
       being used */

    switch (io_clockdiv) {
    case 12:
        register_set = &register_set12;
        reset_pc = &reset_pc12;
        disable_interrupts = &disable_interrupts12;
        break;

    case 15:
        register_set = &register_set15;
        reset_pc = &reset_pc15;
        disable_interrupts = &disable_interrupts15;
        break;

    case 16:
        register_set = &register_set16;
        reset_pc = &reset_pc16;
        disable_interrupts = &disable_interrupts16;
        break;

        /* Fallback case when 2A03 is not present or not able to detect */
    default:
        register_set = register_set_noop;
        reset_pc = reset_pc_noop;
        disable_interrupts = disable_interrupts_noop;
        break;
    }

    // Disable interrupts on the 6502
    disable_interrupts();

    // Reset PC to ensure that it doesn't read any of the APU registers
    io_reset_pc();
}

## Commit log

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2014-08-02 hardware change: added switch inputs and LED matrix
2014-08-02 new schematic: bus sharing, LED matrix and switch matrix added
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2014-08-09 fixes and new register write routine
    [bus.h]
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2014-08-19 new schematics in README.md
2014-08-19 user interface updates, bugfix in APU channel enabling/disabling
    [bus.h]
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2014-08-22 fixed clock circuit
2014-08-28 sample playback now done from SRAM instead of flash
2014-08-29 new schematic with SRAM battery circuit fix
2014-08-31 new schematic with MIDI input
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2015-01-13 grounded VBAT2 input on DS1210
2015-01-29 changed buttons on panel board
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2015-03-01 fixed sample transfer bug, added progress bar
    [main.c]
2015-03-06 moved assembly routines into own files
2015-03-07 moved assembly code to own file
2015-03-10 added coarse tuning and pitch bend range selection
2015-05-04 compressed button led states
2015-07-14 leds.c does not depend on avr functions; replace with stdint.h
2015-07-14 add bus_deselect when setting leds
2015-08-09 Add memory context switching for sequential r/w
    Several tasks might use memory simultainously. This is problematic
    for sequential read/write sessions where a read or write operation
    from another task changes the address latch values.
    This moves the latch mirrors out of the memory module and into the
    caller, and adds the necessary logic to check whether the context
    has changed, in which case the latch values will be updated with
    the new context, so that sequential operations can be continue.
2015-08-09 Generalize sample module, add memory context
    Currently sample uses a fixed struct object when reading and writing
    samples. This is makes it impossible to do DMC sample playback while at
    the same time using the sample functions to manipulate samples, i.e.
    writing to memory from incoming MIDI data.
    This fix restores sample.c/h to the old way of supplying struct sample
    pointers to the functions, and modifies apu.c, midi.c and assigner.c
    to accomodate the changes.
    A struct memory_context is added to the sample struct.
2015-08-15 add missing void arguments
    [2a03.c]
2015-08-23 Update hardware images, add sch files
    [mainboard.sch, panel.sch]
2015-10-28 main board: add decoupling to bias voltage divider
    [mainboard.sch]
2015-10-28 mainboard: new schematic snapshot
2015-11-01 replace mix buffer with inverting mixer to reduce crosstalk
    scm
    [mainboard.sch]
2015-11-02 Add small caps in feedback path for noise reduction and stability
    [mainboard.sch]
2015-11-13 New battery backup circuit
    The DS1210 is expensive and found to not really be needed here, so it has been
    replaced by a discrete transistor circuit.
    The op-amp used for the bias voltage buffer in the audio amplifier is now used
    for buffering the battery voltage instead. Its output is now connected to ADC5
    of the ATmega to allow for reading the battery voltage.
    [mainboard.sch]
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2015-11-19 Hardware: connect inverted R/W to output enable of 2a03 latch
    [mainboard.sch]
2015-12-18 added current bill of materials with mouser part numbers
    [BOM.xls]
2015-12-18 added sch and brd files for hardware
    [mainboard.brd, mainboard.sch, panel.brd]
2016-01-08 2a03.c: sweep fix implemented for both square channels
    [2a03.c]
2016-01-08 2a03.c: clean up the sweep fix code (still ugly though ..)
    [2a03.c]
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2016-01-10 remove SHIFT button as it makes the UI too complex to use
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2016-01-19 LED states now occupy 6 and not 24 bytes; reduce array sizes correpsondingly
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2016-01-19 fix LED defines
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2016-01-19 replace mode switch with table
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2016-01-31 update assigned_notes to hold which note a channel is currently playing
2016-02-01 remove envmod and detune initializations as they are not used after switching to signed int
2016-11-06 Main board v0.9: fix memory backup, new MIDI connector, BOM fixes
    The discrete memory backup circuit turned out to be too fragile. The old
    DS1210 based design is back, but it is now also used to provide the CPU
    RESET signal to further reduce the possibility of memory corruption. The
    battery voltage is still being connected (through a buffer) to the
    Atmega for being able to check the battery voltage.
    The MIDI connector that was used previously is not being stocked at
    Mouser any more, so it has been replaced by one that is.
    A couple of fixes have been done to the BOM, replacing out of stock
    components with drop-in replacements (a resistor and the 74'238).
    This should hopefully be the last r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
    [BOM.xls, mainboard.brd, mainboard.sch]
2016-11-07 HW 0.9 fix
    Added missing trace from battery to op-amp
    [mainboard.brd]
2016-11-07 BOM update
    Update the BOM to reflect changes in last mainboard revision.
    [BOM.xls]
2016-11-12 Clean up manual
    The manual was kept poorly out of sync with the actual user interface
    code, so a lot of the button positions were wrong.
    The sequencer description has also been removed until it is actually
    implemented.
2016-11-12 UI cleanup: SAVE and SET is the same button. Fix this.
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2016-11-13 add battery checking on bootup and in UI
    It is now possible to press S7 when in the settings mode to check the
    voltage on the battery (board revision >= 0.8)
    On startup, the voltage will be compared to 2.5V, and a warning ('bL'
    flashing on the display) will be given if it is.
2016-11-14 Implement note assignment modes
    Note assignment has been cleaned up and implemented properly, at least
    it seems to work well.
    The incoming MIDI notes can now be split into a lower and upper half.
    S10 actiaves/deactivates this feature. Channels can be assigned to a
    given half (channel button + S9 in page 2).
    Each of the lower and upper sections can be put into monophonic or
    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
2016-11-14 clean up channel enable logic
    The channel enable logic was too low level. The channels are now left
    'on' at all times, in the sense that their bits in SND_CHN ($4015) are
    always set. The enable settings in the patches are now handled by the
    assigner.
    [main.c]
2016-11-16 fix MIDI sample uploading
    The MIDI sample transfer code was not changed to work with the newest UI
    framework. A null function pointer caused the system to restart when a
    sample is transferred via MIDI.
2016-11-18 add external clock setting to SETTINGS mode
    Button S15 is now the "external clock" setting. 1 means external MIDI
    clock is used, 0 means internal is used.
2016-11-18 Bump period and priority of sequencer task
    The sequencer task should run a bit faster to allow better resolution
    for the tempo timer.
2017-01-29 HW: main board update
    Fixes a few faults in the latest main board revision:
    - Remove RESET connection from DS1210
    - Add 10M resistor between battery and op-amp
    Eliminates leakage through op-amp inputs which would
    cause DS1210 to switch mode to "on".
    [BOM.xls, mainboard.brd, mainboard.sch]
2017-01-29 change LED update scheme
    Now only one group of 3 LEDs are lit up simultaneously. This dims the
    LEDs a little bit, but also decreases the current draw from the latches.
2017-02-08 mainboard v0.95: fixes and MIDI out
    Fixed faults with battery measurement and RESET circuitry.
    Added MIDI OUT connector.
    [BOM.xls, mainboard.brd, mainboard.sch]
2017-02-09 add 220 resistor to MIDI out
    [BOM.xls, mainboard.brd, mainboard.sch]
2017-02-11 save settigns to SRAM
    This saves settings such as assigner mode, midi channels, etc. to SRAM
    so one doesn't have to set them every time
    [main.c]
2017-03-05 fix battery bug
2023-06-23 Handle NoteOn,Vel=0 same as NoteOff (#12)
    * handle NoteOn,Vel=0 same as NoteOff
    per MIDI Spec compliance, a NoteOn command with Velocity = 0 should be treated identically to NoteOff
    * Handle NoteOn,Vel=0 same as NoteOff
    Updated MIDI input code to comply with MIDI specification regarding stopping playback of notes.
    A NoteOn command with Velocity = 0 should be treated identically to NoteOff.
2023-08-27 improve initial startup behavior
    Add a simple check for whether the RAM contains valid data or not.
    If the expected magic data is not found, re-initialize the memory
    before continuing the boot process. Also log the error for display
    later.
    [main.c]
2023-09-09 main: place magic section at address 4
    Having the magic words start at address 0 seems to not work correctly,
    either because of a hardware issue or some rogue part of the firmware
    which writes to address 0.
    Move the words to start at address 4, this seems to not cause issues.
    [main.c]
2023-09-09 main: improve battery check
    Wait a bit before reading initial battery measurement.
    If this is not done the read value is close to 0 and will cause a
    battery level warning even if the battery is OK.
    Also remove offset adjustment in the battery_read function - this is not
    necessary with the current circuit design.
2023-09-09 settings: read battery once when battery level button is pressed
    Just read it once when pressed down, and continue to display the value
    as long as the button is being pressed.
2023-09-10 add simple memory dump to settings
    Button 12 in settings, up/down can be used to scroll through memory
    bytes.
2023-09-13 fix bug in memory initialization
    The DDRC register was written before the PORTC register when setting WE
    high in the setup_memory function. This causes WE to be driven low for a
    short period of time. At the point in time when this happens, the CE1
    and CE2 chip enable signals for the RAMs are still being driven low, so
    this actually causes a write to the memory.
    Make sure that the chip enable signals are driven high before setting
    WE, and also set WE with the correct sequence where PORTC is written
    before DDRC.
    With this fixed, put the magic words back to start at address 0.
    [main.c]
2023-10-02 io: midi: use interrupt for MIDI RX receive
    This is needed to guarantee that incoming data is not lost.
    Even with faster block allocations, data gets lost sometimes if
    it is just up to the task handler to determine who gets to run
    next.
2023-10-02 sample: use new tree based allocator
    Don't do a linear block search each time a block needs to be allocated.
    Instead use free bits in each block entry to implement a tree such that
    block allocations can be done in just 5 steps.
2023-10-02 sequencer: ignore length for DMC samples
    Just let DMC samples play until the sample is complete, or a new
    position in the sequence wants to play a new sample.
2023-10-02 ui: settings: add some convenience buttons in memory debugger
2023-10-02 tools: add tool for generating MIDI sysex files
    Adds a simple tool, gensysex, for creating sysex files to use with the
    NESizer2.
    An example script is added for how to convert a wav file into a loadable
    sample sysex file.
2023-10-09 midi: remove midi rx from midi_io_handler
    This is now handled by the dedicated interrupt for UART RX
2023-10-09 sample: make sure cached block state does not overwrite end-of-chain flag
    Fix a sneaky bug where the block state tree update part of
    allocate_block overwrites the newly set end-of-chain flag if the new
    block index is the same as one of the tree node indices.
    This would cause corrupt chains and cause trouble when deleting samples
    and then loading new ones.
2023-10-09 Makefile: -O2 and default to atmega328p MCU type
    Default to atmega328p as that is what is used in the BOM and probably
    used by most users.
    Use O2 optimization level. O3 has been used so far, but now flash space
    is getting tight. The critical part is guaranteeing that DMC sample
    playback gets to tick at approximately 16 kHz, which still seems doable
    with -O2.
2023-10-12 io: battery: improve ADC use
    Actually wait for the ADC conversion to complete by polling the
    ADSC register bit in the ADCSRA register.
    Remove magic sleep in main which is no longer needed when doing this.
    Also disable ADC after conversion is done.
    [battery.c, main.c]
2024-04-09 Support booting without 2A03 installed
    Support booting the NESizer without a 2A03 chip installed.
    To check for 2A03 presence, the interrupt on the PC3 (R/W) pin is
    enabled and used to count toggles on the line. Testing shows that on
    average a regular 2A03 (divisor 12) will cause the count to become ~110
    during a 10 us window. This value will be lower for chips with higher
    clock divisors, so the threshold is set to a count of 10 to keep a good
    margin. Since the pin will have an internal pull-up when configured as
    input, the test could probably have been that the count is non-zero, but
    to avoid any potential glitching when enabling the interrupt, checking
    for a value a bit higher than that ma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
    [2a03.c]
2024-04-15 fix all errors caught, to compile using VSCode
    [2a03.c, main.c]
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2024-06-22 fixed "parameter name omitted" compile error
    [2a03.c]
2024-10-04 big PR with all the new features (note stacking, CC param adjust, updated SysEx parsing, ProgramChange patch select, and small UI improvements) (#27)
    * Adding gitignore
    * Added midi CC support
    Updated gitignore
    Updates to the Midi cc range logic
    Update: Changed midi CC indexes
    Fixed: added MIDI_CMD_CONTROL_CHANGE to midi_channel_apply
    Match code style and move const to PROGMEM
    Moved const values to PROGMEM and formatting
    Fixed bugs in midi CC, added INVRANGE to control change, and made CC tables easier to read.
    Fixed negative range bug with setting parameter values from CC.
    First round midi toggles
    Updating midi cc
    Updated midi mapper and toggle for midi c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
    [main.c]

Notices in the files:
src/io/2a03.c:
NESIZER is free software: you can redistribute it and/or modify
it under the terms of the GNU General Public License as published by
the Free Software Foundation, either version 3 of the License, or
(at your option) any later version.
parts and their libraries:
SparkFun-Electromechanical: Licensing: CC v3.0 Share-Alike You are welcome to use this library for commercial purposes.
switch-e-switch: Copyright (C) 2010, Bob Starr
